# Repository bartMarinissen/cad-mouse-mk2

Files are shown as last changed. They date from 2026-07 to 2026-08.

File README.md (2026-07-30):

# CAD Mouse MK2 - The accuracy project.

This is a fork of the CAD Mouse MK2 project by SB-OCR.
The mouse as designed by him works out of the box, and is quite amazing. Except for one part: The motion tracking.

This project is an attempt to tackle this, and to bring the highest possible degree of accuracy to this mouse.
This degree of accuracy may be overkill. But why settle for less than the best you can get out of the hardware! (Note, if you do want to settle for less, there is a [[good enough]] trick below with already functioning code)

## The motion problem.
The bowels of this project are rather heavy on the mathematics. So we'll be stating the problem of trying to find the position of the knob in technical terms. We have 3 sensors arranged in a triangle. At rest, the magnets in the knob float about 6mm above those sensors. The magnets themselves are 6x6 cylinders (really they are 2 3x6 cylinders stacked on top of each other, but that doesn't matter). These 3 sensors measure the magnetic field in 3 directions, which yields 9 values. Based on these 9 values, we want to find a best guess for the 'pose' of the knob. Pose means both the position and orientation of the knob.
This is not an obvious problem. However, there is a related problem that is solvable. We call this one the forward problem.

"Given a pose $P$ of the knob, what magnet sensor readings should we expect".

If we can answer that question, then we can easily find the quality of a guess. We will then use some standard optmization techniques (the Newton-Gauss method) to find the best guess, or at least something very close to it. (Oh, and we want to do it at least 100 times a second on slow hardware that doesn't natively support floating point numbers) This leads to the real problem, also known as the backwards problem (because it goes the other way). in Plain langues, the question is: given the 9 magnet sensor readings, which pose of the knob best matches these readings".
To be precise, the backwards problem is:

"What pose minimizes the sum of the squares of the difference between the 9 sensor readings and the predicted sensor readings"

### Solving the forward problem
Awnsering the forward problem is pretty straightforward. We need to do two things: figure out the strength and direction of the magnetic field around a magnet. And then figure out how the pose of the sensor relative to that magnet. We can then figure out the field strength and direction of the magnetic field at the sensor, and how that direction aligns with the orientation of the sensor. The second part is 'just' some simple translations and rotations. (The bookkeeping gets complicated and tedious, but its not hard).

The first part, figuring out the strength and direction of the magnetic field around a magnet is a solved physics problem. So we 'just' need to poor that physics into some code. It turns out that this close to a magnet, the shape of the magnet actually matters so you can't solve it with a simple model (i.e. a dipole model). The exact solutions involve horrible things like closed form elliptical integrals. Not only are those annoying parts of math, they are also slow to calculate.

Instead of calculating the field strength fully from scratch, we precompute the field (and reduce it from 3D to 2D by exploiting the axial symmetry) at a few known places. Then when we want to know the field at an unknown place we interpolate between these known places.

In summary: figure out the pose of the sensor relative to the magnet. Then figure out the field strenth and direction at that position based on interpolating known data. Then figure out how the orientation of the sensor alligns with the magnetic field direction.

### Solving the backwards problem.
As stated, we use standard optimization techniques.

These are well researched, and they work quite well. The fast ones need:
- An initial guess
- A quick way to calculate the error (as a 9-element vector)
- The Jacobian of the error w.r.t the pose.
- (They need the error to behave 'nicely' as a function of the guess of the knob pose)

The initial guess is easy. Either take the rest position, thats good enough. Or even better, take your last guess for the knob position. The quick way to calculate the error is literally just the forward problem. We have that solved already.

But the Jacobian of the error? What even is that? Multi-variate calculus is what it is. The handwavy explanation is that it tells you how the error vector changes if you slightly change the guessed knob pose. More handwaving doesn't make sense, so I won't try.

To get this Jacobian, and for things to behave nicely. We need to do some math against out forward problem. This means we need the Jacobian of our interpolator, and we then need to use a whole lot of chain rule, product rule, and quotient rule (and some general linearity of the derivative) to turn that Jacobian into our final Jacobian. On top of that, we would really like for our Jacobian to vary smoothly with the guessed pose. This means we want our interpolator to not just be continuous, we also want it to be smooth. Hence we quickly land at some form of cubic splines. (The exact choise of spline is still under investigation)

These solvers then iteratively improve the guess for the pose by evaluating the current guess, and then using the Jacobian to estimate how best to reduce the error by changing the guess. They need a few iterations. And if the forward problem is well behaved (has no valleys or plateaus) then they get there very quickly. We expect at most 20 iterations, and hope for a lot less

### Performance
We need to solve the backwards problem 100s of times per second.
That means we need to solve the forwards problem close to 1000s of times per second.
That means performance matters.

More on that to come later.

### Calibration
We said the forward problem is easy. But its only easy if you know the details of your knob exactly. For now I am considering the following details salient, there is fractal amounts of detail here, so we need to draw a line somewhere:

- The magnet strengths (non-negotiable, this is the only way to find the Z axis data)
- The sensor sensitivity per axis. (They report a field strength in mT, but they are of by a fixed percentage)
- The sensor base offsets: The sensors don't read zero even if there are no magnets nearby, their offset is much larger than just the earths magnetic field)
- Sensor skew: the sensor axes aren't necessarily perfectly orthogonal.
- Errors in the magnet pose, and more especially rotation. (After all, this is 3d printed and the magnets are slip-fit)
- Errors in the sensor pose. (This is much less of a worry because PCBs are quite accurate)

Actually finding this is for another section. But we need to know these things so we can correct for them.

## Current state of the project
We have things working at about 50Hz using a single core based on bicubic interpolation.
There is very little callibration, and its hardcoded for my knob.
We get a residual of 4% Using the mouse it seems perfectly fine.

The code is a mess, its actively being modified, its not documented yet, most things are up for modification.

But smooth working at 50Hz and a 4% residual without callibration is already something I'm proud of!

## AI usage
There is heavy AI assistance. A lot of it for the tedium of getting the Jacobians. A decent amount of it for helping write the code. Most code starts out as AI generated and then gets shaped down to something I understand and agree with. Less critical code gets less attention. Especially if tests or experience just shows that it works.

## Build instructions
There are none for now. It should work out if you just use the instructions from the original.

At the moment, if you run into issues I'd love to help. Because it would be great to know someone else is using this. I do intend to add documentation 'later'. That is as much of a promise as you probably think it is (not a promise).

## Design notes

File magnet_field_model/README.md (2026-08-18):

# magnet_field_model

Offline Python for the magnetic side of the project: the field simulation that
generates the firmware's interpolation table, and the **bundle calibration**
that measures a specific unit's real geometry.

```
bicubic_table.py             the magnet model + grid the firmware's table is built from
generate_bicubic_table.py    entry point: (re)writes the firmware's table from bicubic_table.py
field_approximation.ipynb    inspection/visualization of that table - does not write it
bundle_callibration.py       entry point: capture a run, fit it, report
calibration/                 the calibration package (see below)
calibration_runs/            raw captured frames, as JSON
tests/                       pytest suite, one file per module - run after touching any math
```

## Running it

```bash
uv sync
uv run python generate_bicubic_table.py                    # (re)write the firmware's field table
uv run python bundle_callibration.py                       # live capture over serial
uv run python bundle_callibration.py --replay calibration_runs/raw_*.json
uv run python bundle_callibration.py --replay <run> --emit-cpp   # + firmware constants
uv run --group dev python -m pytest tests/ -q
```

A fit over a captured run is interactive -- seconds, not minutes.

## What bundle calibration is for

The knob has 3 magnets over 3 Hall sensors. The firmware infers pose by
inverting a magnetic forward model that assumes *nominal* geometry. Real
hardware misses nominal: a magnet sitting 0.2mm off, or a sensor 5% more
sensitive, looks to the solver like the knob moved. That is the "Phantom
Tilt" problem this fork exists to fix (see `../ARCHITECTURE.md`).

Calibration recovers, per unit:

| Group | Meaning |
|---|---|
| `magnet_pos` | in-plane shape of the magnet triangle (mm) |
| `magnet_tilt` | magnet axis tilt (rad) |
| `magnet_strength_mean` | common-mode polarization multiplier |
| `magnet_strength_diff` | how much individual magnets differ from it |
| `sensor_offset` | DC offset on the raw reading (mT) |
| `gain_aniso` | per-axis sensitivity spread |
| `gain_sym` | cross-axis skew |
| `gain_rot` | sensor frame misalignment |

Each group's size, and the flat vector's layout, is declared by `BLOCKS` /
`GROUP_SLICES` in `parameterization.py` — read the count there rather than
from a total written down here. Together with one free 6-DOF pose per captured
frame this is a bundle adjustment, in the photogrammetry sense. There is
deliberately no isotropic/scale gain parameter; see the gauge note below for
why sensor gain and magnet strength don't compete for the same degree of
freedom.

## Package layout

```
local_field.py         one magnet's axisymmetric field + its 3x3 gradient
nominal_geometry.py    pure nominal/CAD constants (no other package dependencies)
parameterization.py    the calibration parameter layout: how the flat vector scipy
                        sees maps to physical offsets (ParamBlock, GROUP_SLICES, assemble())
bundle_geometry.py     BundleGeometry: physical geometry + forward model + analytic Jacobian
bundle_params.py       priors, residual weighting, BundleCalibrationProblem, covariance
pose_solver.py         batched Levenberg-Marquardt: every frame's pose at once
calibration_algorithm.py  the fit that drives all of the above (single joint solve)
export.py              fitted geometry -> firmware constants
report.py              fitted result -> the Rich content the TUI and CLI show
protocol.py / serial_link.py / session.py / collector.py / tui.py   capture side
```

## Design notes

**Analytic Jacobian.** Every derivative in `bundle_geometry.py` is the same
closed-form chain rule the firmware uses in
`firmware/src/magnet_model/virtual_sensor.cpp`, layered on the local field gradient
from `local_field.py`. The previous version finite-differenced the entire
shared vector per frame — tens of thousands of magpylib calls per solver
iteration. `tests/test_jacobian.py` checks every derivative against central
differences, mirroring `firmware/test/test_jacobian.cpp`.

**Weighting.** A sensor's reading varies over nearly an order of magnitude
across a run, and the error budget is part absolute (read noise, measured on a
stationary knob) and part relative (unmodelled field-shape error) — the two
constants are declared on `ResidualWeights` in `bundle_params.py`. A flat
sigma therefore lets the close-to-the-magnet frames dominate.
`ResidualWeights` uses `hypot(absolute, relative * |B|)` per sensor per frame,
keyed off the **measured** magnitude — a weight that depended on the prediction
would bias the fit toward shrinking |B|.

**Single joint solve, not staging.** Every shared parameter is freed at once,
in one `least_squares` call. An earlier version froze parameters in a
warm-started ladder (gain scale and DC offset → magnet geometry → the weak
cross-axis gain terms) on the theory that a cold start needed the help.
Ablated against real and synthetic data — checking recovered parameters, not
just residual level, since a bad local optimum can still
converge to a low residual — a single unstaged solve reaches the same optimum
every time. `SolveStage`/`BundleCalibrationProblem.build_problem` still exist,
purely as a way to isolate a parameter subset for testing (e.g. "fit only
magnet strength, holding everything else at nominal").

**No isotropic gain term, ever.** Sensor gain scale and magnet strength
describe the same thing from opposite ends: a sensor reading 5% high and its
magnet being 5% strong differ only through cross-talk, which is a small
fraction of the signal and comparable to the model error
(`../TODO/resolved/cross-magnet-interference.md` owns that measurement). An earlier
version fixed this with a runtime pass — freeing an isotropic `gain_iso`
parameter and then transferring it into strength via a final `det(G)=1`
renormalization stage. That machinery is gone: `GAIN_BASIS`
(`parameterization.py`) is now built only from basis matrices that are exactly
traceless — asserted at import time, so the property is enforced rather than
documented — giving `det(I + A) = 1 - tr(A²)/2 + det(A) ≈ 1` for *any*
parameter value, automatically, to second order — good to the same precision
the old runtime transfer already tolerated. There is no competing scale
parameter for `magnet_strength` to wait behind, so it is free from the start of
the (single) solve, not a final phase.

**Pose solving.** Every frame's pose is solved in one batched
Levenberg-Marquardt rather than a Python loop, since the frames are
independent. A cold start occasionally drops a single frame into the wrong
basin — near a magnet and well tilted, the residual surface has a second
minimum a few degrees away — so any frame ending far worse than its peers is
retried from a spread of starting orientations. `converged` reflects the final
residual, not the damping factor: `calibration_algorithm.py` only fits frames
that passed this gate (evenly decimated down to a runtime cap — see
`DEFAULT_N_FRAMES` — not selected for diversity; a farthest-point frame
selector used to run here, but frame choice barely affects the result, so it
was deleted rather than kept for a benefit that wasn't there). The cap exists
because fitting every captured frame costs orders of magnitude more solver
time, at a much larger problem dimension, for no accuracy that ablation could
detect: the limit is systematic model error, not sample noise.

**Reported uncertainty.** Each frame's 6 pose parameters touch only that
frame's 9 residuals, so the pose block of the normal equations is
block-diagonal, and its contribution to the shared-parameter covariance can be
eliminated (the Schur complement). `BundleCalibrationProblem.covariance_shared`
computes this as `inv(J.T @ J)[:p, :p]` — a plain dense inverse sliced to the
shared block, reusing the same Jacobian the solver itself trusts, mathematically
identical to a hand-rolled per-frame elimination but far simpler at this
problem's actual size (a few hundred to a couple thousand unknowns, well under
a second). Reported as *information gain* = `1 - posterior/prior`. Low values
are not a bug — they mark parameters the data barely constrained, which is the
difference between measured and assumed.

## Assumptions

Recorded explicitly, because several are load-bearing:

1. **Magnet position reference is the BOTTOM FACE, not the centre.**
   `bicubic_table.py`'s `build_magnet()` places the cylinder at `z=+3` so its
   bottom face lands on `z=0`, so that is what `positions.h`'s magnet
   positions mean. magpylib positions a cylinder by its centre, so
   `local_field.py` adds the half-height. Getting this wrong shifts the model
   by that half-height and inflates the predicted field severalfold at rest —
   it is not a subtle error, but it is a silent one.
2. **The raw sensors' sign flip is attributed to magnet polarity, not gain.**
   The capture path streams `readUncorrected()`, and the raw sensors read the
   opposite sign to the field `local_field.py` models. The firmware carries
   that in `Config::magnet_gains` (see `Config.h` for the values); here
   `MAGNET_POLARITY = -1` carries it instead, so `local_field.py` stays a
   direct counterpart of the firmware's table and both fitted quantities read
   naturally (gain near `+I`, strength near `1`). The exported firmware gain
   still lands near `-I`. Which physical cause is the real one — magnets
   installed north-down, or an inverted sensor axis convention — does not
   matter to the fit, since a global sign is equivalent either way.
3. **Sensor positions are fixed, not calibrated.** They define the world
   frame. Real sensor placement error is absorbed by the magnet position
   offsets, which are related to it by a per-frame pose anyway.
4. **Magnet strength is split into common mode and differential, and the
   common mode carries no prior at all.** A prior would have to be centred on
   `local_field.py`'s nominal polarization (`MAGNET_POLARIZATION_MT`), which
   is a round guess rather than a measurement of these magnets — asserting a
   belief nobody holds, and
   dragging the fitted field scale toward an arbitrary number. So it is left
   free and reported with its own posterior sd.

   The consequence is the important part: **the data does not determine the
   absolute field scale.** Its posterior sd is wide enough that the fitted
   value sits inside 1σ of nominal, and the residual barely moves across that
   whole range. The direction is very nearly flat, because a uniform scale
   change is largely absorbable by every frame's pose moving further away, and
   only the shape of |B| versus distance breaks it — over the few mm of heave
   the mechanism allows, only barely. **Read the fitted strength as
   "unconstrained", not as a measurement of how strong the magnets are.**
   Dropping the prior did not reveal a better value; it revealed that there
   was never one to reveal.

   The *differential* part keeps its prior, because that justification is
   independent of the nominal figure: it says magnets cut from one batch are
   graded to roughly that of each other, which is a real belief about the
   parts. Empirically the constraint is nearly free — sweeping it over three
   orders of magnitude barely moves the residual, so per-magnet differences
   were never explaining much. The apparent per-sensor spread is accounted
   for by magnet position and DC offset instead.

5. **DC offset is applied on the raw side, after gain.** It is a property of
   the raw reading (Hall zero-point plus ambient field), not of the modelled
   field, so `pred = G @ B_model + offset`. The firmware subtracts its offset
   *after* gain instead, so the export maps `o_fw = G_fw @ o_fit`.
6. **Magnet spin about its own axis is not a parameter.** A uniformly
   axially-polarized cylinder is a solid of revolution, so that rotation is
   unobservable for *any* dataset — a structurally dead direction rather than
   a poorly-measured one. Tilt carries 2 DOF, not 3.
7. **The pose gauge is fixed explicitly, not by priors.** A global
   translation or rotation of the magnet trio is exactly cancelled by a
   compensating per-frame pose change — `mⱼ → Q mⱼ` with `R_n → R_n Qᵀ`
   leaves `R_n Qᵀ Q mⱼ = R_n mⱼ` untouched — so 6 of the 9 raw magnet
   coordinates carry no information at all — they show up as eigenvalues at
   machine zero in the reduced Hessian, at every frame count tried. No dataset
   fixes this; each new frame brings 9 equations but also 6 new pose unknowns.

   `MAGNET_POS_BASIS` removes them by construction, via three constraints:
   zero mean offset (kills translation), all z offsets equal (makes the
   triangle's plane horizontal, killing pitch and roll), and zero net yaw
   moment (kills twist, symmetrically rather than by pinning an edge). The
   flat constraint costs nothing — three points are always coplanar, so any
   arrangement can be rotated flat and the plane's tilt is pure gauge.

   What survives is 3 parameters: the triangle's in-plane shape, i.e. its
   three side lengths, which is the only part that can cause Phantom Tilt.
   Magnet tilts keep all 6 DOF, measured against the frame the flat triangle
   defines. (The rotation gauge is *shared* between positions and tilts, so
   it can be spent on either — fixing roll/pitch via mean tilt instead would
   give 5 position + 4 tilt. Total observable is 9 either way; only the
   presentation differs.)

   Two things this bought. Conditioning: the reduced Hessian goes from
   numerically singular to comfortably invertible. And frame count starts to
   matter at all — with priors off, cross-run spread now improves with more
   frames at close to the rate pure averaging predicts, where before the gauge
   fix it was flat. Null directions cannot be out-voted by data; merely weak
   ones can.

8. **Gain is fitted on the model side, exported inverted.** See
   `export.py` — the firmware applies gain to the raw measurement, this fit
   applies it to the model, so the exported matrix is the inverse (with
   `MAGNET_POLARITY` folded back in, landing near `-I`).

## Reading the fitted numbers

The fit's own report is the authority on what a given run achieved — residual,
posterior sds, and per-group information gain are printed for the run in front
of you rather than written down here, where they would rot.

Reading them: reproducibility is not the same as identifiability. The weakly
determined directions (magnet z-offset against gain scale, in particular)
reproduce consistently because the *prior* resolves them the same way every
time, not because the data measured them. The information-gain column is what
distinguishes the two, and a low value there is not a bug — it marks a
parameter the data barely constrained.

## Still open

- The `/calibration.bin` layout is no longer duplicated:
  `calibration/firmware_struct.py` extracts the `CalibrationParams`
  declaration straight out of `firmware/include/CalibrationParams.h` and hands
  it to cffi, so `format_binary()` fills the struct by field *name* and the
  order is only ever stated in the header. `tests/test_export.py` pins the
  resulting offsets and compiles the same extracted declaration with g++ to
  check cffi's ABI model against a real compiler. Both still only describe the
  *host* — the firmware's own `static_assert`s are what pin the target, and
  nothing here has run on hardware yet.
- Running the fit on the knob itself. The analytic Jacobian this needs is
  already here, and the firmware has the same chain rule in `virtual_sensor.cpp`. An
  on-device solve would need an O(n_frames) per-frame Schur elimination
  driving the actual solve (not just the reporting-only covariance
  `covariance_shared` computes today via a plain dense inverse, which is
  simpler at this problem's desktop-scale size but not embedded-friendly) —
  see git history for a prior implementation of that reduction. The storage
  half of that is done: a result fitted on the knob would have somewhere to
  land, via `CalibrationStorage`.
- Magnet strength stays weakly determined — its information gain is among the
  lowest in the fit. Scaling a magnet and moving it closer both scale |B|;
  only the shape of |B| versus distance separates them, and the HEAVE step
  supplies just a few mm of travel to do it with. More Z range would help, but
  the mechanism limits how much is available before the magnet leaves the
  modelled region.
- The `magnet_pos` prior is now optional rather than load-bearing. With the
  gauge fixed explicitly, dropping it entirely barely moves the cross-run
  spread and leaves the residual unchanged. It is kept (at the width declared
  in `priors.py`) because the knob is 3D printed and a few tenths of a
  millimetre is a well-founded statement about that process — unlike the
  nominal polarization figure. It is now a belief the fit could do without,
  which is the point of fixing the gauge properly, but it earns its place.
- The absolute field scale is not measurable from this capture — its posterior
  sd is a large fraction of the value itself. If it is worth knowing — and it
  would tighten the z sensitivity of the whole pose solve — it needs either
  much more heave travel
  or an independent measurement of one magnet's remanence. Note the boot tare
  cancels a systematic z bias, so the practical cost of getting it wrong is
  mostly a slightly mis-scaled z axis, not an offset.

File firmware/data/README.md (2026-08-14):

# `firmware/data/` — LittleFS image source

PlatformIO's `data_dir` (see `platformio.ini`). Everything in here gets built
into the LittleFS image that `pio run -t uploadfs` flashes onto the device.

The directory is tracked but its one real payload, `calibration.bin`, is not:
it is fitted per physical unit, so committing one would ship a single device's
calibration to every checkout. `.gitignore` in this directory keeps it out.

## Flashing a calibration this way

```bash
cd magnet_field_model
uv run python bundle_callibration.py --replay calibration_runs/raw_<run>.json --emit-bin
cd ..
pio run -t uploadfs
```

`--emit-bin` defaults to writing `firmware/data/calibration.bin`. It is
byte-for-byte the same blob the serial upload path sends, so both routes
produce a file the firmware reads identically — see
`firmware/include/CalibrationStorage.h` for the size and layout.

## The other route

`uploadfs` rewrites the whole filesystem and needs a rebuild-and-flash cycle.
To push a calibration to a device that is already running, use
`bundle_callibration.py --write-serial` instead: trigger a tare on the knob
(hold both buttons ~3s), and the script sends the same bytes over the wire
when the device announces `STATUS TARE_BEGIN`. The device validates, stores,
and reboots to pick it up.

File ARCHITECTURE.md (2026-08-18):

# CAD Mouse MK2 (accuracy fork) — Architecture Notes

Working reference for navigating and reasoning about this codebase. Written from
reading the code directly (not from any doc that could drift), so re-verify
specifics (function names, line numbers) before relying on them if it's been a
while — see `design documentation/context.md` for the *why*, this file is the
*where/how*.

**The repo root `README.md` is the maintainer's personal file, off-limits to
edits from this doc's audit/consistency-keeping loop** — it may be out of date.
That is not your problem to solve. And be careful with relying on it to be up to date.

## What this project is

A 6-DOF magnetic 3D mouse (fork of `sb-ocr/cad-mouse-mk2`): a knob embedded with
3 axially-polarized cylindrical magnets sits above 3 fixed Hall-effect sensors on
a PCB. Firmware infers the knob's full pose (X/Y/Z + pitch/roll/yaw) from the raw
magnetic field and reports it to the host as a USB HID multi-axis controller
(3Dconnexion-style), for CAD navigation.

The upstream project mapped raw field strength to position with a naive linear
heuristic. This fork rips that out and replaces it with a real magnetic
forward model + Gauss-Newton solver, because field strength doesn't map
linearly to distance.

## Three top-level areas

```
firmware/            PlatformIO/Arduino C++ — the actual product firmware
magnet_field_model/  Python (uv-managed) — offline field simulation + codegen
enclosure/           Fusion 360 / STEP / STL — mechanical design, not code
```

`platformio.ini` at repo root points PlatformIO at `firmware/{src,include,lib,test}`.
Board: Seeed XIAO RP2040 (dual-core Cortex-M0+, **no hardware FPU** — all float
math is software-emulated, which is why solver perf tuning matters: `-O2`,
`-fassociative-math`/`-freciprocal-math`/etc. relaxed-fp flags, `EIGEN_NO_MALLOC`
to force fixed-size Eigen types only, no heap allocation anywhere in the hot path).

## Firmware: control flow

`firmware/src/main.cpp` is the entry point. `setup()` brings up controllers in a
fixed order (HID → serial → input → LED → sensors → motion → telemetry), then
`stateMachine.changeState(&calibratingState)`. `loop()` calls
`hidController().task()`, then `serialController().update()` to assemble any
incoming serial line, then `stateMachine.update()` — a classic non-blocking
super-loop, no RTOS.

### State machine

[`firmware/include/State.h`](firmware/include/State.h) — trivial interface:
`enter()/update()/exit()`.
[`firmware/include/StateMachine.h`](firmware/include/StateMachine.h) /
[`.cpp`](firmware/src/StateMachine.cpp) — holds one `currentState*`, calls
`exit()`/`enter()` on transition. States are **static members of StateMachine**
(singletons, no dynamic allocation).

States, all in `firmware/{include,src}/states/`:

- **CalibratingState** — the tare step. Runs at boot and on the both-buttons-3s
  gesture from `IdleState`. Drives `SensorController::updateCalibration()` for
  `Config::ZERO_SAMPLES` (200) samples to compute a baseline field offset and a
  baseline pose, then hands off to `IdleState`. Also the *only* place serial
  commands are accepted: it announces `STATUS TARE_BEGIN` on entry, then honours
  `CAL_START` (enter `BundleState`) and `CAL_UPLOAD` (store a new calibration;
  `CAL_ABORT` leaves a run without storing, and is handled in `BundleState`)
  for the ~1.7s the tare lasts.
  [`TODO/tare-and-calibration.md`](TODO/tare-and-calibration.md).
- **IdleState** — the main operating state. Reads sensors → runs the pose solve →
  maps to HID axes → sends HID report → publishes telemetry → watches for the
  calibration-request gesture and the inactivity timeout to `SleepState`.
- **SleepState** — LEDs off, waits for any button activity to return to `IdleState`.
- **ErrorState** — entered if `SensorController::begin()` fails at boot. LED
  spinner in red, otherwise inert (no recovery path).
- **BundleState** — This is where actual callibration happens. We use bundle
  callibration and taring was called callibration. Hence the bad name. 
  This hosts the serial-driven multi-step hardware calibration
  routine (see "Calibration subsystem" below). Entered only from
  `CalibratingState` on `CAL_START`; `enter()` kicks the run off directly,
  since the command that got it there was already consumed.

### Controllers (global singletons, reached through accessors in `Controllers.h`)

Declared in [`firmware/include/Controllers.h`](firmware/include/Controllers.h)
and defined in `Controllers.cpp`. This is the project's entire DI mechanism —
there is no container, no interfaces, states and controllers reach each other
through these accessors directly.

**No controller owns another, and that is the whole ownership rule.** Every
controller is reached through its `Controllers.h` accessor, by states and by
other controllers alike; a controller calling a sibling's accessor is the
sanctioned pattern, not a coupling smell. There is no dependency hierarchy to
respect and nothing to invert. What is *not* allowed is bypassing the
accessors.

| Controller | File | Responsibility |
|---|---|---|
| `InputController` | `controllers/InputController.*` | Debounces 2 buttons via AceButton; exposes `buttonBits()`, `takeActivity()` (edge-triggered, consumed on read), `takeCalibrationRequest()` (both buttons held 3s) |
| `LEDController` | `controllers/LEDController.*` | NeoPixel ring: owns one `std::variant`-held `AnimationBase` slot (`animations/`) plus power management; callers `set()` a `SolidAnimation`/`SpinnerAnimation`/`OffAnimation`/`PoseColorAnimation` and drive it with `update()` each tick |
| `SensorController` | `controllers/SensorController.*` | Owns the 3 TLx493D sensor objects, power-sequences them onto distinct I2C addresses at boot, `readUncorrected()`/`read_mT()` → 9 floats, applies gain + DC offset, runs the boot baseline calibration |
| `MotionController` | `controllers/MotionController.*` | The pose pipeline: raw field → solved pose → filtered/mapped HID axes (detail below) |
| `HIDController` | `controllers/HIDController.*` | Owns the USB HID descriptor + report state, dedupes unchanged reports before sending |
| `TelemetryController` | `controllers/TelemetryController.*` | Formats a big fixed-layout ASCII dashboard to Serial every 20 ticks when `Config::ENABLE_TELEMETRY` |
| `BundleCalibrationController` | `controllers/BundleCalibrationController.*` | Serial-driven state machine for the guided hardware calibration capture |
| `SerialController` | `controllers/SerialController.*` | Assembles incoming bytes into whole lines without blocking; `takeLine()` hands the active state one line per tick. Transport only — command meaning stays with the caller, and outbound prints still go to `Serial` directly |

### Sensor read timing

The three TLI493D-A2B6s are **not** in their power-on-reset Low Power Mode
(160 Hz, ~6.25ms worst-case staleness). `SensorController::setup_sensor()`
puts each into **Master-Controlled Mode** (`setPowerMode`) with
**trigger-on-read** (`setTrigger(TLx493D_ADC_ON_READ_AFTER_REG_05_e)`), so
every `getMagneticFieldAndTemperature()` both returns the previous
measurement and re-arms the next conversion. Reading the three back-to-back
therefore costs about one I2C round-trip of staleness rather than a fixed
conversion period. The PCB forces this: all three `SCL/INT` pins share one
net wired only to the MCU's plain `SCL`, so there is no `/INT` line to
synchronize on and it has to happen over the bus itself.

worth knowing: **Self-triggering only works if reads keep happening.** After a >100ms gap
  the armed conversion is stale, so `readUncorrected()` throws away one round
  purely to re-trigger before reading for real. Bus stays at 400kHz
  deliberately; Master-Controlled Mode doesn't need Fast Mode, and raising it
  risks signal integrity across three sensors on fixed 1.2kOhm pull-ups.

The derivation behind this — datasheet rates, why the shared `SCL/INT` net
rules out interrupt-driven sync, why trigger-bits `100B` specifically — is
archived in
[`TODO/resolved/sensor-read-speed.md`](TODO/resolved/sensor-read-speed.md).

## The pose pipeline (the core of the project)

Entry point: `MotionController::compute()` in
[`MotionController.cpp`](firmware/src/controllers/MotionController.cpp), called
once per `IdleState::update()` tick.

```
SensorController::readRaw()          9 raw floats (3 sensors × xyz, mT)
        │
        ▼
MotionController::read_pose()        hot-started from last frame's (t, R)
        │
        ▼
solve_knob_pose()                    Levenberg-Marquardt Gauss-Newton, ≤10 iters
   (solve_pose.cpp)                  6x6 normal equations each iteration
        │  each iteration calls:
        ▼
ForwardModel::evaluate(t, R)         places each magnet in the world once,
   (forward_model.cpp)               then loops the 3 sensors
        │  per sensor, all 3 magnets:
        ▼
VirtualSensor::evaluate(...)         paired magnet via the interpolated field
   (virtual_sensor.cpp)              below; the other 2 via dipole_field().
        │                            Sums both, then composes the 3x6
        │                            Jacobian analytically once.
        ▼
MagnetModel::evaluate(v_local)       cylindrical (r,z) decomposition of the
   (magnet_local_model.cpp)          local offset, handles r→0 singularity
        │                            (paired magnet only)
        │
        ▼
BicubicField::evaluate(r, z)         Catmull-Rom bicubic interpolation over a
   (BicubicField.cpp)                51×91 precomputed grid, with ghost-point
        │                            linear extrapolation just past the edges
        ▼
BICUBIC_INTERPOLATION_TABLE          generated hex-float constants
   (magnet_model_table.cpp)          (see codegen pipeline below)
```

Output of the solve is `(position, rotation matrix)`; `extract_angles_robust()`
converts `R` to Euler angles with gimbal-lock handling. `compute()` then:
subtracts the calibration baseline pose, applies `Config::SIGN_AXIS` /
`Config::GAIN_T` / `Config::GAIN_R`, dead-zones, low-pass filters
(`Config::SMOOTH_TAU_S`), clamps to `Config::AXIS_LIMIT`, and writes the 6 HID
axis values.

**Why the Jacobian is hand-derived everywhere:** the solver needs a 9×6
Jacobian *every iteration*, and this runs on an FPU-less M0+, so it's all
closed-form analytic differentiation chained through each layer (no
finite-difference in the hot path). `firmware/test/test_jacobian.cpp` is a
Unity test suite that validates every one of these analytic Jacobians against
central finite differences — this is the safety net for that whole chain, run
it after touching any `evaluate()` in `magnet_model/`.

Geometry constants (sensor/magnet positions, triangle side length, 6mm z-standoff)
live in [`positions.h`](firmware/include/magnet_model/positions.h). Physical
constant: `#include "math3D.h"` for `Vec3`/`Mat3`/`skew_matrix` typedefs
(thin Eigen wrapper, `ArduinoEigenDense`).

### Codegen: Python → firmware table

`magnet_field_model/bicubic_table.py` (uv-managed Python env, `magpylib` for
ground-truth field simulation of a real 6×6mm N52 cylinder magnet) samples the
true field on the same 51×91 (r,z) grid defined by `NR`/`NZ` in
[`magnet_model_table.h`](firmware/include/magnet_model/magnet_model_table.h).
Run `magnet_field_model/generate_bicubic_table.py` to actually (re)write that
header and the hex-float C++ array in
[`magnet_model_table.cpp`](firmware/src/magnet_model/magnet_model_table.cpp) —
it imports the magnet/grid definitions from `bicubic_table.py` rather than
duplicating them. `field_approximation.ipynb` imports the same module to
inspect/visualize the table (field plots, dipole-approximation comparison,
interpolation error); it no longer writes the firmware files itself.
**The `magnet_model_table.cpp` file is generated, not hand-written** — if the magnet spec, grid bounds
(`BICUBIC_ORIGIN`/`BICUBIC_FAR` in `magnet_model_table.h`), or grid resolution
change, they need to change in both the notebook and the header in lockstep, by
hand. There's no build-time codegen step; it's a manual copy-paste pipeline.

## Calibration subsystem — two independent layers

**1. Tare (`CalibratingState`, always runs):** Measures the resting pose as 
a reference to report the movement of the knob.

**2. Bundle calibration (`BundleState` / `BundleCalibrationController`, new):** 
a guided multi-step capture routine intended to solve the
Phantom Tilt problem via bundle adjustment. Step sequence:
`STATIONARY → FLAT_CIRCLE → PITCH → ROLL → TWIST → HEAVE → RANDOM → COMPLETE`.
Each step is a little sub-state-machine (`CalibPhase`:
`WAIT_FOR_START_BTN → COUNTDOWN → RECORDING → WAIT_FOR_ACK`) that streams
`CAL_FRAME`/`CAL_STATE` lines over Serial to a host script,
[`bundle_callibration.py`](magnet_field_model/bundle_callibration.py), which
ACKs frame counts back over the same link. A successful ACK moves straight on
to the next step.

**Status: capture, fit, and delivery all work.** The Python side fits a set of
shared parameters (per-magnet position, tilt and strength; per-sensor gain
matrix and DC offset) jointly with one free 6-DOF pose per captured frame,
taking the field residual down by most of an order of magnitude against
nominal geometry, in about a second. The parameter groups and their sizes are
declared by `BLOCKS`/`GROUP_SLICES` in
`magnet_field_model/calibration/parameterization.py`.  See
[`magnet_field_model/README.md`](magnet_field_model/README.md) for the
architecture and the load-bearing frame conventions.

Two things are worth knowing before touching it:

- The magnet position reference is the magnet's **bottom face**, not its
  centre — that is what `positions.h` means and what the notebook baked into
  the bicubic table. magpylib positions cylinders by their centre.
- The raw capture path streams `readUncorrected()`, so the sensors might read the
  **opposite sign** to the modelled field — matching `Config::magnet_gains`
  . The fit attributes that flip to magnet polarity,
  so fitted gains read near `+I` while the *exported* ones land near `-I`.
- Sensor gain scale and magnet strength are not separable (only a few percent
  cross-talk distinguishes them), so the fit picks a gauge: `det(G) = 1`, with
  magnet strength carrying the scale. The reported strengths are an
  attribution, not a measurement — the fit's information-gain column says so.

### Persistence

Fitted calibrations reach the firmware on their own. The whole fitted
parameter set is one struct,
[`CalibrationParams`](firmware/include/CalibrationParams.h), and
[`CalibrationStorage`](firmware/include/CalibrationStorage.h) persists it to
LittleFS as `/calibration.bin`: 312 bytes of `CMK2` magic, a version, the
struct's own 300 bytes, and a CRC-32 over everything before it.

Reading one is a `memcpy` — check magic, version and CRC, copy the payload into
the struct, then range-check it. That works because `CalibrationParams` is
**plain arrays rather than Eigen types**, which buys three things at once:
`memcpy` into it is defined behaviour (`Eigen::Matrix` has a user-provided copy
constructor, so a struct of `Mat3`/`Vec3` is not trivially copyable), `sizeof ==
300` is a language guarantee instead of an observation, and the layout can be
**row-major** to match numpy rather than the column-major Eigen would impose —
a transposed gain matrix passes both the CRC and every plausibility check, so
that ordering is worth pinning down. Consumers convert with `toMat3()`/
`toVec3()` at construction, where they already copied the values out.

`board_build.filesystem_size` in `platformio.ini` carves out the partition —
without it the filesystem is 0MB and nothing mounts.

`SensorController` and `MotionController` are constructed from that struct and
hold their calibration-derived state `const`, which is why they are no longer
static-init globals — each is reached through its own Meyers-singleton
accessor, `sensorController()`/`motionController()`, built on first call from
`resolveCalibration()` (see [`Controllers.h`](firmware/include/Controllers.h)).
Every other controller is trivially default-constructible and has no such
dependency, so it gets a plain accessor over a static-init global instead —
same construction as before, just reached through a function for uniform call
syntax across all eight controllers. `resolveCalibration()` in
`Controllers.cpp` reads and validates the stored blob, falling back to
`Config::defaultCalibration()` — and printing which check failed — whenever
there is nothing stored or what is stored does not survive.

Validation is deliberately all-or-nothing, and that follows from the gauge
note above: `sensor_gain` and `magnet_strength_mT` are the same degree of
freedom under `det(G) = 1`, so a blob is accepted whole or rejected whole.
Nothing repairs or defaults an individual field while keeping the rest, which
would silently manufacture a mixed-gauge calibration worse than either input.
Past the CRC the checks are loose corruption tripwires — finite floats,
non-singular gain, sane magnitudes — sized to admit both that gauge and
`defaultCalibration()`'s different gain-carries-scale one. Magnet strength is
bounded on magnitude only: a reversed-polarity magnet legitimately fits to a
negative `Br`, and `MagnetModel` handles the sign correctly.

Two routes in, the same bytes either way:

- **`bundle_callibration.py --emit-bin`** writes the blob into `firmware/data/`;
  `pio run -t uploadfs` flashes it as a filesystem image.
- **`bundle_callibration.py --write-serial`** pushes it to a running device as
  one hex-encoded `CAL_UPLOAD` line. Hex rather than raw binary so it rides the
  same newline-delimited convention as everything else on this link — raw bytes
  would contain `0x0A` and truncate the read. The device validates, stores, and
  reboots, since the controllers hold their calibration `const` from boot and
  cannot adopt a new one in place.

The host never restates that layout. `calibration/firmware_struct.py` extracts
the `CalibrationParams` declaration from the header and feeds it to cffi in ABI
mode (no compiler at runtime), so `format_binary()` fills the struct by field
name and `sizeof` comes from the declaration rather than a literal. Field order
therefore lives in exactly one place. This matters because a wrong order is
silent: it still yields a valid blob with a valid CRC, and a *reordered* struct
is even the same 300 bytes — so `tests/test_export.py` pins the field offsets,
not just the size.

**The knob holds after capture.** Finishing the last pose moves it to
`AWAITING_UPLOAD` rather than back to `IdleState`: the host is about to solve
and hand a calibration straight back, and making the user walk the knob into
calibration mode again to receive it was the wrong shape. `CAL_UPLOAD` is
therefore accepted in `BundleState` as well as during tare.

**Storing is still a decision, not the only exit.** Capture and fit never touch
flash by themselves, and `CAL_ABORT` returns to idle without writing — also the
only escape from a run whose host went away, since `WAIT_FOR_ACK` otherwise
times out back to `WAIT_FOR_START_BTN` forever. The host sends it when
`--write-serial` was not passed (nothing is coming back, so the knob should not
be left parked) or when the user declines the write prompt.

Two caveats on the exported numbers:

- `MagnetModel` now carries a `magnet_strength_mT` — a real polarization value
  in mT, not a dimensionless multiplier — and applies it in `evaluate()`,
  scaling the six cylindrical quantities before the x/y decomposition (exact,
  since the field enters linearly downstream). The ratio it actually multiplies
  by is `magnet_strength_mT / BICUBIC_FIELD_REFERENCE_MT`
  (`magnet_model/magnet_model_table.h`): the polarization
  `magnet_field_model/bicubic_table.py` generated the table at, currently
  1000 mT and arbitrary — any magnet's real Br divided by it gives the right
  scale regardless of what that reference happens to be.
- Every sensor sees every magnet. Its own is evaluated through the
  interpolated field above; the other two, ~28.58mm away and worth 1.7–4.5%
  of the signal, through `dipole_field()`'s point-dipole approximation. The
  Python fit models the same three-magnet physics
  (`calibration/bundle_geometry.py`'s `SENSOR_MAGNET_COUPLING = ALL_MAGNETS`),
  so the fitted magnet strengths mean what they say rather than absorbing a
  cross term the firmware could not reproduce. The two are not bit-identical:
  the fit uses the exact cylinder solution where the firmware approximates,
  a difference under 0.02% of the field. See
  `TODO/resolved/cross-magnet-interference.md`.
- `VirtualSensor` no longer carries a gain; correction happens entirely in
  `SensorController::read_mT()` (issue #6 below).

## Quick file index

| Looking for... | Look in |
|---|---|
| Pins, gains, dead zones, LED colors, timing | `firmware/include/Config.h` |
| Board/build flags, lib deps | `platformio.ini` |
| Sensor geometry / knob geometry constants | `firmware/include/magnet_model/positions.h` |
| The Gauss-Newton solver loop | `firmware/src/magnet_model/solve_pose.cpp` |
| Per-sensor analytic Jacobian | `firmware/src/magnet_model/virtual_sensor.cpp` |
| Cylindrical magnet field model + r→0 handling | `firmware/src/magnet_model/magnet_local_model.cpp` |
| Bicubic grid interpolation | `firmware/src/magnet_model/BicubicField.cpp` |
| Generated field table (don't hand-edit) | `firmware/src/magnet_model/magnet_model_table.cpp` |
| Field table generator (run this to regenerate) | `magnet_field_model/generate_bicubic_table.py` |
| Field table magnet/grid definition (source of truth) | `magnet_field_model/bicubic_table.py` |
| Field table inspection/visualization (does not write it) | `magnet_field_model/field_approximation.ipynb` |
| HID descriptor / report format | `firmware/src/controllers/HIDController.cpp` |
| Serial diagnostics dashboard | `firmware/src/controllers/TelemetryController.cpp` |
| Jacobian correctness tests (finite-difference) | `firmware/test/test_jacobian.cpp` |
| New guided calibration flow | `firmware/src/controllers/BundleCalibrationController.cpp`, `firmware/src/states/BundleState.cpp`, `magnet_field_model/bundle_callibration.py` |
| Project intent / hardware spec | `design documentation/context.md` |
| Tracked follow-up work | `TODO/` |

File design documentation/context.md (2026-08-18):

**The Device and Its Purpose**
The device is a 6-Degrees-of-Freedom (6DOF) magnetic 3D mouse. It is designed to track the precise real-time pose—both the translation (X, Y, Z) and rotation (pitch, roll, yaw)—of a manipulatable knob. Devices like this are typically used as secondary input peripherals for navigating 3D space in CAD and modeling software.

**The Base Project**
Our work is based on an existing open-source repository: `sb-ocr/cad-mouse-mk2`. The firmware for this project is built on the Earle Philhower Arduino core and operates on a classic, non-blocking embedded "superloop" architecture. The base project successfully handles the peripheral tasks: hardware initialization, I2C/SPI bus management, LED ring control, and an asynchronous USB HID stack that formats and sends reports to the host PC at 100Hz–125Hz.

**The Hardware**

* **Microcontroller:** A Raspberry Pi RP2040 (a dual-core ARM Cortex-M0+). Notably, this chip lacks a hardware Floating Point Unit (FPU), meaning all floating-point math is handled in software.
* **Sensors:** 3x Infineon TLI493D-A2B6 3D Hall-effect sensors, which measure the magnetic flux density (in milliTeslas) across three axes and are read via an I2C bus. Datasheet and manual available in this dir.
* **Magnets:** 3x axially polarized 6x6mm cylindrical neodymium magnets.

**The Physical Layout**
The internal geometry relies on a 3-magnet, 3-sensor setup:

* The three magnets are embedded inside the movable knob, arranged in an equilateral triangle with a side length of approximately 2 cm.
* The three Hall-effect sensors are statically mounted on the PCB beneath the knob.
* When the knob is at its neutral, resting position, the sensors sit exactly 6 mm directly below their corresponding magnets.

**The Magnet Sizes and Properties**
The physical hardware relies on three **6x6mm cylindrical neodymium magnets** (rather low grade in my case) embedded in the knob.

* **Axial Polarization:** These cylinders are axially magnetized, meaning their north and south poles are located on the flat top and bottom circular faces. This is mathematically critical: it guarantees the magnetic field they project is radially symmetric around their local Z-axis, which allows the forward model (the 2D bicubic interpolator) to cleanly predict the field regardless of how the knob is twisted (yawed).

* **The Origin:** The fixed world origin `(0,0,0)` is located directly on the PCB, exactly at the center of the equilateral triangle formed by the three Hall-effect sensors. The world Z-axis points straight up toward the physical knob. The X axis is side to side (through the buttons); the Y axis is front to back (through the USB-C port) — see `firmware/include/Config.h`.

* **The frames** We have two frames: the world frame, and the knob frame. The sensors are in the world frame and don't move when the knob does. Their axes align with the axes explained above. The magnets are in the knob frame, and move with the knob they are positioned vertically (with their axis of symmetry parallel to Z). The nominal locations of the sensors and the magnets are recorded in `firmware/include/magnet_model/positions.h`. A calibration may record tiny ofsets on the locations and orientations of both. (as of writing, calibration records an offset and a rotation for the magnets)

**The PlatformIO Usage**
The firmware is written in C++ and uses **PlatformIO** (via the Earle Philhower Arduino core) as its build system rather than the standard Arduino IDE. PlatformIO is strictly necessary in this context because of the heavy mathematical load of the pose solver.

for claude:
A previous session concluded otherwise from a 403 on
  `api.github.com`, but the toolchain ships from
  `github.com/.../releases/download/`, a different host. Check with
  `pio pkg install` before believing you can't build.

* **Compiler Optimization:** The RP2040 lacks a hardware Floating Point Unit (FPU), so the heavy Gauss-Newton solver is entirely CPU-bound. PlatformIO’s `platformio.ini` configuration file lets us override default build flags; the current build uses `-O2` (up from Arduino's default size optimization `-Os`), and manages toolchain quirks (like avoiding unsupported Link-Time Optimization `-flto` flags, which break arduino-pico's soft-float symbol wrapping). `-O3` was measured (see `TODO/Performance.md`) to cut executed instructions further but costs several KB of RAM the interpolation table needs, so it's not the default.

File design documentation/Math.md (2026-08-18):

# Forward Model and Jacobian — the Mathematics Behind the Pose Solver

This document derives the mathematics of the 6DOF magnetic pose solver: the forward
model that predicts sensor readings from a candidate pose, and the exact analytic
Jacobian of that model, which drives a Levenberg-Marquardt (damped Gauss-Newton)
optimization loop.

The structure below follows the natural computational order — world pose, to local
geometry, to field lookup, to sensor output — so that each section corresponds to one
conceptual stage of the pipeline.

---

## 1. Notation

Indices: $i$ always denotes a **sensor**, $j$ always a **magnet**. Both run over
$\{1,2,3\}$. Every sensor sees every magnet, so most quantities below carry both.

| Symbol | Meaning |
|---|---|
| $\mathbf{s}_i$ | sensor $i$ position, world/PCB frame (constant) |
| $\mathbf{m}_j$ | magnet $j$ resting position (bottom face), knob frame (constant) |
| $R_{m,j}$ | magnet $j$'s tilt inside the knob (constant) |
| $G_i$ | sensor $i$'s gain/distortion matrix (constant) |
| $\mathbf{t}$ | knob translation, world frame (**solved for**) |
| $R$ | knob rotation matrix (**solved for**) |
| $\boldsymbol{\rho}=(\mathbf t,\boldsymbol\omega)$ | 6DOF pose coordinates: translation + rotation-update vector |
| $R(\boldsymbol\omega)=\exp([\boldsymbol\omega]_\times)$ | rotation as a function of $\boldsymbol\omega\in\mathfrak{so}(3)$ (Rodrigues) |
| $F,\,f_i$ | the forward model, overall and per-sensor (§2) |
| $B_j$ | the local magnet-field function for magnet $j$ (§3.3–3.4) |
| $R_{total,j} = R\,R_{m,j}$ | combined knob + magnet rotation |
| $\mathbf{v}_{l,ij}$ | sensor $i$'s position relative to magnet $j$, in magnet $j$'s local frame |
| $\mathbf{B}_{l,ij}$ | field at sensor $i$ from magnet $j$, in magnet $j$'s local frame |
| $\mathbf{B}_{w,ij}$ | field at sensor $i$ from magnet $j$, world frame (pre-gain) |
| $\mathbf{B}_{w,i}=\sum_j \mathbf{B}_{w,ij}$ | total field at sensor $i$, world frame (pre-gain) |
| $\hat{\mathbf{B}}_i$ | predicted sensor reading |
| $h$ | magnet half-height; the dipole sits this far above $\mathbf{m}_j$ along the magnet's axis (§3.6) |
| $\boldsymbol{\mu}_j$ | magnet $j$'s dipole moment, world frame (§3.6) |
| $\mathbf{c}_j$ | magnet $j$'s geometric centre, world frame (§3.6) |

Only $\mathbf{t}$ and $R$ are optimization variables. Everything else — $\mathbf{s}_i$,
$\mathbf{m}_j$, $R_{m,j}$, $G_i$ — is a frozen calibration constant, and so contributes
**zero** to every derivative below. That fact is used repeatedly to prune terms.

---

## 2. Functional Definition

The forward model is a single map from a 6-parameter pose to 9 predicted sensor
readings (three 3-axis sensors):

$$F:\mathbb{R}^6\to\mathbb{R}^9, \qquad F(\boldsymbol\rho) = \begin{bmatrix} f_1(\boldsymbol\rho)\\ f_2(\boldsymbol\rho)\\ f_3(\boldsymbol\rho)\end{bmatrix}$$

Its input $\boldsymbol\rho=(\mathbf t,\boldsymbol\omega)\in\mathbb{R}^3\times\mathbb{R}^3$
pairs the translation with a rotation-update vector, related to an actual rotation
matrix through the exponential map $R(\boldsymbol\omega)=\exp([\boldsymbol\omega]_\times)$.
Each $f_i:\mathbb{R}^6\to\mathbb{R}^3$ is the prediction for sensor $i$ alone. A sensor
sees **all three** magnets, and magnetic fields superpose, so it is a sum over $j$ of
the per-magnet composition of every stage in §3:

$$f_i(\boldsymbol\rho) = G_i \sum_{j} R(\boldsymbol\omega)R_{m,j}\; B_j\!\Big(R_{m,j}^T\big(R(\boldsymbol\omega)^T(\mathbf{s}_i-\mathbf{t})-\mathbf{m}_j\big)\Big)$$

where $B_j:\mathbb{R}^3\to\mathbb{R}^3$ — defined in §3.3–3.4 — maps a local query point
to the field magnet $j$ produces there.

**Where the sum sits matters.** Superposition is a property of the *field*, so the sum
has to be taken there, at $\mathbf{B}_w$, and not somewhere more convenient further out.
Everything downstream of it — the gain $G_i$, and both Jacobian blocks in §4.F — is
linear in the field, which is what lets the implementation add up the per-magnet
contributions first and apply the outer stages once per sensor rather than once per
pair. §4.F returns to this, because it is the step that makes nine (sensor, magnet)
pairs affordable.

The one term that is *not* a shared composition is $B_j$ itself. For the magnet a
sensor sits under it is the interpolated near field (§3.3–3.4); for the other two it is
a point dipole (§3.6). Which applies is fixed by the geometry, not chosen per
evaluation — see §3.6.

Note that $\boldsymbol\omega$ appears **twice**:
once rotating into the local frame ($R^T$, inside $B_j$'s argument) and once rotating
back out to world frame ($R$, outside). This is the reason the Jacobian derivation in §4 needs
the product rule rather than a single pass of the chain rule — both occurrences must be
differentiated and their contributions summed.

In practice, the solver never evaluates $F$ over the whole range of $\boldsymbol\rho$: at
each iteration it fixes a current estimate $(\mathbf t_0, R_0)$, treats $\boldsymbol\rho$
as a small *local* perturbation around it —

$$\mathbf{t}(\boldsymbol\rho)=\mathbf{t}_0+\Delta\mathbf{t}, \qquad R(\boldsymbol\rho) = \exp([\Delta\boldsymbol\omega]_\times)\,R_0$$

— and computes the Jacobian $J = D_{\boldsymbol\rho}F\big|_{\boldsymbol\rho=\mathbf 0} \in\mathbb{R}^{9\times6}$
of this local chart. That is precisely what §4 derives, and why it must be recomputed
freshly at every iteration rather than known once in closed form.

---

## 3. The Forward Model, Stage by Stage

This section unpacks $f_i$ from §2 into the sequence of physical steps that compute it,
one sensor/magnet pair at a time.

### 3.1 Combined rotation

The knob's rotation $R$ (the solved-for state) and the magnet's fixed tilt $R_{m,j}$
compose into a single rotation from the magnet-local frame to world frame:

$$R_{total,j} = R \, R_{m,j}$$

### 3.2 Local vector geometry

The vector from a magnet to its sensor is built up frame by frame, not in one jump: first
the sensor position is expressed in the knob's frame, then the magnet's own resting
offset is subtracted *in that frame*, and only then is the result rotated into the
magnet's own (possibly tilted) local frame:

$$\mathbf{v}_{l,ij} = R_{m,j}^T\Big(R^T(\mathbf{s}_i - \mathbf{t}) - \mathbf{m}_j\Big) = R_{total,j}^T(\mathbf{s}_i - \mathbf{t}) \;-\; R_{m,j}^T \mathbf{m}_j$$

The order matters for getting the right physical answer: $\mathbf{m}_j$ is subtracted
before the magnet-tilt rotation is applied, so the correct constant offset term is
$R_{m,j}^T\mathbf{m}_j$, not a bare $\mathbf{m}_j$.

### 3.3 Cylindrical query and interpolation

The magnets are axially polarized, so the field they produce is symmetric around their
own local axis and depends only on radius and height relative to that axis:

$$r = \sqrt{x_l^2+y_l^2}, \qquad z = z_l, \qquad \text{where } \mathbf{v}_{l,ij}=(x_l,y_l,z_l)$$

A precomputed, $C^1$-continuous bicubic interpolation table is queried at $(r,z)$,
returning the two cylindrical field components $B_r, B_z$ and their four spatial
partials $\partial B_r/\partial r$, $\partial B_z/\partial r$, $\partial B_r/\partial z$,
$\partial B_z/\partial z$.

### 3.4 Local field reconstruction

The scalar cylindrical field is rotated back into the 3D local Cartesian frame using
directional cosines $c_x = x_l/r$, $c_y = y_l/r$. Together, §3.3–3.4 constitute the
function $B_j$ from §2:

$$\mathbf{B}_{l,ij} = B_j(\mathbf{v}_{l,ij}) = \begin{bmatrix} B_r c_x \\ B_r c_y \\ B_z \end{bmatrix}$$

### 3.5 Back to world frame, then gain

The local field is rotated into the world frame, summed over magnets, then passed
through the sensor's own gain/distortion matrix to give the predicted sensor reading:

$$\mathbf{B}_{w,ij} = R_{total,j}\, \mathbf{B}_{l,ij}, \qquad \mathbf{B}_{w,i} = \sum_j \mathbf{B}_{w,ij}, \qquad \hat{\mathbf{B}}_i = f_i(\boldsymbol\rho) = G_i\, \mathbf{B}_{w,i}$$

(An additive sensor baseline/offset, if calibrated, is handled upstream as a
correction to the raw measurement rather than as a term in this model.)

### 3.6 The far-field branch — magnets a sensor does not sit under

§3.3–3.4 is the model for the magnet a sensor is paired with. The other two sit a
knob-triangle side away (28.58mm, `Positions::triangle_sidelength_mm`), far outside the
interpolation grid's domain, and are modelled as **ideal point dipoles**:

$$\mathbf{B} = \frac{1}{4\pi}\,\frac{3(\boldsymbol\mu\cdot\hat{\mathbf{r}})\hat{\mathbf{r}} - \boldsymbol\mu}{|\mathbf{r}|^{3}}$$

**This is the only approximation in this document.** Every other stage is exact given
its inputs; this one replaces a finite cylinder with a point. Its error is 0.14–0.40%
of the cross-magnet term at the geometry it is used at — and since that term is itself
1.7–4.5% of the signal, under 0.02% of the total field, comfortably below the ~0.3%
residual the fit achieves. The Python calibration model does *not* make this
approximation: it evaluates all nine pairs with the exact cylinder solution, which is
what the firmware's dipole is measured against.

Two details are load-bearing rather than incidental:

- **The dipole sits at the magnet's geometric centre**, not at $\mathbf{m}_j$. The local
  frame's origin is the magnet's *bottom face* (§3.2), so the centre is half a magnet
  higher **along the magnet's own axis**: $\mathbf{c}_j = \mathbf{t} + R\,(\mathbf{m}_j + R_{m,j}\,h\hat{\mathbf{z}})$.
  Placing it at the bottom face instead is a ~50% error at cross-magnet range, not a
  refinement.
- **The moment is the same magnet the table describes.** $|\boldsymbol\mu_j|$ is the
  reference moment (polarization × volume, in mT·mm³) scaled by the same per-magnet
  strength ratio that scales the interpolated field, so the near and far models cannot
  describe magnets of different strength. Polarization runs along the magnet's local
  $-\hat{\mathbf{z}}$, so in world coordinates $\boldsymbol\mu_j = -|\boldsymbol\mu_j|\,R_{total,j}\,\hat{\mathbf{z}}$
  — the third column of $R_{total,j}$, scaled.

**Which branch applies is fixed by geometry, not measured per evaluation.** Over the
knob's full travel the paired magnet never exceeds ~12mm from its own centre and the
cross magnets never come closer than ~25mm, so the two regimes cannot overlap and there
is nothing to test at runtime. This is why no blending between the models is needed:
the gap between them is never visited.

Unlike §3.3–3.4 this branch is **frame-agnostic**. A magnet's orientation reaches the
formula entirely through $\boldsymbol\mu$, a single vector, so supplying $\boldsymbol\mu_j$
and $\mathbf{r} = \mathbf{s}_i - \mathbf{c}_j$ in world coordinates yields the world
field and (§4.E) the world gradient directly — no rotation into the magnet's frame and
no rotation back. The interpolated branch has no such freedom: it is tabulated in
$(r,z)$ and must be handed magnet-local coordinates.

---

## 4. Jacobian Derivation

**Goal:** find $J_{trans}, J_{rot}$ (each $3\times3$, per sensor) — together forming the
$3\times 6$ block $D_{\boldsymbol\rho}f_i$ of $J=D_{\boldsymbol\rho}F$ from §2 — such that
a small pose change produces a first-order change in the predicted reading:

$$\Delta\hat{\mathbf{B}}_i = J_{trans}\,\Delta\mathbf{t} + J_{rot}\,\Delta\boldsymbol{\omega}$$

The strategy is to work **outside-in**: take the variation of each layer in §3 in turn,
and substitute inward until only $\Delta\mathbf{t}$ and $\Delta\boldsymbol{\omega}$
remain.

Two skew-symmetric identities recur throughout. They follow from the convention that a
small rotation update is a **left** (world/spatial) perturbation of the current
rotation: $R_{new}=\exp([\Delta\boldsymbol{\omega}]_\times)R \approx (I+[\Delta\boldsymbol{\omega}]_\times)R$.

- **Identity 1** (cross-product anticommutativity): for any vectors $\mathbf{a},\mathbf{b}$: $[\mathbf{a}]_\times \mathbf{b} = -[\mathbf{b}]_\times \mathbf{a}$
- **Identity 2** (rotation variation): $\Delta R \approx [\Delta\boldsymbol{\omega}]_\times R$, and consequently, from $R^TR=I \Rightarrow \Delta(R^T)R + R^T\Delta R = 0$:

$$\Delta(R^T) = -R^T\,\Delta R\,R^T = -R^T[\Delta\boldsymbol{\omega}]_\times$$

### 4.A Outer layer — gain (trivial)

$G_i$ is a frozen constant, so it passes straight through:

$$\Delta\hat{\mathbf{B}}_i = G_i\, \Delta\mathbf{B}_{w,i}$$

### 4.B Middle layer — world field variation

§4.B–4.D take **one** (sensor, magnet) pair at a time, through the interpolated branch.
§4.E does the same for the far-field branch, and §4.F sums the results over $j$.

From $\mathbf{B}_{w,ij}=R_{total,j}\mathbf{B}_{l,ij}$, the product rule gives:

$$\Delta\mathbf{B}_{w,ij} = (\Delta R_{total,j})\,\mathbf{B}_{l,ij} + R_{total,j}\,\Delta\mathbf{B}_{l,ij}$$

$R_{m,j}$ is constant, so $\Delta R_{total,j} = (\Delta R)R_{m,j} = [\Delta\boldsymbol{\omega}]_\times R\, R_{m,j} = [\Delta\boldsymbol{\omega}]_\times R_{total,j}$ (Identity 2). Substituting, then applying Identity 1 with $\mathbf{a}=\Delta\boldsymbol{\omega}$, $\mathbf{b}=\mathbf{B}_{w,ij}=R_{total,j}\mathbf{B}_{l,ij}$:

$$[\Delta\boldsymbol{\omega}]_\times \mathbf{B}_{w,ij} = -[\mathbf{B}_{w,ij}]_\times \Delta\boldsymbol{\omega}$$

$$\Rightarrow \quad \Delta\mathbf{B}_{w,ij} = -[\mathbf{B}_{w,ij}]_\times \Delta\boldsymbol{\omega} + R_{total,j}\,\Delta\mathbf{B}_{l,ij}$$

### 4.C Inner layer — local vector variation

The local field's variation is driven by the local query vector, via the analytic
Jacobian of §4.D:

$$\Delta\mathbf{B}_{l,ij} = J_{local}\,\Delta\mathbf{v}_{l,ij}$$

From $\mathbf{v}_{l,ij} = R_{total,j}^T(\mathbf{s}_i-\mathbf{t}) - R_{m,j}^T\mathbf{m}_j$, and since the
$R_{m,j}^T\mathbf{m}_j$ term is entirely constant, only the first term varies:

$$\Delta\mathbf{v}_{l,ij} = \Delta(R_{total,j}^T)(\mathbf{s}_i-\mathbf{t}) + R_{total,j}^T(-\Delta\mathbf{t})$$

Let $\mathbf{v} = \mathbf{s}_i - \mathbf{t}$. Note this depends on the sensor only, **not**
on the magnet — all three magnets ride the same rigid knob — which is what §4.F later
exploits to pull the rotation block out of the sum over $j$.
Using Identity 2, then Identity 1 with $\mathbf{a}=\Delta\boldsymbol{\omega}$,
$\mathbf{b}=\mathbf{v}$:

$$\Delta(R_{total,j}^T)\,\mathbf{v} = -R_{total,j}^T[\Delta\boldsymbol{\omega}]_\times \mathbf{v} = R_{total,j}^T[\mathbf{v}]_\times \Delta\boldsymbol{\omega}$$

$$\Rightarrow \quad \Delta\mathbf{v}_{l,ij} = R_{total,j}^T[\mathbf{v}]_\times\,\Delta\boldsymbol{\omega} \;-\; R_{total,j}^T\,\Delta\mathbf{t}$$

*(Remark: had we instead used the simpler-looking but incomplete $\mathbf{v}_{l,ij}=R_{total,j}^T(\mathbf{s}_i-\mathbf{t})-\mathbf{m}_j$ from §3.2, the derivative would come out identical — differentiating any constant term, whatever its exact form, always contributes zero. The correction in §3.2 matters for the field value, not for the Jacobian.)*

### 4.D $J_{local}$ — the cylindrical-to-Cartesian chain rule

This is the one link in the chain not handled by rigid-body identities — it's a genuine
multivariable chain rule through $r=\sqrt{x_l^2+y_l^2}$.

We need $\partial(\mathbf{B}_l)_a/\partial x_j$ for $a,j \in \{x_l,y_l,z_l\}$, with
$\mathbf{B}_l = (B_r c_x,\; B_r c_y,\; B_z)$, $c_x=x_l/r$, $c_y=y_l/r$, and $B_r,B_z$
functions of $(r,z_l)$ only. First, the geometric partials of $r$ itself:

$$\frac{\partial r}{\partial x_l} = \frac{x_l}{r} = c_x, \qquad \frac{\partial r}{\partial y_l}=c_y, \qquad \frac{\partial r}{\partial z_l}=0$$

**Row 1** ($B_x = B_r(r,z_l)\cdot x_l/r$), by the product rule:

$$\frac{\partial B_x}{\partial x_l} = \underbrace{\frac{\partial B_r}{\partial r}c_x}_{\text{chain rule thru } r}\cdot c_x \;+\; B_r\,\frac{\partial}{\partial x_l}\!\left(\frac{x_l}{r}\right)$$

The second term needs the quotient rule: $\partial(x_l/r)/\partial x_l = (r - x_l c_x)/r^2$.
Using $x_l c_x = x_l^2/r$ and $r^2=x_l^2+y_l^2$:

$$r - x_l c_x = r - \frac{x_l^2}{r} = \frac{r^2-x_l^2}{r} = \frac{y_l^2}{r} \quad\Rightarrow\quad \frac{\partial}{\partial x_l}\!\left(\frac{x_l}{r}\right) = \frac{y_l^2}{r^3} = \frac{c_y^2}{r}$$

So:

$$\frac{\partial B_x}{\partial x_l} = \frac{\partial B_r}{\partial r}c_x^2 + \frac{B_r}{r}c_y^2$$

The off-diagonal term follows the same pattern (product rule + quotient rule, this time
$\partial(x_l/r)/\partial y_l = -x_l y_l/r^3 = -c_xc_y/r$):

$$\frac{\partial B_x}{\partial y_l} = \frac{\partial B_r}{\partial r}c_xc_y - \frac{B_r}{r}c_xc_y = \left(\frac{\partial B_r}{\partial r}-\frac{B_r}{r}\right)c_xc_y$$

and, since $c_x$ has no $z_l$-dependence:

$$\frac{\partial B_x}{\partial z_l} = \frac{\partial B_r}{\partial z}c_x$$

**Row 2** ($B_y=B_r c_y$) is identical by the $x_l\leftrightarrow y_l$ symmetry of $r$, giving
the mirrored entries (note $\partial B_x/\partial y_l = \partial B_y/\partial x_l$ — the
top-left $2\times2$ block is symmetric).

**Row 3** ($B_z(r,z_l)$, no directional cosine to differentiate) is a plain chain rule
through $r$:

$$\frac{\partial B_z}{\partial x_l} = \frac{\partial B_z}{\partial r}c_x, \qquad \frac{\partial B_z}{\partial y_l} = \frac{\partial B_z}{\partial r}c_y, \qquad \frac{\partial B_z}{\partial z_l} = \frac{\partial B_z}{\partial z}$$

Assembled:

$$J_{local} = \begin{bmatrix}
\dfrac{\partial B_r}{\partial r}c_x^2+\dfrac{B_r}{r}c_y^2 & \left(\dfrac{\partial B_r}{\partial r}-\dfrac{B_r}{r}\right)c_xc_y & \dfrac{\partial B_r}{\partial z}c_x \\[1.2em]
\left(\dfrac{\partial B_r}{\partial r}-\dfrac{B_r}{r}\right)c_xc_y & \dfrac{\partial B_r}{\partial r}c_y^2+\dfrac{B_r}{r}c_x^2 & \dfrac{\partial B_r}{\partial z}c_y \\[1.2em]
\dfrac{\partial B_z}{\partial r}c_x & \dfrac{\partial B_z}{\partial r}c_y & \dfrac{\partial B_z}{\partial z}
\end{bmatrix}$$

**Singularity at $r=0$:** every off-diagonal term above has an explicit $1/r$
(inside $B_r/r$ or the $c_xc_y$ products), so naive evaluation blows up on-axis. But
physically the field must stay smooth there, and $B_r/r \to \partial B_r/\partial r$ as
$r\to0$ (L'Hôpital, since $B_r(0,z)=0$ by the magnet's axial symmetry — no radial field
component on the axis itself). Substituting this limit collapses the whole matrix: the
$c_xc_y$ off-diagonal terms vanish (finite $\times$ $r\to0$ factor), and the top-left
$2\times2$ block becomes an isotropic $\partial B_r/\partial r \cdot I$:

$$J_{local}\big|_{r=0} = \operatorname{diag}\!\left(\frac{\partial B_r}{\partial r},\ \frac{\partial B_r}{\partial r},\ \frac{\partial B_z}{\partial z}\right)$$

### 4.E $J_{dipole}$ — the far-field Jacobian

The §3.6 branch needs its own analytic derivative. Writing $\rho=|\mathbf{r}|$,
$k=1/4\pi$, and expanding $\hat{\mathbf{r}}=\mathbf{r}/\rho$ so the powers are explicit:

$$\mathbf{B} = k\Big[3(\boldsymbol\mu\cdot\mathbf{r})\,\mathbf{r}\,\rho^{-5} - \boldsymbol\mu\,\rho^{-3}\Big]$$

Differentiating component-wise, using $\partial(\boldsymbol\mu\cdot\mathbf{r})/\partial r_b = \mu_b$,
$\partial r_a/\partial r_b=\delta_{ab}$, and $\partial\rho^{-n}/\partial r_b = -n\,r_b\,\rho^{-n-2}$:

$$\frac{\partial B_a}{\partial r_b} = k\Big[3\rho^{-5}\big(\mu_a r_b + r_a \mu_b + (\boldsymbol\mu\cdot\mathbf{r})\delta_{ab}\big) - 15(\boldsymbol\mu\cdot\mathbf{r})\,\rho^{-7} r_a r_b\Big]$$

or in matrix form:

$$J_{dipole} = k\Big[3\rho^{-5}\big(\boldsymbol\mu\mathbf{r}^T + \mathbf{r}\boldsymbol\mu^T + (\boldsymbol\mu\cdot\mathbf{r})I\big) - 15(\boldsymbol\mu\cdot\mathbf{r})\rho^{-7}\,\mathbf{r}\mathbf{r}^T\Big]$$

**$J_{dipole}$ is symmetric**, visibly so: every term above is invariant under
$a\leftrightarrow b$. That is not a coincidence of this algebra but a physical
requirement — away from its source the field is curl-free, so it is the gradient of a
scalar potential and its Jacobian is (minus) that potential's Hessian. The
implementation computes six entries and mirrors three on exactly this basis, and
`test_dipole_field_jacobian` asserts the symmetry so that an edit breaking it fails
loudly rather than producing a plausible-looking solver.

Because §3.6 is evaluated in the world frame, $J_{dipole}$ **is** that magnet's
contribution to $M$ below — there is no $R\,J\,R^T$ congruence to apply.

### 4.F Assembly — folding it all back together

Substitute §4.C's $\Delta\mathbf{v}_{l,ij}$ into $\Delta\mathbf{B}_{l,ij}=J_{local}\Delta\mathbf{v}_{l,ij}$, then into §4.B, for one magnet $j$:

$$\Delta\mathbf{B}_{w,ij} = -[\mathbf{B}_{w,ij}]_\times\Delta\boldsymbol{\omega} + R_{total,j}J_{local}\Big(R_{total,j}^T[\mathbf{v}]_\times\Delta\boldsymbol{\omega} - R_{total,j}^T\Delta\mathbf{t}\Big)$$

Define that magnet's field gradient in the world frame:

$$M_{ij} = R_{total,j}\,J_{local}\,R_{total,j}^T \quad\text{(interpolated branch)}, \qquad M_{ij} = J_{dipole} \quad\text{(§3.6 branch, already in the world frame)}$$

Distributing and grouping by $\Delta\mathbf{t}$ / $\Delta\boldsymbol{\omega}$, then summing
over magnets — note $\mathbf{v} = \mathbf{s}_i-\mathbf{t}$ carries no $j$, since all three
magnets ride the same rigid knob:

$$\Delta\mathbf{B}_{w,i} = \sum_j \Delta\mathbf{B}_{w,ij} = \underbrace{\Big(-\sum_j M_{ij}\Big)}_{\text{translation}}\Delta\mathbf{t} + \underbrace{\Big(\Big(\sum_j M_{ij}\Big)[\mathbf{v}]_\times - \Big[\sum_j \mathbf{B}_{w,ij}\Big]_\times\Big)}_{\text{rotation}}\Delta\boldsymbol{\omega}$$

**Summing before assembling is exact, not an approximation**, and it is the step that
makes cross-magnet modelling affordable. Both blocks are linear in $M_{ij}$ and
$\mathbf{B}_{w,ij}$, and $[\,\cdot\,]_\times$ is linear in its argument, so
$\sum_j$ commutes with everything outside it. The consequence is that the skew products
and block assembly run **once per sensor** rather than once per (sensor, magnet) pair —
three times per evaluation instead of nine.

Folding in the gain from §4.A gives the final $3\times3$ blocks, with
$M_i = \sum_j M_{ij}$ and $\mathbf{B}_{w,i} = \sum_j \mathbf{B}_{w,ij}$:

$$J_{trans} = G_i(-M_i), \qquad J_{rot} = G_i\big(M_i[\mathbf{v}]_\times - [\mathbf{B}_{w,i}]_\times\big)$$

**Crucial detail:** $[\mathbf{B}_{w,i}]_\times$ must be built from the pre-gain, physical
field $\mathbf{B}_{w,i}$, *before* $G_i$ is applied — it appears inside §4.B, ahead of
§4.A's gain step, so using the gained field here would be a subtly wrong Jacobian even
though the residual itself is computed post-gain. It must also be the **summed** field:
using the paired magnet's contribution alone would drop the cross terms from the
rotation block while keeping them in the prediction.

### 4.G Stacking to 9×6

Each sensor's $3\times6$ block $D_{\boldsymbol\rho}f_i = [\,J_{trans,i}\;\;J_{rot,i}\,]$
— now summed over all three magnets, per §4.F — occupies its own three rows of the
shared $9\times6$ matrix $J=D_{\boldsymbol\rho}F$ from §2. All three sensors share the
same $\mathbf{t}, R$ (and hence the same $\Delta\mathbf{t}, \Delta\boldsymbol{\omega}$
columns), since they observe one rigid knob:

$$J = \begin{bmatrix} J_{trans,1} & J_{rot,1} \\ J_{trans,2} & J_{rot,2} \\ J_{trans,3} & J_{rot,3} \end{bmatrix} \in \mathbb{R}^{9\times6}$$

---

## 5. The Solve Loop

Each iteration of the pose solver performs one Levenberg-Marquardt step:

1. **Residual:** $\mathbf{r} = F(\boldsymbol\rho) - \mathbf{B}_{measured} \in\mathbb{R}^9$, evaluated at the current pose estimate ($\boldsymbol\rho=\mathbf 0$ in the local chart of §2).
2. **Damped normal equations:** $H = J^TJ + \lambda I$, $\ \mathbf{g}=-J^T\mathbf{r}$ — the
   $\lambda I$ term is what makes this Levenberg-Marquardt rather than plain Gauss-Newton,
   keeping $H$ invertible even when $J$ is rank-deficient (e.g. near $r=0$ or degenerate
   poses).
3. **Solve** the $6\times6$ system $H\,\Delta\boldsymbol{\rho} = \mathbf{g}$, giving
   $\Delta\boldsymbol{\rho}=(\Delta\mathbf{t},\Delta\boldsymbol{\omega})$.
4. **Convergence check** on $\|\Delta\boldsymbol{\rho}\|^2$ against a small tolerance.
5. **Apply the update**, which re-centers the local chart at the new estimate:
   $$\mathbf{t} \mathrel{+}= \Delta\mathbf{t}, \qquad R \leftarrow \exp([\Delta\boldsymbol{\omega}]_\times)\,R$$
   The derivation in §4 used the *first-order* approximation
   $\Delta R\approx[\Delta\boldsymbol{\omega}]_\times R$ (Identity 2), valid for
   infinitesimal steps; the actual update instead applies the *exact* matrix exponential
   so that a finite-sized step still leaves $R$ exactly orthogonal, with no
   re-orthonormalization needed. The next iteration then repeats §2's linearization
   around this new $(\mathbf t, R)$.

---

## 6. Validation

Every analytic piece above — the interpolation table's partials, $J_{local}$ (including
the $r=0$ branch), $J_{dipole}$, and the full $9\times6$ forward-model Jacobian — can be,
and should continue to be, checked against central finite differences swept over a grid
of poses, sensor gains, and magnet tilts. Perturbing $R$ with the exact matrix exponential
$\exp([\mathbf{w}]_\times)$ (not the first-order $I+[\mathbf{w}]_\times$) for the
rotation columns is important here: using the same first-order approximation on both
sides would let a shared error hide from the comparison.

Two things finite differences **cannot** catch here, both because they compare the model
against its own derivative and so are blind to the model being consistently wrong:

- **A wrong dipole moment or a misplaced dipole.** Either produces a smooth, entirely
  self-consistent field of the wrong magnitude. What catches it is comparing the two
  branches against each other where both are valid — the §3.6 dipole against the §3.3–3.4
  table at the far edge of the grid's domain, since they are supposed to describe the
  same physical magnet.
- **The cross-magnet terms being absent altogether.** A model with $\sum_j$ silently
  reduced to the paired magnet is a perfectly differentiable model. What catches it is
  asserting the cross contribution is present and of the measured size (1.7–4.5% of the
  field).

`firmware/test/test_jacobian.cpp` carries all of the above.

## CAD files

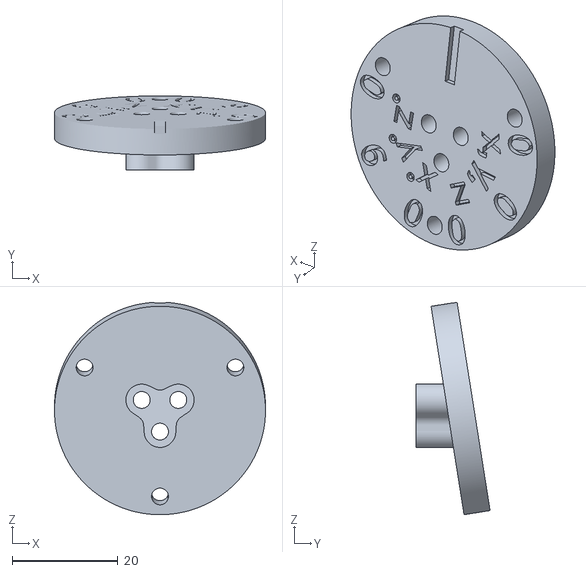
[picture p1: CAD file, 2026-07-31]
enclosure/callibration_stems/rot_y_9.stl
40.0 x 14.1 x 40.3

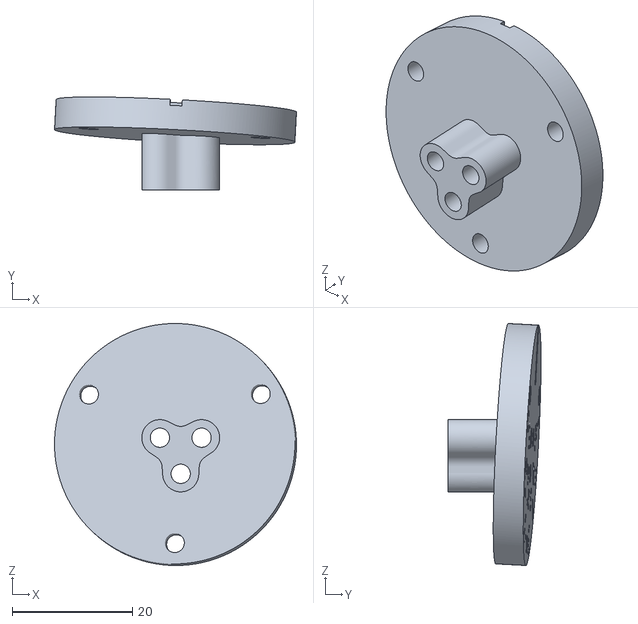
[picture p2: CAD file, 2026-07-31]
enclosure/callibration_stems/twisted_compound.stl
40.2 x 15.5 x 40.2

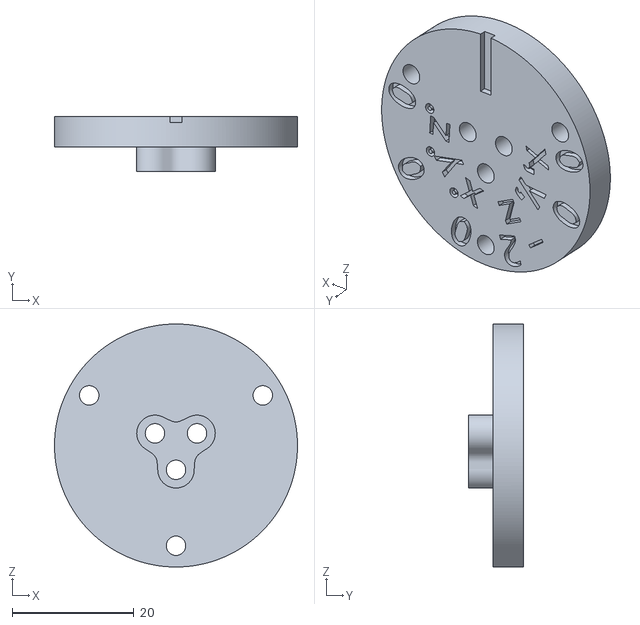
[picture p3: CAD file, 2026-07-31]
enclosure/callibration_stems/trans_z_-2.stl
40.0 x 9.00 x 40.0

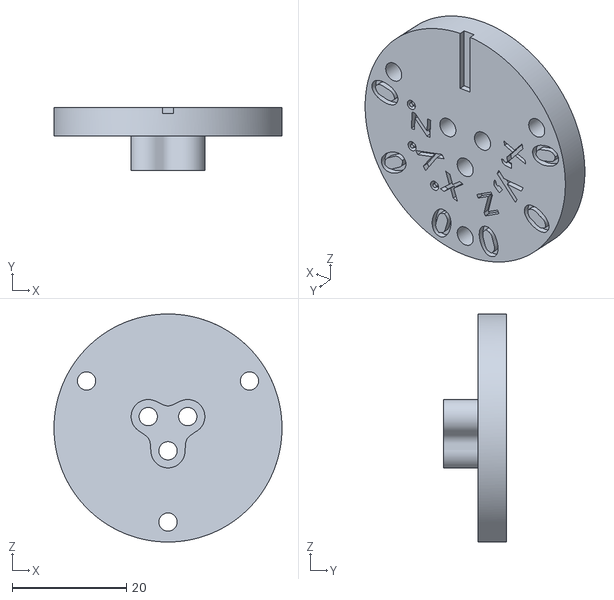
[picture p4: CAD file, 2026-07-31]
enclosure/callibration_stems/origin.stl
40.0 x 11.0 x 40.0

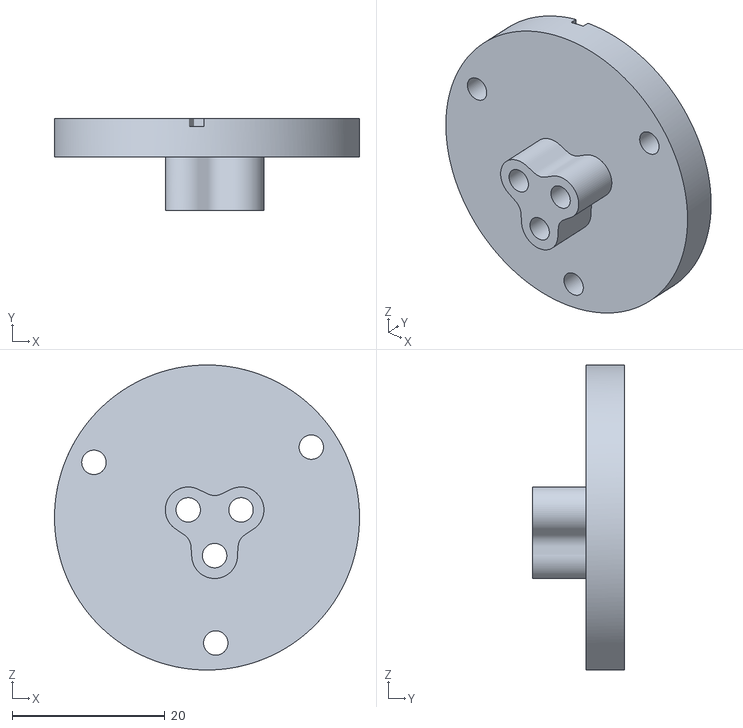
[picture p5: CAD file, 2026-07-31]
enclosure/callibration_stems/flat_compound.stl
40.0 x 12.0 x 40.0

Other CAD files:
enclosure/callibration_stems/rot_x_9.stl
enclosure/callibration_stems/trans_x_-2.stl
enclosure/callibration_stems/trans_y_2.stl
enclosure/callibration_stems/rot_z_7.stl

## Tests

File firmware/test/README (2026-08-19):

# firmware/test/ — PlatformIO Unit Tests

Run with:

```bash
pio test -e seeed_xiao_rp2040_test
```

That environment extends the normal build but unsets `-DNDEBUG`, restoring
standard-library `assert()` checks while testing (historically this also
kept Eigen's `eigen_assert` bounds checks live; since
TODO/eigen-to-bla-migration.md, BLA has no runtime assertions at all --
`operator()` does raw, unchecked array indexing -- so there's nothing
Eigen-specific left for this to unlock). `test_build_src = yes`, so the
tests link against the real firmware sources rather than a stub.

## Why `test_jacobian.cpp` matters more than a typical unit test

The pose solver needs a 9x6 Jacobian of the forward model on every
Levenberg-Marquardt iteration, on a microcontroller with no hardware FPU.
Finite-differencing it in the hot path is far too expensive, so **every
derivative in the chain is hand-derived closed-form algebra** — see
`design documentation/Math.md` for the derivation and `ARCHITECTURE.md` for
where each layer lives.

Hand-derived derivatives fail silently. A sign error or a dropped term in a
Jacobian does not crash and does not obviously break the output: the solver
still converges, just more slowly, to a slightly wrong pose, or it becomes
unstable only in poses you didn't happen to try. Nothing else in the project
will catch it.

`test_jacobian.cpp` is that check. It compares each analytic Jacobian against
central finite differences of the same function, layer by layer:

1. `BicubicField::evaluate()` — the `d_dr`/`d_dz` partials it returns
2. `MagnetModel::evaluate()` — `J_local = dB_l/dv_l`, including the r=0
   axis branch where the general formula's `1/r` terms are singular
3. `ForwardModel::evaluate()` — the full 9x6, translation and rotation blocks,
   swept over a grid of poses and under both nominal and
   deliberately-tolerance-perturbed magnet tilt/strength

Plus one test that is not a finite-difference check: magnet strength must
scale the field *and* the Jacobian by exactly the same ratio, with no residual
change in shape. That is the assumption behind applying strength to the six
cylindrical quantities inside `evaluate()` instead of to the assembled
outputs, and it is what catches someone later scaling only the field, or
scaling on the wrong side of the r=0 L'Hopital branch.

**Run it after touching any `evaluate()` under `firmware/src/magnet_model/`,
or anything either `Math.md` or the analytic Jacobians depend on.** That
includes changes intended to be pure refactors or optimizations — the solver
algebra has been rewritten for speed more than once, and this test is what
established those rewrites were numerically equivalent rather than merely
plausible.

## Things to know before trusting a result

- **Step sizes carry unit assumptions.** `FD_STEP_LINEAR` and
  `FD_STEP_ANGULAR` at the top of the file assume millimetres and radians. If
  the state vector's units ever change, these have to change with them, or the
  comparison silently loses precision instead of failing loudly.
- **The probe points must stay inside the interpolation table's domain.** The
  `(r, z)` points the derivative checks use are chosen to sit interior to the
  bicubic grid, away from the edge-extrapolation region. The grid bounds live
  in `magnet_model_table.h`, which is generated — read them there rather than
  trusting any comment. If they change, re-check the probes: a point that
  falls outside is testing extrapolation, not the thing you meant to test.
  The probes deliberately cover the region real knob poses reach, not the
  whole table, so passing is not a statement about the table's outer edges.
- **Rotation perturbations use the exact matrix exponential**, not the
  first-order approximation the derivation linearizes around. Using the
  first-order form on both sides would let a shared error cancel and hide.

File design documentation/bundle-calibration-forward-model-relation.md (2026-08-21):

# On-Device Bundle Calibration — How the Full Model Relates to the Pose Solver

Written from reading the current forward-model code (`firmware/src/magnet_model/`)
against `design documentation/Math.md` and against the prior session's notes in
`design documentation/on-device-bundle-calibration.md`. Supersedes that file
wherever the two disagree — its own header explains why: it predates the
cross-magnet interference model, and that is exactly what changes below.

## 1. The reuse point is one level lower than the prior session assumed

The prior session's plan (its §2.1) recovers a magnet's field gradient $M$
by reading it off `ForwardModel::evaluate()`'s returned pose Jacobian (its
translation block). That was true before cross-magnet interference existed.
It no longer is: `ForwardModel::evaluate()` now sums all three magnets'
contributions into a single 3×3 per sensor before returning
($J_{trans,i}=-M_i,\ M_i=\sum_j M_{ij}$, `virtual_sensor.cpp`'s
`J_displacement_world`) — the summation Math.md §4.F derives as exact but,
correspondingly, irreversible. A magnet-position or -tilt derivative needs
that one magnet's own $M_{ij}$, not the sum, so it cannot be recovered from
`ForwardModel::evaluate()`'s output anymore.

It doesn't need to be. `MagnetPlacement::near_approx_world()` and
`::far_approx_world()` (`magnet_local_model.{h,cpp}`) already return exactly
that, unsummed, and are already public methods that `VirtualSensor::evaluate()`
itself calls once per (sensor, magnet) pair, before it sums them:

```
B_ij, M_ij = placement_j.near_approx_world(sensor_i)   // paired magnet
B_ij, M_ij = placement_j.far_approx_world(sensor_i)    // cross magnets
```

This is the actual reuse boundary: calibration code calls these two methods
directly, once per (sensor, magnet, frame), and never touches
`ForwardModel::evaluate()`'s summing loop for the shared-parameter columns.
It still reuses `MagnetModel::place()` unchanged, once per magnet per frame.

## 2. One formula, both branches — why that's true, and wasn't obvious

Both `near_approx_world` and `far_approx_world` share an interface: world
position in, field and $\partial B/\partial(\text{world position})$ out. That
alone is enough to reuse the prior session's magnet position/tilt chain rule
(its §2.2) across *both* branches, but it needs one fact the prior session
had no reason to check, since dipole cross-terms didn't exist yet: the dipole
field is rotation-*equivariant*, $B(Q\mathbf m,Q\mathbf r)=Q\,B(\mathbf m,\mathbf r)$
for any rotation $Q$. A magnet's polarization is always its own local
$-\hat z$, so the dipole's *local* moment never depends on tilt — only its
*world* moment does, through $R_{total,j}$. That makes
$\mathbf B_{w,ij}=R_{total,j}B_j(\mathbf v_{l,ij})$ (Math.md §2's general form)
hold for the far branch too, not only the near/interpolated one it was
written for. Consequence: the position derivative

$$\frac{\partial \mathbf B_{ij}}{\partial \mathbf m_j} = -M_{ij}\,R$$

holds unmodified for both branches, and the tilt derivative (prior session's
§2.2) generalizes the same way — *provided* $\mathbf d$ (the magnet-to-sensor
vector the formula needs) is taken relative to the frame each branch actually
uses: `origin_world` for the near branch, `centre_world` for the far one.
That distinction is new; nothing before cross-magnet modelling would have
surfaced it.

## 3. Two forward models, one field, one test

| | Pose solver's forward model | Calibration's forward model |
|---|---|---|
| Solves for | one frame's $(\mathbf t,R)$ | $N$ frames' $(\mathbf t_k,R_k)$ + 27 shared params |
| Per-frame block (6 cols) | `ForwardModel::evaluate()` | the same call, unchanged |
| Shared-param block (45 cols) | doesn't exist | new: built from `near_/far_approx_world` |
| Underlying field/Jacobian math | Math.md §3–4 | same, chain rule extended to the shared params |

The pose-solver forward model is a special case of the calibration one, at
$\theta=\theta_{nominal}$, one frame. That gives the agreement test the user
asked for almost for free: evaluate the calibration model's field prediction
and its 6 pose columns at nominal $\theta$, for one frame, and require it to
match `ForwardModel::evaluate()`'s own output to float tolerance. Because the
pose columns literally are that same call, this is less "agreement between
two implementations" and more "the new code didn't disturb the old call
path" — which is the point: there is one forward model, evaluated over a
wider parameter vector, not two forward models kept in sync by hand.

## 4. Where the 27 shared columns come from

| Group | Cols | Derivative | Reuses |
|---|--:|---|---|
| magnet position | 3 (of 9, gauge-reduced) | $-M_{ij}R$ | $M_{ij}$ from either `*_approx_world` call |
| magnet tilt | 2 per magnet (6) | $M_{ij}R[\mathbf d]_\times - R[\mathbf b]_\times$, chart-projected | same, + gnomonic chart (prior session's §2.5, unaffected by cross-magnet) |
| strength, common + spread | 3 | $\mathbf B_{ij}/s_j \cdot s_{nom}$ | $\mathbf B_{ij}$ from either call — both branches linear in $s_j$ |
| sensor offset | 9 | see §5 | raw reading only |
| sensor gain | 6 (of 9, traceless-diagonal) | see §5 | raw reading only |

Position, tilt and strength are the only groups that touch the field model,
and each is one 3×3 (or a field value) already computed by the calls in §1 —
no new field lookups, matching the prior session's efficiency claim, just
sourced one layer down from where it expected.

**Gain is now diagonal** — $G_i=\mathrm{diag}(g_{i,x},g_{i,y},g_{i,z})$, 3 raw
numbers per sensor instead of 9. The gauge story from the prior session's §1
is unchanged, just smaller: the isotropic direction ($g_x=g_y=g_z$) is still
the same degree of freedom as magnet strength, still fixed by the same
`det(G)=1`-style gauge, still leaving strength to own absolute scale — it's
just that "isotropic" now lives inside a 3-dimensional space of diagonal
matrices instead of a 9-dimensional space of general ones. That leaves 2
free (traceless-diagonal) params per sensor rather than 8, so the group
drops from 24 columns to 6, and the total shared-parameter count drops from
45 to 27.

## 5. Gain and offset: fit the convention the firmware actually uses

The prior session assumed the PC fit's convention, prediction
$\hat{\mathbf B}=G\mathbf B_{model}+\text{offset}$, and warned (its §2.4)
that gain then multiplies every field-derived column — a documented,
easy-to-drop factor. The firmware doesn't use that convention.
`SensorController::read_mT()` applies gain to the *measurement*:
`corrected = sensor_gain·raw − sensor_offset_mT`. Written into the residual
the pose solver already minimizes ($\mathbf r=\hat{\mathbf B}-\mathbf B_{measured}$,
`solve_pose.cpp`), fitting on-device against that same convention gives

$$\mathbf r_i = (G_i\,\mathbf{raw}_i - \mathbf{offset}_i) - \mathbf B_{w,i}(\theta_{geom},\rho)$$

$$\frac{\partial \mathbf r_i}{\partial \mathbf{offset}_i} = -I, \qquad \frac{\partial \mathbf r_i}{\partial g_k} = G_k\,\mathbf{raw}_i$$

With gain now diagonal, $G_k$ is one of the 2 traceless *diagonal* basis
matrices per sensor rather than one of 8 general traceless ones, so
$G_k\,\mathbf{raw}_i$ is an elementwise scale-and-pick of the raw reading's 3
components — no matrix-vector product at all, just as cheap as the offset
column.

Gain and offset columns now act only on a stored raw reading; every
field-derived column (position, tilt, strength, pose) is untouched by gain
entirely. The prior session's §2.4 pitfall — a column scaled twice, or a
missing $G$ — has no way to occur in this formulation, since there is no
shared factor between the two column families to forget. This also matches
`TODO/resolved/sensor-gain-calibration.md`'s existing decision to keep
correction at the sensor, not the model — the calibration forward model
should follow the same split rather than reintroduce gain inside it.

## 6. Left open

Two things this exploration surfaced but didn't resolve, both blocking before
any solver code gets written:

- **The arrowhead/Schur elimination algebra has no home yet.** The prior
  session cites "Math.md §7" for it (its §3.1); `Math.md` currently ends at
  §6. That derivation needs to exist somewhere citable before the two-pass
  solver (prior session's §3) can be implemented against it.
- **On-device frame volume vs. RAM.** `BundleCalibrationController` currently
  streams roughly a second of samples per step across 7 steps to the PC —
  enough frames that storing all of them, rather than the two-pass scheme's
  rebuild-from-raw-reading approach, is very unlikely to fit. Not a blocker
  for the math above, but the two-pass design's premise should be checked
  against real capture counts before committing to it.

## Addendum: two equally valid framings of the tilt collapse

§4's tilt column is $N_{ij}[\mathbf d]_\times A_j - [\mathbf B_{ij}]_\times(RA_j)$, where
$A_j$ is the fixed knob-frame map from $(u,v)$ to a rotation-perturbation
vector $\boldsymbol\varepsilon_j$. There are two correct ways to describe where
$RA_j$ comes from, and it's worth having both on record rather than re-deriving
this the next time it comes up:

- **$\boldsymbol\varepsilon_j$ stays knob-frame; $R\boldsymbol\varepsilon_j$ is a second,
  world-frame representation of that same physical rotation**, used only by
  the term that needs one. This is the framing that explains *why* $(u,v)$
  can't be defined in world frame in the first place: it has to mean the same
  physical tilt in every captured frame, and only a knob-frame (pose-independent)
  definition guarantees that.
- **Equivalently: for that one term, $(u,v)$ is mapped to a rotation directly
  in the world frame**, via $RA_j$ instead of $A_j$. This is the more direct
  answer to "is this a world-frame rotation" — yes, for that term's purposes.

Both describe the same computation. The first is the one to reach for when
the question is what $(u,v)$ *means*; the second is the one to reach for when
the question is what a specific intermediate *is*.

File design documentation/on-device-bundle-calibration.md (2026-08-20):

Below is a summary of the approach taken by an older claude session, written by that same session.

That session ran into issues, so it was abandoned. Since then one significant piece of math changed:
we now model cross magnet interference. Another piece changed: we now use BLA instead of eigen.

Take this as a good source for first things to try. Not as gospel.

# Bundle Calibration — Deriving the Jacobians, and the Two-Pass Solver

Calibration fits the constants the pose solver treats as frozen — where each
magnet sits in the knob, how it is tilted, how strong it is, and each sensor's
gain and DC offset — jointly across many captured frames, each of which also
contributes its own unknown pose.

This document covers two things a reimplementation needs and cannot get from
reading the pose solver alone:

1. **How to derive the calibration Jacobians by reusing the existing
`evaluate()` chain**, rather than writing a second forward model.
2. **How the resulting normal equations are solved** — a two-pass
Schur-complement scheme that never materializes the full system.

`Math.md` owns the forward model and the pose Jacobian (§1–6) and the algebra
of the arrowhead normal equations (§7). This document is the layer between:
the derivatives §7 declines to derive, and the practical shape of the solver
§7 only sketches.

\---

## 1\. What is being fitted

Following the PC-side fit in `magnet\_field\_model/calibration/`:

|group|free parameters|note|
|-|-:|-|
|magnet position|3|9 raw (3 magnets × xyz) minus a 6-DOF gauge|
|magnet tilt|6|2 per magnet; spin about a magnet's own axis is unobservable|
|magnet strength, common|1|the absolute field scale|
|magnet strength, spread|2|zero-sum deviations from that common level|
|sensor offset|9|3 per sensor|
|sensor gain|24|8 per sensor|

**45 shared parameters, plus 6 per frame.** All are *offsets from nominal*, so
the zero vector is the CAD/nominal configuration.

Three of those counts are reductions, and the reasons matter:

* **Position: 9 → 3.** Translating or rotating the whole magnet trio is exactly
cancelled by a compensating change in every frame's pose, so 6 of the 9 DOF
are unobservable. The fix is structural — project onto the 3-dimensional
nullspace complement — rather than relying on a prior to pin them.
* **Tilt: 3 → 2 per magnet.** A magnet is a solid of revolution about its
polarization axis, so spin about that axis changes nothing measurable. This
is an *exact* symmetry, not a weak direction.
* **Gain: 9 → 8 per sensor.** Overall gain scale and magnet strength are the
same physical degree of freedom. The split is fixed by a gauge: gain carries
no isotropic component (8 traceless basis matrices), and `magnet\_strength`
owns absolute scale instead.

Strength is best carried as a **dimensionless multiplier** around 1, not an
absolute mT offset. Both physical beliefs about it are relative — "magnets from
one batch are graded to within a few percent of each other", "the absolute
remanence could be anywhere from 500 to 1500 mT" — so a multiplier is the
parameterization those beliefs are actually stated in, and prior widths
transfer between implementations without a scale factor.

\---

## 2\. Deriving the Jacobians from the existing forward model

### 2.1 The reuse that makes this cheap

The expensive part of a forward evaluation is the bicubic field lookup. The
naive approach — differentiating the calibration constants from scratch —
would repeat it. It does not need to.

`Math.md` §4.E defines the shared 3×3 core

$$M = R\_{total},J\_{local},R\_{total}^T$$

and the pose Jacobian's translation block is exactly $-M$ (pre-gain). So a
forward evaluation *already computes and returns* everything the calibration
derivatives need. Recover it from the output:

```
M  =  -(translation block of the returned pose Jacobian)
```

No second field lookup, no reaching into the model's internals. Every
chain-rule group below is one 3×3 product away from data already in hand,
which is what makes the bundle forward problem a thin wrapper around the
existing one rather than a parallel implementation to keep in sync.

### 2.2 The three groups that need the chain rule

Work in the knob frame. With

* $\\mathbf v = \\mathbf s\_i - \\mathbf t$ — sensor position relative to the knob origin, global frame
* $\\mathbf d = R^T\\mathbf v - \\mathbf m\_j$ — magnet-to-sensor vector, knob frame
* $\\mathbf b = R^T \\mathbf B\_g$ — the predicted field, knob frame
* $s$ — the magnet's strength

$$\\frac{\\partial \\mathbf B\_g}{\\partial \\mathbf m\_j} = -M R
\\qquad
\\frac{\\partial \\mathbf B\_g}{\\partial \\boldsymbol\\varepsilon} = M R \[\\mathbf d]*\\times - R\[\\mathbf b]*\\times
\\qquad
\\frac{\\partial \\mathbf B\_g}{\\partial s} = \\frac{\\mathbf B\_g}{s}$$

where $\\boldsymbol\\varepsilon$ is a **left** perturbation of the magnet's
rotation, $R\_{mag} \\to \\exp(\[\\boldsymbol\\varepsilon]*\\times)R*{mag}$ — the same
convention `Math.md` Identity 2 uses for the pose rotation, so tilt and pose
step the same way.

Derivation sketch: start from
$\\mathbf B\_g = R,R\_{mag},B!\\left(R\_{mag}^T(R^T\\mathbf v - \\mathbf m\_j)\\right)$
and differentiate with respect to $\\mathbf m\_j$ and to $\\boldsymbol\\varepsilon$.
The strength column is not a chain rule at all — strength enters the field as a
scalar multiplier, so the derivative is the prediction rescaled.

Note the tilt expression's second term. $R\_{mag}$ cancels out of
$\\mathbf b = R\_{mag}^T R^T \\mathbf B\_g$ rotated back, which is why the formula
needs only the knob-frame field and not any local-frame intermediate.

**Keep this layer 3-DOF.** The derivative above is a full 3×3 — how the field
responds to *any* rotation of the magnet. That is a fact about physics with no
modelling choice in it. Which 2-D subspace gets fitted is a chart decision and
belongs in the caller. Fusing them means re-deriving and re-verifying physics
every time the chart changes, and it collapses the two-tier test structure of
§4 into one untestable step.

### 2.3 The five groups that need no model call

Sensor offset and the three gain groups are linear maps of quantities the
forward pass already produced:

$$\\frac{\\partial \\hat{\\mathbf B}\_i}{\\partial (\\text{offset}\_i)} = I
\\qquad
\\frac{\\partial \\hat{\\mathbf B}*i}{\\partial g\_k} = G\_k \\mathbf B*{g,i}$$

where $G\_k$ is the $k$-th traceless gain basis matrix. These belong to a
*physical sensor*, so they are touched only by that sensor's own three rows —
a structural fact that survives any change to how magnets couple to sensors.

The strength mean/diff split is bookkeeping over the already-computed
per-magnet strength column, weighted by each magnet's coefficient in the two
strength bases.

### 2.4 Two chain-rule factors that are easy to drop

Both of these produce a plausible-looking fit rather than an obvious failure,
because Levenberg-Marquardt absorbs the error by mis-fitting everything else.

**Gain multiplies the field-derived columns.** The prediction is
$\\hat{\\mathbf B} = G\\mathbf B\_g + \\text{offset}$, so every derivative acting
through the field carries a factor of $G$:

$$\\frac{\\partial (G\\mathbf B\_g)}{\\partial(\\text{magnet param})} = G,\\frac{\\partial \\mathbf B\_g}{\\partial(\\text{magnet param})}$$

The forward model returns a **pre-gain** derivative. This cannot be applied by
scaling the assembled row, because the gain's own columns are already complete
derivatives and must not be scaled twice. `Math.md` §4.E flags the same trap
for the pose Jacobian, where $\[\\mathbf B\_g]\_\\times$ must be built from the
pre-gain field. The pose block carries the same factor of $G$ here.

**A multiplier strength parameter needs the nominal strength.** The forward
model returns $\\partial \\mathbf B/\\partial s$, an *absolute* derivative. If the
fitted parameter is a dimensionless multiplier (§1), then

$$\\frac{\\partial \\mathbf B}{\\partial(\\text{multiplier})} = \\frac{\\partial \\mathbf B}{\\partial s}\\cdot s\_{nominal}$$

Omitting it makes the strength columns wrong by the nominal strength — a
factor of \~1000.

### 2.5 Parameterizing tilt

The measurable configuration of an axially-polarized magnet is the *direction*
of its axis — a point on $S^2$, two degrees of freedom. Any two-parameter chart
works in principle; what differs is where it degenerates.

**Spherical / Euler angles are a poor choice here**, because their singularity
is at the pole and the pole is nominal. With
$\\hat n = (\\sin\\theta\\cos\\varphi, \\sin\\theta\\sin\\varphi, \\cos\\theta)$ the
azimuth column scales as $\\sin\\theta$, so at a tolerance-sized tilt of a degree
or two its weight in the normal equations is \~$10^{-3}$ of the polar column's.
The ridge prior swallows it and two nominal DOF quietly become about one
fitted.

**A gnomonic (pinhole) chart avoids this.** Name the axis by where its line
crosses a plane one unit from the magnet, in the nominal magnet's frame:

$$\\hat n(u,v) = \\frac{(-u,\\ -v,\\ 1)}{\\sqrt{1+u^2+v^2}}$$

with nominal at $(0,0)$. Its derivative there is an orthonormal basis of the
tangent plane — perfectly conditioned — and its singularity sits at 90°, which
the chart cannot reach since $n\_z > 0$ for all finite $(u,v)$. The coordinates
also read physically: an offset in millimetres of where the axis lands.

The chart Jacobian converts the 3×3 above into the two fitted columns. A left
perturbation moves the axis by $d\\hat n = \\boldsymbol\\varepsilon \\times \\hat n$,
and components of $\\boldsymbol\\varepsilon$ along $\\hat n$ (spin) move it not at
all, so the canonical spin-free choice is
$\\boldsymbol\\varepsilon = \\hat n \\times d\\hat n$:

$$\\frac{\\partial \\boldsymbol\\varepsilon}{\\partial(u,v)} = \[\\hat n\_{knob}]*\\times, R*{nominal}, \\frac{\\partial \\hat n\_{local}}{\\partial (u,v)}$$

Because these columns are built as $\[\\hat n]\_\\times(\\cdot)$, they are
perpendicular to the magnet's *current* axis at any tilt, by construction —
spin is unrepresentable rather than approximately projected away. Contrast the
obvious alternative of dropping a fixed coordinate column, which annihilates
the dead direction only at zero tilt.

The magnet's rotation matrix becomes a *derived* quantity, rebuilt from the
two parameters by a shortest-arc lift from nominal. It therefore cannot
accumulate orthogonality drift, and there is no rotation-vector-versus-tangent
-space convention to reconcile: you differentiate your own chart.

### 2.6 Where each piece is computed

Two nested loops, and the split matters for performance:

* **Per magnet, per solver iteration** (3 calls): rebuild the magnet model and
the chart Jacobian from the current parameters. These depend only on the
magnet's own parameters, not on any frame.
* **Per (sensor, frame)** (\~3N calls): one forward evaluation, then the
derivative formulas above.

Rebuilding the magnet model inside the frame loop instead is a measurable
waste — model construction is a meaningful fraction of one evaluation's cost,
and doing it per-frame pays that fraction tens of times over.

\---

## 3\. The two-pass Schur solver

### 3.1 Why the normal equations are arrowhead-shaped

Frame *k*'s residual depends on the shared parameters and on **its own pose
only** — never on another frame's. Differentiating gives a stacked Jacobian
whose off-diagonal pose blocks are exactly zero, and $J^TJ$ inherits that
structure: a dense shared block, one small pose block per frame, thin coupling
blocks, and nothing else.

`Math.md` §7 derives this properly and shows the elimination is an exact
linear-algebra identity rather than an approximation. The rest of this section
assumes that result.

Worth stating the assumption explicitly, since it is the one thing that would
break everything: **no term may couple two frames.** A temporal-smoothness
prior linking consecutive frames would violate it. Modelling cross-magnet
interference would *not* — that coupling acts within a frame, between a sensor
and a non-paired magnet, and never links frame *k* to frame *l*.

### 3.2 The two passes

Per solver iteration:

**Pass 1 — accumulate.** For each frame: build its local system from its
sensors' rows, then fold it into a persistent shared accumulator, eliminating
that frame's pose block. Discard the frame's data. After every frame, add the
ridge/prior terms and the LM damping, then solve the reduced shared system
once.

**Pass 2 — back-substitute.** For each frame: rebuild its pose row and recover
that frame's own pose update from the now-known shared update.

Nothing per-frame persists between the passes. Peak memory is one accumulator
plus one frame's worth of transient blocks — independent of the frame count,
which is the entire point. The direct alternative is a dense system of side
(shared + 6 × frames), which at realistic sizes does not fit in this device's
RAM at all.

### 3.3 Three details that are easy to get wrong

**Pass 2 must linearize where pass 1 did.** The shared update and every pose
update may only be applied to the iterate *after* pass 2 has finished for every
frame. Update early and each frame's blocks come from a different linearization
than the reduced system that produced the shared update, and the
back-substitution silently stops being the exact identity it is derived as.
This is a hazard of rebuilding specifically — a design that stored the blocks
could not get it wrong, because stored blocks carry their linearization point
with them.

**Pass 2 is the cheaper pass, and the types should say so.** Back-substitution
reads only the pose block, the coupling block and the pose right-hand side —
never the shared block, which is by far the most expensive term to accumulate.
Giving pass 2 a distinct, smaller type makes that structural: a caller cannot
accidentally pay for a shared block it will not read, and cannot forget it in
pass 1.

**Rebuild rather than store.** Keeping every frame's coupling block between
the passes would cost tens of kilobytes for data needed microseconds later.
Rebuilding costs a second forward-model pass over the frames, which is a good
trade for a once-per-unit operation that is not latency-sensitive.

### 3.4 Solving the reduced system

A plain dense factorization of the reduced shared system is adequate. The
shared block has exploitable structure of its own — sensor-local parameters
(offset, gain) are touched only by their own sensor, making it bordered
block-diagonal — but eliminating that too optimizes a term that is a small
percentage of an iteration, since the factorization is cubic in \~45 while the
*accumulation* it sits on top of is far larger.

That structure is still worth having, for a different reason: it makes the
**accumulation** sparse. One sensor's rows touch roughly 40% of the shared
columns, so a sparsity-aware accumulator is several times cheaper on the term
that actually dominates. Structure for accumulation, dense solve.

If the column order is chosen to consolidate that structure — parameters
grouped by the unit they belong to, rather than by parameter type — each
sensor's live columns form two contiguous runs instead of many scattered ones,
which is what lets the accumulation use fixed-size block operations. Note that
the *number* of nonzeros is a property of the problem and is unaffected by
ordering; what ordering buys is that they are contiguous.

\---

## 4\. Verifying it

Hand-derived derivatives fail silently: a wrong sign or a dropped term does not
crash, it makes the solver converge slowly to a slightly wrong answer.

**Finite differences against the real forward model**, in the style of
`firmware/test/test\_jacobian.cpp`. Two tiers are needed, and the second is the
one that catches wiring:

1. Each raw derivative against perturbing that one physical quantity.
2. The *assembled* parameter column against perturbing the real parameter —
through the gauge projection, the chart, and the column layout. Tier 1
passes happily with a transposed basis or an off-by-one magnet index.

**The Schur elimination is checkable exactly**, not by finite difference. It is
a linear-algebra identity, so assemble the full arrowhead system densely, solve
it in one shot, and require the frame-by-frame path to agree to float32
precision. Finite differences would be a strictly weaker check of something
exactly checkable.

Four things that cost real time to discover, all worth knowing in advance:

* **Probe poses must be inside the bicubic table's domain.** The knob rests
about 21mm above the sensor plane; a hand-picked pose can easily land outside
the table, where the field is extrapolated nonsense. Every finite-difference
test still *passes* out there, because analytic-vs-numeric consistency holds
in the extrapolation region too. What fails is the solver, which stalls on
the extrapolated surface. Derive test poses from the nominal rest pose.
* **Finite-difference step sizes carry unit assumptions**, and one step does not
fit all groups. Parameters in field units entering a large prediction
additively need a *large* step or roundoff swamps the difference; tilt moves
the field only by $|B|\\cdot O(h)$ and also needs a larger step than geometry
does. Set each by sweeping and watching which way the error moves — error
*growing* as the step shrinks means the instrument is at fault, not the
algebra.
* **An exact symmetry is not a derivative.** Spin about a magnet's own axis
changes nothing, and differencing two large near-equal floats to extract a
zero is where central differences are worst. Test it as a direct invariance
instead: rotate by real, finite angles and compare outputs.
* **Check synthetic test data for rank.** Generating "arbitrary" matrices as
`sin()` of a linear combination of indices produces matrices that all live in
a 2-D subspace regardless of size, which makes every synthetic system
singular and every comparison meaningless.

A test that shares a helper with the code it tests is a consistency check, not
an oracle — if the same wrong constant feeds both the state being differenced
and the Jacobian being checked, they cancel. Transcribe the basis constants
independently in the test. Mutation testing is how to find out which of your
tests actually bite.

\---

## 5\. Practical notes

**Stack pressure is a real constraint.** This core's stack is small — single
kilobytes — and C++ makes it easy to exceed without writing anything that looks
large: value-returning factorizations, accumulator resets via assignment from a
temporary, and matrix expression temporaries all land there. Compiling with
`-Wstack-usage` turns this into a build failure rather than something to
reason about, and is worth doing from the start.

**Absolute field scale is weakly determined without cross-magnet coupling.**
Cross-talk is what separates magnet *strength* from magnet *distance* — a
strength change scales near and far contributions equally, a height change does
not. Without it the two are near-degenerate over the few millimetres of heave
the hardware allows. This does not hurt fit quality, only the physical meaning
of the fitted numbers. See `TODO/cross-magnet-interference.md`.

**A prior on the common strength level is not obviously wanted.** Leaving it
unregularized is safe even though it is near-degenerate with position and gain,
because a flat direction only survives if it lies *entirely* within
unregularized coordinates — and every parameter it trades against does carry a
justified prior, which supplies curvature along the whole combined direction.

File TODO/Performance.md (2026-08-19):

# solve_pose performance

**Everything through the third pass below was measured against the
Eigen-based solver.** `TODO/eigen-to-bla-migration.md` has since replaced
Eigen with `BasicLinearAlgebra` — the RAM/flash regression mentioned
below was root-caused and fixed (a `Printable` vtable pointer, not
floats-vs-doubles or anything algebraic), and the fourth pass at the
bottom of this document re-runs this document's own measurement
methodology against BLA specifically: does it inline better than Eigen
did (yes, substantially), and does that mean any of the hand-unrolling
below can come back out (no — measured, not assumed, for all three
candidates). The Eigen-specific findings in the first three passes (the
non-inlining, the blocked-GEMM dispatch for `jacobian.transpose() *
jacobian`) describe why those rewrites happened and remain accurate
history; they're no longer a description of the current library.

**Everything through the fourth pass describes the pre-cross-magnet call
graph.** `origin/experimental`'s forward-model refactor (every sensor sees
every magnet, not just its paired one) changed what `VirtualSensor::evaluate`
actually computes and added a new hand-unrolled Jacobian (`dipole_field`)
that didn't exist when the fourth pass ran. The fifth pass, near the bottom,
re-derives that pass's conclusions against the new call graph rather than
assuming they still hold, and checks the one genuinely new candidate.

The whole loop runs at 50Hz, and `solve_knob_pose()` (`firmware/src/magnet_model/solve_pose.cpp`)
currently eats a little under half that budget — call it 10ms. Goal is to get
it down toward ~4ms if we can. This file is the investigation notes: assembly-
verified hypotheses on where that time actually goes, not yet a fix plan.

Platform context that matters for everything below: Seeed Xiao RP2040, dual
Cortex-M0+ @ 133MHz, **no hardware FPU**. Every `float` operation is a software
subroutine call. `solve_knob_pose`, `ForwardModel::evaluate`,
`VirtualSensor::evaluate`, `MagnetModel::evaluate`, and `BicubicField::evaluate` are
all marked `__not_in_flash_func` (placed in RAM), presumably to dodge flash
XIP wait-states on this hot path.

## How to measure, before you measure anything

Both of these were learned the hard way in the passes below, and both produce
confident wrong answers rather than obvious failures.

- **Static `bl`-counting can give the wrong sign.** Tallying call targets in a
  disassembly counts work inside a loop kernel once regardless of how many
  iterations it runs, so replacing an Eigen loop kernel with straight-line
  scalar code looks like a regression when it is a 20% win. It flipped the
  sign on the third pass's result. Cross-check with
  `valgrind --tool=callgrind` on a host build before believing a static tally.
- **Prefer measuring to estimating.** The hand-counted flop estimates this
  document originally carried were wrong enough to be replaced wholesale. If a
  number goes in here, say how it was obtained — the sections below are
  labelled by method for exactly this reason.

## Ruled out / already fine

- **Bicubic table location**: `BICUBIC_INTERPOLATION_TABLE` is at `0x20003278`
  per `firmware.map` — RAM, not flash. Confirmed, not a lead.
- **r² parameterization** of the bicubic table (to save the `sqrtf` in
  `MagnetModel::evaluate`, `firmware/src/magnet_model/magnet_local_model.cpp:21`):
  rejected. It would concentrate resolution away from the high-curvature
  region near the magnet, which is exactly where accuracy matters most. Only
  worth revisiting alongside a non-uniform grid + Hermite splines, which has
  its own (painful) lookup cost — not pursuing now.
- **Quasi-Newton** (reuse/update the Jacobian across a couple of iterations
  instead of recomputing the full rotated Jacobian every time): plausible
  lever, parked for later, not investigated yet.

## Blocking prerequisite: the Statistics TODO — RESOLVED

Before adding any new solver telemetry (iteration count, per-phase timing),
this doc called out an existing TODO at `solve_pose.cpp:21`: `solve_knob_pose`
always allocated local `residual`/`jacobian` and copied them into
`*residual_out`/`*Jacobian_out` at the end, rather than writing into those
output pointers directly when non-null. `MotionController::read_pose` always
passes them (`Config::statistics` is `true`), so that copy was live on every
call. Fixed as a side effect of the "third optimization pass" below
(`solve_knob_pose` now writes into the caller's buffers directly), so new
solver telemetry is no longer blocked on it — see "Open next steps".

## Method: disassemble the real binary, don't guess

Built with `pio run -e seeed_xiao_rp2040`, then disassembled
`firmware.elf` (`arm-none-eabi-objdump -d -C`) and walked the actual call
graph starting at `solve_knob_pose`. Two things made naive call counting
useless until handled:

1. **Linker veneers**: RAM code calling flash code (or vice versa) goes
   through a synthetic thunk (`push {r0}; ldr r0,[pc,#N]; mov ip,r0; pop {r0};
   bx ip`), whose real target is a `.word` literal embedded right after the
   thunk. Naively following `bl` targets stops at the veneer; had to extract
   the embedded address and resolve it against the symbol table to find out
   what's actually being called.
2. **Dead paths pollute reachability**: `eigen_assert` bounds-checks compile
   to real (conditional, never-taken-in-practice) calls to `assert_func` —
   meaning **`NDEBUG`/`EIGEN_NO_DEBUG` isn't defined in this "release"
   build** — and the `if (!dx.allFinite())` branch in `solve_pose.cpp` pulls
   in `Serial.println`/`delay`. Both are reachable in the static call graph
   but never execute on the success path, and naively expanding them explodes
   into unrelated code (float-formatting routines, etc.). Excluded both from
   the tally below; noted the `NDEBUG` gap as a separate, easy, unrelated fix.
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

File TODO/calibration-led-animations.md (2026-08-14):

# LED ring animations for bundle calibration

## Current state (updated — architecture pass landed)

The animation architecture has been reworked. `LEDController`
(`firmware/include/controllers/LEDController.h`,
`firmware/src/controllers/LEDController.cpp`) no longer has per-effect
methods (`setSolid`/`startSpinner`/`off` are gone). Instead:
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

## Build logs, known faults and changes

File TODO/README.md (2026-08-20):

# TODO

This directory tracks non-trivial follow-up work: real architectural
decisions or issues that don't belong in a code comment and don't fit in a
single commit. Some files originated from the architecture review in
`../ARCHITECTURE.md`; others get added independently as issues come up
during development. Each file covers one self-contained issue, or a small
cluster of tightly related issues.

File names are descriptive, and each file's own content is the source of
truth for the detail — skim the directory listing to see what's open. This
file also carries a 2-line summary per TODO, below, so the state of
everything open is skimmable from one place without opening each file. Keep
it in sync: it's a second copy of information the file itself owns, so it
only stays trustworthy if every commit that changes what a TODO is actually
about also updates its summary line here in the same commit.

`resolved/` holds finished TODOs rather than deleting them, so the reasoning
behind a decision outlives the decision. **Everything in there is history:
it is written in the present tense but describes code as it was.** Each
archived file carries a header saying what closed it and where the current
description lives. Don't cite `resolved/` as a statement about the tree.

## Writing a TODO file

- State the problem concretely: what's wrong, where in the code, and why it
  matters — not just "this is inconsistent," but what actually breaks or
  gets harder because of it.
- Include a "likely fix shape" if you have one, but it doesn't need to be a
  committed plan — just enough direction that whoever picks it up isn't
  starting from zero.
- **Head that section "Design", not "Decision".** A design is what you intend
  to build; a decision is a question that is closed, and calling a sketch a
  decision hides the fact that it can still change. Reserve "Decided" for
  parts that are actually settled.
- Update a file in place as understanding deepens, rather than leaving it
  stale. `Performance.md` is the model here: each optimization pass appended
  its own section and amended the earlier ones it invalidated, so the file
  reads as a running investigation rather than a stale first draft.
- **When you implement part of a TODO, update that TODO in the same commit.**
  The two worst drifts found so far both came from skipping this:
  `sensor-read-speed.md` was implemented 11 minutes after it was written and
  still claimed nothing had been done, and `Performance.md` described a
  constants bug as open that a parallel branch had fixed a minute earlier.
  Neither conflicted, so git had nothing to complain about.
- If a new problem turns out to be tightly coupled with an existing file's
  topic, add a section there instead of creating a duplicate.
- Add a 2-line summary entry below, in the index, in the same commit.

## Resolving a TODO file

- **Move the file to `resolved/`, don't delete it.** The investigation that
  produced a decision is worth more than the decision alone — why an approach
  was rejected, what was measured, which datasheet paragraph it turned on.
  That context is what stops the same ground being re-covered later, and it
  is not reconstructible from the diff that implemented it.
- Add a short header at the top of the moved file saying what resolved it
  (commit hashes where they're known), and where the *live* description now
  lives — usually a section of `../ARCHITECTURE.md`. A reader who lands in
  `resolved/` must be able to tell immediately that they're reading history,
  because the body will still be written in the present tense and will
  describe code that no longer looks like that.
- Move its index entry down to the "Resolved" list below.
- If the issue was also tracked in `../ARCHITECTURE.md`'s "Issues /
  architecture drift" list, update that entry to say it's fixed and point at
  the archived file.
- Prefer pointing live code comments at `ARCHITECTURE.md` rather than into
  `resolved/` — the archive is for someone digging into history, not a
  reference the code should depend on.
- Trivial issues resolved without ever getting a TODO file don't need one
  written retroactively just to close it out.

## Index — open

Two lines per file, kept current with the file's actual content — if a TODO
gains a new open question or loses a resolved one, update its summary here
too, not just the file.

- **[`Performance.md`](Performance.md)** — Assembly/instruction-level
  profiling of `solve_knob_pose`; three completed optimization passes
  (NDEBUG/-O2 fix, `BicubicField` rewrite, solver algebra) took the loop from
  ~50Hz to ~80Hz, a fourth pass confirmed BLA inlines better than Eigen did
  and put all three hand-unrolled forms back to clean BLA (two free, one
  ~7.5% costlier but kept), a fifth pass re-verified all of that plus a
  brand-new hand-unrolled site (`dipole_field`'s Jacobian) after
  `origin/experimental`'s cross-magnet forward-model refactor — three of
  four candidates free-or-better, `BicubicField` still ~7.3-7.5% costlier
  and still kept — and a sixth pass made `BLA::Matrix` `constexpr`-capable,
  moving the generated 4,641-entry bicubic table off a dynamically-
  initialized `.bss` array onto a single compile-time image, then pinned
  that image back into RAM with `__not_in_flash` (same `.time_critical`
  mechanism `BicubicField::evaluate` itself already uses) so the hot lookup
  keeps uniform RAM-speed access instead of depending on XIP-cache
  behavior. Real build: Flash **234,464 B** / RAM **70,768 B** (down from
  328,208 B / 70,888 B — all the flash win from removing 4,641 constructor
  calls kept, RAM essentially unchanged from the original baseline).
  Iteration-count telemetry and an on-device wall-clock re-measurement of
  the cross-magnet refactor's own cost are still open.
- **[`eigen-to-bla-migration.md`](eigen-to-bla-migration.md)** — Eigen
  replaced with `BasicLinearAlgebra`, vendored and patched (dropped a
  `Printable` base that was giving every matrix a hidden vtable pointer —
  BLA now beats the Eigen baseline on both flash and RAM). Extended to cover
  `origin/experimental`'s cross-magnet refactor, ported onto BLA rather than
  merged as Eigen: new `MagnetPlacement`/`dipole_field` abstractions, a
  `Mat2` alias and an `outer()` helper added to the shared BLA surface, and
  `.x()`/`.y()`/`.z()` accessors added to the vendored copy itself (this
  pass brought in enough more Eigen-idiom source that closing that gap once
  beat hand-translating every call site). `BLA::Matrix`'s literal-list
  constructor is now `constexpr`, closing the file's last open item — the
  real payoff was the generated bicubic table, which now builds as a single
  compile-time image (see `Performance.md`'s sixth pass) instead of 4,641
  runtime constructor calls, and stays RAM-resident via `__not_in_flash`
  rather than the small local basis matrix this file originally pointed at,
  which measured no codegen difference at all either way. On-device
  verification is
  still open.
- **[`calibration-led-animations.md`](calibration-led-animations.md)** — The
  LED animation architecture (`AnimationBase`/`std::variant`) is in place,
  but bundle calibration only shows one placeholder spinner. The actual
  per-phase/per-step visuals are undesigned.
- **[`calibration-mode-entry.md`](calibration-mode-entry.md)** — Entry into
  bundle calibration is now PC-initiated via `CAL_START`, closing the old
  accidental-entry bug. A knob-side exit gesture and `BundleState.cpp`'s
  `takeActivity()`-instead-of-`buttonBits()` bug are still open.
- **[`multicore.md`](multicore.md)** — Proposed design: core1 runs the pose
  solve continuously, with sensor readings and poses crossing the core
  boundary as double buffers gated by a spinlocked counter held across the
  copy. Telemetry is a third channel that doesn't fit that shape and is
  undesigned; nothing is implemented.
- **[`tare-and-calibration.md`](tare-and-calibration.md)** — `CalibratingState`'s
  boot-time averaging needs to become a proper "tare" step with sanity
  checks (rest position, polarization, residual) and a reject/retry path.
  Still a design sketch — no implementation decisions made yet.
- **[`telemetry-rework.md`](telemetry-rework.md)** — Four bundled issues; the
  hardcoded `rcond` stub is now gone (dropped upstream, ported as dropped).
  Still open: flatten `TelemetryController::publish()`'s growing parameter
  list, add solver convergence telemetry, and add a lightweight profiling API.

## Index — resolved (`resolved/`)

History, not current state. One line on what it was and what closed it; the
archived file's own header has the detail.

- **[`resolved/controller-ownership.md`](resolved/controller-ownership.md)** —
  Controller coupling around the pose pipeline. The forward model got a real
  owner (`1883bc2`/`20f5f4d`); the remaining "circular coupling" was settled
  by deciding the accessor pattern *is* the rule — see `ARCHITECTURE.md` →
  "Controllers".
- **[`resolved/cross-magnet-interference.md`](resolved/cross-magnet-interference.md)** —
  Cross-magnet coupling (1.7–4.5% of the signal) was quantified but not
  modelled, forcing the Python fit into a workaround that cost the absolute
  field scale. Now modelled: every sensor sees every magnet, the non-paired
  two as point dipoles. Live description is `design documentation/Math.md`
  §3.6/§4.E. Not yet verified on hardware, including its cost.
- **[`resolved/sensor-gain-calibration.md`](resolved/sensor-gain-calibration.md)** —
  Moving sensor gain/skew out of the solver. Now applied in
  `SensorController::read_mT()` from `CalibrationParams`; the last gap
  (`export.py` emitting a bare multiplier) closed with
  `firmware_magnet_strength_mT()`.
- **[`resolved/sensor-read-speed.md`](resolved/sensor-read-speed.md)** —
  Master-Controlled Mode + trigger-on-read, cutting staleness from ~6.25ms to
  about one I2C round-trip. Implemented in `7d1fb42`/`26e604d`; live
  description is `ARCHITECTURE.md` → "Sensor read timing". One caveat is
  still unverified on hardware (RP2040 `Wire` clock stretching).
- **[`resolved/test-point-standoff-bounds.md`](resolved/test-point-standoff-bounds.md)** —
  `test_forward_model_jacobian_grid`'s `t_z_steps` hardcoded a raw standoff as
  `t.z`, skipping `Positions::magnet_z_pos_from_pivot`, which sent the
  local-frame `z` positive instead of negative — silently exercising
  extrapolation outside the bicubic table instead of the near-table poses
  the sweep was meant to cover. Fixed in `85146bd`; `b545617` went further
  and added `assert_within_bicubic_domain()`, checked against
  `magnet_model_table.h`'s real `BICUBIC_ORIGIN`/`BICUBIC_FAR` extent, to
  every test point in the file so a future out-of-domain point fails loudly
  instead of silently extrapolating.

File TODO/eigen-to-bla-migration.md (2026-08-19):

# Migrate firmware math from Eigen to BasicLinearAlgebra

`TODO/Performance.md` found that Eigen's abstraction actively costs this
target: solver operations don't inline on the RP2040 build (real `bl` calls
into flash-resident Eigen internals, paying a linker-veneer hop from the
RAM-pinned solver), and `jacobian.transpose() * jacobian` was dispatching
into Eigen's general blocked-GEMM kernel for what's actually a 9×6 product
— worked around there by hand-rolling 21 `.dot()` calls instead of trusting
the library. Separately, `BicubicField.cpp` noted "Because Eigen matrix
can't be constexpr" as the reason its basis-weight computation can't be
simplified further.

## Decided

Eigen (`ArduinoEigenDense.h`) has been replaced with `tomstewart89/
BasicLinearAlgebra` ("BLA"; MIT license), **vendored** into
`firmware/lib/BasicLinearAlgebra` (the 5.1.0 release) and patched, across
every firmware file that touched Eigen types. `pio run -e seeed_xiao_rp2040`,
`-e seeed_xiao_rp2040_unity`, and
`pio test -e seeed_xiao_rp2040_test --without-uploading --without-testing`
all build clean. `constexpr` for the bicubic table remains out of scope —
real follow-on work, not bundled into this pass, though vendoring (done here
for the reason below) is a prerequisite for it and no longer blocks it.

### Why vendored: the RAM/flash regression was `Printable`, not floats-vs-doubles

The first pass (non-vendored, straight off the registry) shipped with a real
regression: Flash +11.4% (304,048→338,776 B), RAM +27.6% (64,516→82,296 B).
Root-caused, not guessed: `BLA::MatrixBase` inherits Arduino's `Printable`
(`virtual size_t printTo(Print&) const = 0`, purely so `Serial.print(myMatrix)`
works — nothing in this codebase actually calls it). **Any virtual function
makes every instance of the class
carry a hidden vtable pointer** — 4 bytes per `BLA::Matrix`, which Eigen's
plain-aggregate types never had. Confirmed with `nm` on the ELF: every
`BLA::Matrix<...,...,float>` specialization in use had its own emitted
`vtable for BLA::Matrix<...>` symbol, and the 4,641-entry bicubic table
(`BICUBIC_INTERPOLATION_TABLE`, `NZ*NR` `Vec2`s) measured 12 bytes/entry
instead of the 8 (2 floats) it should be — **+18,564 bytes on that one
array alone, bigger than the entire measured RAM regression.** Confirmed
this wasn't fixable with flags: `--gc-sections` (already on, via the
arduino-pico core's default linker flags) can't remove it because every
constructor of a polymorphic type writes `&vtable` into the object — that's
a real, live reference, not dead code. `-fno-rtti` (also already on) strips
`typeinfo`, a different mechanism from vtables/virtual dispatch entirely.
Neither flag, nor LTO/devirtualization, can shrink `sizeof(BLA::Matrix<...>)`,
because the vtable pointer is a physical object member mandated by the
Itanium C++ ABI the instant a class has any virtual function — that's a
data-layout fact, not something an optimizer is allowed to remove.

Fix: vendored BLA 5.1.0 into `firmware/lib/BasicLinearAlgebra` and dropped
`: public Printable` from `MatrixBase` plus the now-illegal `final` on
`printTo()` (`final` requires actually overriding a virtual, which no
longer exists) in `BasicLinearAlgebra.h`. `printTo()` itself is kept as an
ordinary non-virtual member — still callable directly, just not through
`Printable`'s polymorphic interface. Nothing else touched. Re-measured:
**Flash 298,976 B (−1.7% vs. the pre-migration Eigen baseline, not just vs.
the buggy BLA build), RAM 63,348 B (−1.8% vs. baseline)** — confirmed via
`nm` that zero `vtable for BLA::*` symbols remain, and the bicubic table is
back to exactly 8 bytes/entry (37,128 B total). BLA now beats Eigen on both
axes, which is the result the migration was originally trying to get. (This
comparison was measured at the project's then-current `-O2`; the project
has since moved to `-O3` project-wide, so current flash/RAM numbers live in
`Performance.md`, not here — the `-O2`-vs-`-O2` Eigen/BLA comparison above
is still valid on its own terms, just not directly comparable to the
current build.)

### Verification actually performed

No hardware is available in this environment, so nothing here is verified
on-device. What *was* verified, natively on the host, self-contained scripts
in `/tmp` (not committed — not a reusable harness, just what this pass used):

- **`firmware/test/test_jacobian.cpp` compiled and run natively** (not just
  compiled): all 5 test cases pass, including the 384-point forward-model
  grid sweep. This is the project's stated safety net for the whole solver
  chain, and it passed for real, not just "the build succeeded."
- **`solve_knob_pose()` itself** (not exercised by `test_jacobian.cpp`,
  which only covers the forward model/Jacobians) was checked with a
  synthetic ground-truth pose: generate "measured" fields from a known
  (t, R), perturb the starting guess by a realistic hot-start-sized amount
  (~0.03mm / ~0.3°, matching the real 50Hz hot-started operating regime),
  and confirm the LM loop (BLA `CholeskyDecompose`/`CholeskySolve`,
  `dot()`, `exp_so3` rotation update) converges back to the ground truth:
  position error ~2×10⁻⁵ mm, rotation error ~9×10⁻⁶ (axis-angle proxy).
  **Caveat found along the way**: the same setup with a *large* single-shot
  perturbation (~0.7mm / ~3.5°) diverges badly. Not reproduced against the
  pre-migration Eigen code, so this is not confirmed as a regression — it
  plausibly reflects the fixed-damping (`LAMBDA=0.02`) LM formulation's
  actual convergence basin, which the real system never leaves because it's
  hot-started every frame. Flagging rather than asserting, since it wasn't
  cross-checked.
- **Real ARM build size**, `-e seeed_xiao_rp2040`, measured at each stage:
  Eigen baseline 304,048 B flash / 64,516 B RAM → non-vendored BLA (bug)
  338,776 B / 82,296 B → **vendored+patched BLA 298,976 B / 63,348 B**. See
  "Why vendored" above — root-caused and resolved, not just re-measured.

### API surface actually available (discovered by reading the pinned
### 5.1 release, not just the README or upstream `master`)

The design phase researched `master`, which drifted from what `^5.1`
actually ships. Corrections made during implementation:

- **No `DotProduct` in 5.1** (added to `master` after the 5.1 tag, not in
  any published version). Hand-rolled `dot()` in `math3D.h` instead.
- **No named `.x()`/`.y()`/`.z()` accessors, and no `operator[]`** at all —
  only `operator()(i, j=0)`. Every `v.x()`/`v[i]`-style call site in the
  tree (not just files that said "Eigen" — `Animations.cpp`,
  `SensorController.cpp`, and a `MotionController.h` default member
  initializer were all missed by grepping for the word "Eigen" and only
  caught by the compiler) had to become `v(i)`.
- **Scalar operators deduce `DType` from *both* operands**, not just the
  matrix side: `mat * (some_double_or_int_expression)` fails to compile
  ("deduced conflicting types for parameter DType") unless the scalar is
  already exactly `float`. Bit this twice — `M_PI` (a `double`) multiplying
  a `Vec3`, and `Config::ZERO_SAMPLES` (an `int`) dividing one. Both need an
  explicit `float(...)`/`static_cast<float>(...)`.
- **`Submatrix()`/`Row()`/`Column()` return temporaries**, and BLA's `+=`/
  `-=` are free functions requiring a non-const lvalue — they can't bind to
  those temporaries. `residual.Submatrix<3,1>(0,0) -= x;` doesn't compile;
  `residual.Submatrix<3,1>(0,0) = residual.Submatrix<3,1>(0,0) - x;` does
  (plain `=` is a `RefMatrix` *member*, which works on temporaries).
- **`CholeskyDecompose(H)` factorizes `H` in place** and reports
  `positive_definite` explicitly, rather than degrading silently the way
  Eigen's `.ldlt()` did. Added an explicit check (treated the same as the
  existing NaN/Inf guard) rather than trusting `CholeskySolve` on a
  possibly-non-SPD factorization.
- **Zero runtime bounds/shape checking, in any build mode** — confirmed by
  reading the whole library: the only `assert`s anywhere are two
  `static_assert`s (compile-time). There is no `eigen_assert` equivalent to
  toggle with `NDEBUG`. `firmware/test/README` updated to say so; the test
  env's `build_unflags = -DNDEBUG` still restores plain `assert()`, but
  there's nothing library-specific left for it to unlock.
- `BLA::Matrix`'s storage is natively row-major (`storage[i*Cols+j]`),
  which happens to match both `float[3][3]`'s layout and numpy's
  convention — `CalibrationParams.h`'s `toMat3()`/`toVec3()` went from an
  `Eigen::Map<...,RowMajor>` reinterpret to a plain per-element copy loop,
  simpler than before.
- `Zeros<Rows,Cols,DType>`/`Eye<Rows,Cols,DType>` are the `::Zero()`/
  `::Identity()` replacements — free-standing types convertible into a
  concrete `Matrix<>`, not static factory methods.
- No `.eval()` equivalent needed anywhere: `operator*` (and the other
  arithmetic operators) return a concretely materialized `Matrix<>` by
  value via a plain nested loop, not a lazy expression template. The one
  place Eigen needed `.eval()` (`R = (dR * R).eval();`, guarding against
  self-aliasing) has no analogous hazard under BLA and is now just
  `R = exp_so3(dw) * R;`.

### What changed, file by file

- `math3D.h` is now the single BLA-based source of truth for
  `Vec2`/`Vec3`/`Mat3`/`Vector9f`/`Matrix9x6f`/`Matrix3x6f`, plus the
  hand-written gap-fillers (`dot`, `all_finite`, `cwise_product`,
  `cwise_sqrt`, `identity3`) and the canonical `exp_so3()` (ported out of
  `test_jacobian.cpp`, which now calls the shared one instead of its own
  copy; `solve_pose.cpp` uses it in place of `Eigen::AngleAxisf`).
  Duplicate `using Vector9f = ...`/`Matrix9x6f = ...` redeclarations that
  used to sit independently in `solve_pose.cpp`, `MotionController.h`,
  `test_jacobian.cpp`, and `magnet_model_table.h` are gone — one owner.
- `BicubicField.{h,cpp}`, `magnet_local_model.{h,cpp}`, `virtual_sensor.cpp`,
  `forward_model.{h,cpp}`: mechanical port (`.transpose()`→`~`,
  `.block<>()`→`.Submatrix<>()`, `<<` comma-init→variadic constructor,
  `.asDiagonal()`→direct fill at its one call site).
- `CalibrationParams.h`: `toMat3()`/`toVec3()` simplified as above.
- `solve_pose.cpp`: the highest-risk file, see the API-surface notes above.
- `MotionController.{h,cpp}`, `SensorController.cpp`, `Animations.cpp`,
  `CalibrationStorage.cpp`: caught by the *compiler*, not the original
  audit, since none of them said the word "Eigen" anywhere — they just used
  Vec3/Mat3 with Eigen-specific member syntax. `.determinant()` →
  `BLA::Determinant(...)`.
- `platformio.ini`: `ArduinoEigen` dependency dropped, `EIGEN_NO_MALLOC`
  removed (BLA structurally cannot allocate — plain fixed-size array
  storage, no flag needed), `-DNDEBUG`'s comment corrected to not claim
  it's Eigen-specific.

## Extended: porting the cross-magnet refactor onto BLA

`origin/experimental` did a "full refactor of the forward-model call chain"
(every sensor now sees all three magnets by superposition, not just its
paired one) entirely against Eigen, independently of everything above — it
branched before this migration and never merged it. Re-derived onto BLA
rather than mechanically rebased: read the new code, ported it using the
same idioms this file already established, and re-measured every
hand-unrolling decision fresh rather than assuming the old numbers carried
over. Full context in the branch's plan notes; summarized here for the
file-by-file record this document already keeps.

- **New abstractions, ported using the existing idiom set**:
  `magnet_local_model.{h,cpp}` gained `MagnetModel::place()`, the
  `MagnetPlacement` struct (`near_approx_world`/`far_approx_world`), and the
  brand-new free function `dipole_field(m, r, J)` — none of these existed at
  the previous pass, so there was nothing to port *from*, just fresh BLA code
  written against the conventions already in place (`dot()` for
  `.squaredNorm()`/`.dot()`, `.Column()` for `.col()`, `~R` for
  `.transpose()`, direct `Mat3(...)` fill for `<<`-init).
- **`Mat2` promoted to `math3D.h`**: `BicubicField::evaluate()`'s signature
  collapsed to a single `Mat2&` out-param (was three separate `Vec2&`s), and
  `MagnetModel::evaluate()` needs the same type for its local
  `J_cylindrical` — two genuinely independent call sites, unlike
  `Vector6f`/`Matrix6x6f` (still `solve_pose.cpp`-local, still
  single-use-site even after this pass).
- **`.x()`/`.y()`/`.z()` added to vendored BLA** (`BasicLinearAlgebra.h`'s
  `MatrixBase`, next to its `operator()(i,j=0)` pair). This pass brought in
  enough more Eigen-idiom source in one go (`dipole_field`,
  `MagnetPlacement`'s methods, three new `test_jacobian.cpp` tests) that
  hand-translating every `.x()/.y()/.z()` call site to `(0)/(1)/(2)` — the
  approach the original migration bullet above took — was worse than closing
  the accessor gap once, in the vendored copy we already patch. Const/non-
  const pair mirroring `operator()`, `static_assert`-guarded on shape so
  misuse (`.z()` on a `Vec2`) is a compile error, zero runtime cost (inlines
  to the same `operator()` call). Existing `(i)`-style call sites elsewhere
  are untouched; both idioms are fine going forward.
- **`outer()` added to `math3D.h`**, alongside `dot()`/`cwise_product()`/
  `cwise_sqrt()` in the same "small BLA gap-fillers" group — needed once
  `dipole_field`'s hand-rolled Jacobian was un-hand-rolled into the clean
  outer-product form (see `TODO/Performance.md`'s cross-magnet-refactor
  pass for the measurement).
- **`solve_pose.{h,cpp}`**: `measured_fields` collapsed from a 3-element
  `Vec3[3]` to a single `const Vector9f&`, letting the three
  `Submatrix<3,1>()` subtraction lines become one `residual -=
  measured_fields;` — compile-checked rather than assumed: both operands are
  genuine `Vector9f` lvalues here (not `Submatrix()` views), so BLA's `-=`
  binds fine, unlike the case this file's API-surface notes above describe.
  `Jacobian_out` (the optional out-param) was dropped upstream on
  experimental, orthogonal to BLA; ported as dropped.
- **Host test env formalized**: `origin/experimental` added its own
  `firmware/host_shims/Arduino.h` + `[env:native_test]`, built for
  Eigen (`ArduinoEigen` needs less off-target surface than BLA does). Ported
  by re-deriving the actual required stub surface against BLA's *current*
  (post-`Printable`-patch) include graph rather than assuming the old ad hoc
  `/tmp` scratchpad's stub list still applied — turned out to be exactly
  `__not_in_flash_func` plus a minimal `Print` (for
  `MatrixBase::printTo()` to typecheck against, even though nothing calls
  it), confirmed by grepping the vendored headers' own `#include`s. This
  formalizes, as a committed environment, what the original migration pass
  above did by hand in a session scratchpad.
- **Controllers/states**: mechanical carry-forward of the same patterns
  already in this file's "what changed" list above (`Vec3::Zero()` →
  `BLA::Zeros<3,1,float>()`, `Mat3::Identity()` → `identity3()`, etc.) —
  `MotionController`, `TelemetryController`, `IdleState` had already dropped
  their `last_jacobian`/`rcond` plumbing upstream on experimental, orthogonal
  to BLA.

## Extended: `constexpr` for `BLA::Matrix`

The last item this file's "Open" section left standing — closed by patching
`BLA::Matrix`'s own constructor rather than working around it.

**What changed**: `firmware/lib/BasicLinearAlgebra/ElementStorage.h`'s
variadic fill constructor (`Matrix(DType head, TAIL... args)`) and
`operator()` are now `constexpr`; `BasicLinearAlgebra.h`'s
`MatrixBase() = default` is marked explicitly `constexpr` too, though
testing without the keyword showed it wasn't strictly required — an
explicitly-defaulted special member function is already implicitly
`constexpr` if the implicit definition would qualify, and this one (no
members to initialize) does. Kept explicit as a guarantee rather than
relying on that implicit rule, since a derived `Matrix`'s constexpr
constructor does default-construct this base subobject.
The fill constructor's body used to walk a recursive `FillRowMajor` helper,
writing each element via `operator()` inside the constructor *body* — not
usable in a constexpr constructor, because the standard requires every
member be initialized through the *mem-initializer list*, not just
assigned to in the body. Replaced with mem-initializer aggregate-list
syntax instead: `storage{head, args...}`. Args are already in row-major
order, matching `storage`'s own layout, and — matching FillRowMajor's old
zero-fill base case — any cells past the last argument are zero-initialized
by ordinary C++ aggregate-init rules, for free. `FillRowMajor` itself is
gone; nothing else called it. The plain `Matrix() = default` (no
mem-initializer, used everywhere a matrix is about to be overwritten
in-place, e.g. `solve_pose.cpp`'s locals) was deliberately left alone —
giving it a default member initializer to make *it* constexpr-eligible too
would mean every default-constructed matrix pays for a zero-fill it
usually doesn't need.

### The actual payoff: `BICUBIC_INTERPOLATION_TABLE`, not the basis matrix

Going in, the assumed motivating case was `BicubicField.cpp`'s small 4×4
Catmull-Rom basis matrix — that's the one the file's own comment named. It
turned out to be a red herring for runtime cost (see below), and the real
win was somewhere this document hadn't been pointing at:
`magnet_model_table.cpp` (generated, not hand-edited —
`generate_bicubic_table.py`) defines `BICUBIC_INTERPOLATION_TABLE` as a
`const Vec2[NZ][NR]` — **4,641 individual `Vec2(x, y)` constructions**, all
literal hex-float arguments, going through the exact constructor just
patched. Before this pass, since that constructor wasn't `constexpr`, the
C++ object model required this to be **dynamically initialized**: a real
function (`_GLOBAL__sub_I_BICUBIC_INTERPOLATION_TABLE`, confirmed with
`nm`) ran before `main()` and called the `Vec2` constructor 4,641 times,
writing the results into a `.bss`-resident (RAM) array — confirmed via
`nm`, symbol type `B` at a `0x2000...` address (RP2040 SRAM). This is
exactly the "4,641-entry bicubic table... 37,128 bytes" this document's own
"Why vendored" section already measured as a RAM cost, back when it was
diagnosing the `Printable` vtable regression — it just hadn't been named as
"paying for dynamic initialization" until now.

Once the constructor is `constexpr`, the same declaration (`const`, not
even `constexpr` itself — this is the C++ standard's ordinary "constant
initialization" upgrade for a `const` global whose initializer happens to
be a constant expression, not a new keyword anywhere in
`magnet_model_table.cpp`, which stays untouched) becomes eligible for
**static, compile-time initialization**: the whole table is placed directly
in `.rodata`, no runtime construction, symbol type `R` at a `0x1000...`
address (RP2040 flash, confirmed via `nm`) — and the
`_GLOBAL__sub_I_BICUBIC_INTERPOLATION_TABLE` static-initializer function is
gone entirely, along with whatever code was needed to run 4,641 constructor
calls.

**Measured (clean rebuild, `rm -rf .pio/build .cache`, real
`-e seeed_xiao_rp2040` build, before vs. after this pass, nothing else
changed): Flash 328,208 B → 234,472 B (−28.6%, −93,736 B), RAM 70,888 B →
33,648 B (−52.5%, −37,240 B)** — the RAM delta lands almost exactly on the
table's own 37,128-byte size (the small remainder is other minor layout
shifts), and the flash delta is the removed constructor-call code, which is
far more verbose per byte than the raw packed float data it replaced. This
is a large, real, structural win, not a rounding artifact — reproduced
identically across three independent from-scratch rebuilds before being
trusted (an initial non-`rm -rf`'d build gave a suspicious result that
turned out to just be evidence of exactly this effect, not a caching bug).

**Resolved (follow-up, same pass): moved back to RAM, deliberately.** The
XIP-cache-latency caveat above was real enough that the decision was made
not to leave it to reasoning: `magnet_model_table.cpp`'s definition (and
`bicubic_table.py`'s generator template, so this survives regeneration) now
reads `const Vec2 __not_in_flash("bicubic_table") BICUBIC_INTERPOLATION_TABLE[NZ][NR]`.
`__not_in_flash` (`pico/platform.h`, via `Arduino.h`) is the Pico SDK's
documented mechanism for exactly this — its own doc comment gives "a
`static const` array placed in RAM" as the example — same `.time_critical`
placement `__not_in_flash_func` already uses for `BicubicField::evaluate`
itself, elsewhere in this codebase. Confirmed with `nm`: the table's
symbol moved from `.bss` (RAM, dynamically constructed — the pre-`constexpr`
state) to a `.time_critical`-backed RAM address again, but this time with
**no** static-initializer function at all — `constexpr` still did its job,
the table is a single compile-time-computed image copied into RAM by the
Pico SDK's existing bulk boot-copy, not 4,641 constructor calls. Host stub
(`firmware/host_shims/Arduino.h`) got a matching `__not_in_flash(group)` →
identity macro, mirroring how `__not_in_flash_func` is already stubbed
there.

**Measured**: Flash 234,472 B → 234,464 B (flat — the table's data was
already flash-resident either way, as the load image; RAM-vs-flash-only
just decides whether it's *also* copied to a RAM address), RAM 33,648 B →
70,768 B (back up, table restored to RAM). Against the very first,
pre-`constexpr` baseline (328,208 B / 70,888 B): **Flash −93,744 B (−28.6%),
RAM −120 B (flat)** — the flash win from removing the dynamic-init
constructor calls is kept in full, RAM ends up essentially where it
started, and the XIP-latency caveat is moot because the table isn't read
through XIP at all. `pio test -e native_test` (8/8) and `-e
seeed_xiao_rp2040_test --without-uploading --without-testing` both pass
after this follow-up too.

### The basis matrix: not free, but not the reason to want this

`BicubicField.cpp`'s own local Catmull-Rom `basis` matrix — the case this
comment used to name as the motivation — was made `static constexpr` too,
now that the constructor allows it. **Measured, not assumed: no codegen
change.** Isolated ARM disassembly (real project flags, same method as
`TODO/Performance.md`'s passes) of `BicubicField::evaluate` compiled both
ways — `static constexpr Mat4 basis` vs. the previous plain `const Mat4
basis` — produced a **byte-for-byte identical `.text` section**, not just
an equal call count. `-O3` was already constant-folding this matrix before
the language change: every element is a compile-time literal and nothing
mutates it after construction, which is exactly the case GCC's ordinary
constant propagation already covers without needing the C++ abstract
machine to guarantee it. So the ~7.3-7.5% cost this matrix form still
carries over the hand-expanded scalar form it replaced
(`TODO/Performance.md`'s fourth and fifth passes) is confirmed to live in
the generic 4×4×4×1 multiply itself — which doesn't know most of `basis`'s
entries are 0/±1 the way hand-written scalar code does — not in any
per-call construction cost, which turns out never to have been real at
`-O3`. `constexpr` closes a real language gap here (the type is now usable
where a constant expression is required, and its compile-time-ness is a
guarantee rather than an optimizer's discretion) but this specific call
site's runtime cost is unchanged and not expected to be revisited by this
change. The lesson this leaves for the file: a *local* matrix built from
literals was already free under `-O3` regardless of the C++ keyword; a
*global* one wasn't, because dynamic-vs-static initialization is a language
rule the optimizer can't route around no matter how obviously-constant the
values are.

**Verification**: a standalone `static_assert(basis(0,0) == 0.0f, ...)`-style
check confirms `BLA::Matrix`'s fill constructor is now genuinely usable in
a constant expression, not just accepted syntactically. `pio test -e
native_test` (all 8 cases, unchanged pass/fail) and `pio test -e
seeed_xiao_rp2040_test --without-uploading --without-testing` both
pass/build clean (one pre-existing `-Wnarrowing` warning newly surfaced at
`SensorController.cpp`'s `Vec3(0.1, 0.1, 0.1)` call — aggregate-list
initialization checks narrowing more strictly than the old body-assignment
form did; the double-to-float narrowing itself isn't new, just now visible;
not fixed here, out of scope for this pass). Real ARM build numbers above.

## Open

- ~~Whether BLA actually inlines better than Eigen did, and whether any of
  `TODO/Performance.md`'s hand-unrolled optimizations can come back out now
  that Eigen's gone~~ — done, see `TODO/Performance.md`'s fourth pass and
  later ones: BLA's `CholeskyDecompose`/`CholeskySolve`/`dot()` inline
  completely (Eigen's equivalent never did). **All four checked candidates
  (the original three, plus `dipole_field`'s Jacobian, new in the
  cross-magnet refactor) are on their clean `BLA` forms.** `H = JᵀJ` was a
  pure inlining-level artifact of the project's `-O2` and is free at `-O3`
  (which the project now builds at project-wide) — re-verified byte-for-byte
  identical in the cross-magnet-refactor pass, since `jacobian`'s 9x6 shape
  never changed. The written-out skew products needed `-O3` and
  `-ffinite-math-only` together to reach parity — a scoped-pragma attempt
  fell short on the real build and was reverted, but going
  `-ffinite-math-only` project-wide (with a bit-level `is_finite_bits()`
  check in `math3D.h` protecting the NaN/Inf safety net from that flag)
  reached exact parity; re-verified again under the cross-magnet refactor's
  3-way-summed call shape (still exact parity, 60 calls either way — the
  "changed surrounding code might break this" worry raised going in did not
  materialize here, but was checked rather than assumed). The bicubic
  basis-weight computation — separate from the *hoisting* question this
  bullet originally meant, see `TODO/Performance.md`'s correction — was also
  un-hand-rolled into a matrix form, but that one is not free: measured
  ~7.5% more soft-float calls than the scalar version it replaced under the
  original three-out-param signature, and ~7.3% (352 vs. 328) re-measured
  under the cross-magnet refactor's collapsed `Mat2&`-out-param signature —
  consistent, not a new regression from the signature change. Kept anyway
  per the standing "remove all hand-unrolling" decision. `dipole_field`'s
  Jacobian (brand-new in the cross-magnet refactor, never assessed before)
  turned out to be the pleasant surprise of the four: the clean unreduced
  outer-product form (`outer()`, new in `math3D.h`) measured 65 calls
  against the hand-rolled 6-of-9-then-mirror form's 67 — not just free,
  slightly cheaper.
- **On-device verification.** Nothing here has run on real hardware. The
  host-native numeric checks (above) are strong evidence of correctness but
  are not a substitute for `pio test -e seeed_xiao_rp2040_test` actually
  uploading and running on the RP2040.
- **The large-perturbation solver divergence noted above** — worth a
  deliberate look (or an explicit "out of scope, hot-start-only" note)
  rather than leaving it as an incidental finding from an ad hoc check.
- ~~`constexpr` for the bicubic table (the thing that originally motivated
  looking at alternatives to Eigen) is still not done~~ — done, see the
  `constexpr` extended section above. `BLA::Matrix`'s literal-list
  constructor is now `constexpr`; the real payoff wasn't the small local
  basis matrix this bullet used to picture, but `magnet_model_table.cpp`'s
  4,641-entry `BICUBIC_INTERPOLATION_TABLE`, which moved from a dynamically-
  initialized RAM array to true compile-time `.rodata`: Flash 328,208 B →
  234,472 B, RAM 70,888 B → 33,648 B. On-device latency impact of the table
  now living in flash instead of RAM is unverified — see that section.
- **Vendored code needs a way to stay in sync with upstream on purpose.**
  There's no process yet for noticing if upstream BLA fixes a bug this copy
  also has, or for re-applying the `Printable` patch if someone re-vendors
  from a newer release. Worth at least a comment pointing back to this file
  from `firmware/lib/BasicLinearAlgebra/BasicLinearAlgebra.h` (already
  added) and, longer-term, a real process if this needs to move past 5.1.0.

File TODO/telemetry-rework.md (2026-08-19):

# Telemetry rework

Originated from ARCHITECTURE.md issues #7 and #8, merged into one effort per
discussion.

## Issue A: `rcond` is a hardcoded stub — RESOLVED

Done, upstream of this pass: `IdleState.cpp`'s `float rcond = 1.0;` stub and
its commented-out `jacobiSvd()` line are gone, and
`TelemetryController::publish()` no longer takes an `rcond` parameter at
all (the cross-magnet-refactor branch dropped both; ported as dropped, see
`TODO/eigen-to-bla-migration.md`'s "Extended" section).

## Issue B: `TelemetryController::publish()`'s signature keeps growing

Currently 8 parameters (`motion`, `residual_percent`, `buttonBits`,
`hidReportSent`, `stats`, `raw_field`, `last_pos`, `last_rot` — `rcond` is
gone, Issue A above) in
`firmware/include/controllers/TelemetryController.h` /
`firmware/src/controllers/TelemetryController.cpp`, and it's grown with every
diagnostic added so far. 

## Issue C: we want more telemetry.
Specifically, we want to know the number of iterations the solve took.
Ideally we want some idea of how well the solve did (e.g. optimiality of the 
jacobian, or something based on the local gradient).

The work here isn't just threading this data into the telemetry, but also figuring out how to display it.

## Issue D: profiling
We want to be able to profile things.
For that, we should have a separate end-point at the telemetry controller (in the header, for inlining)
to submit such information. With a separate way to get the profile information out.

The interface should have a header-defined struct of things to profile. With one entry per interesting thing.
Then at the call site we do: `telemetry.profile(ENUM_CONSTANT_THAT_DEFINES_OPERATION).start()` before
and `telemetry.profile(ENUM_CONSTANT_THAT_DEFINES_OPERATION).stop()` after.
Start just subtracts the current time from the accumulator, and stop adds the current time to the accumulator.
Stop also increments a total runs counter.

Some extra work to allow turning these function calls for a specific operation into a no-op would also be nice.

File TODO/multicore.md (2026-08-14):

# Put the RP2040's second core to work

The Seeed XIAO RP2040 is dual-core (`ARCHITECTURE.md`'s platform note), but
`firmware/src/main.cpp` only ever defines `setup()`/`loop()` — the
Earle Philhower core's `setup1()`/`loop1()` hooks for the second core are
never defined, so everything (`hidController().task()`,
`serialController().update()`, the whole state machine, and inside
`IdleState` the sensor read + `solve_knob_pose()` + HID/telemetry) runs
serially on core0. Core1 sits idle.

## Why it matters

Mostly: performance. If the solve can run without needing to wait for other
things, then the solve runs faster and we get more updates (or a more complex
solve).

Another reason:
Sensor staleness and loop rate are currently coupled to *everything* the
firmware does. The sensors are already in Master-Controlled Mode with
trigger-on-read, so a read is fresh to within about one I2C round-trip — but
that only holds if reads keep happening promptly, and today each read waits
its turn behind the LM solve (`TODO/Performance.md`: ~7.5ms/call standalone,
whole loop at ~80Hz/12.5ms as of the last measurement), HID, and telemetry on
the one core. Moving the solve off core0 decouples the two: the sensor loop
can cycle as fast as I2C allows, and the solver can run flat out instead of
once per tick.

## Design

Nothing here is implemented or settled — this is the intended shape, and the
open questions below are load-bearing rather than cosmetic.

Core1 runs `solve_knob_pose()` continuously, back-to-back, independent of
core0's tick rate — not once per `IdleState::update()` call the way it runs
today. Core0's superloop keeps its current shape (state machine, HID,
serial, LED) but owns sensor I/O as a tight read-and-publish loop; the solve
itself moves entirely to core1.

**Three kinds of data cross the core boundary.** Two of them have the shape
below — a double buffer plus one lock-guarded monotonic counter. The third,
telemetry, does not fit that shape and is the main undesigned piece; see the
open questions.

- **Sensor channel (core0 → core1).** Core0 writes each completed sensor
  reading into whichever of two buffers isn't the currently-published one,
  then locks a counter `L_sensor`, increments it, unlocks. `L_sensor`'s
  parity says which buffer holds the latest complete reading.
- **Pose channel (core1 → core0).** Same shape, reversed: core1 writes the
  solved pose into the off-buffer, then locks/increments/unlocks `L_pose`.
- **Telemetry (core1 → core0).** Needed, but neither the same size nor the
  same rate as a pose, so it can't just be a third instance of the above.
  Undesigned.

**The reader holds the lock across its copy**, not just across reading the
counter: lock, read the counter, copy the buffer its parity selects, unlock.
That is what makes the scheme airtight rather than merely probable. While the
reader holds the lock the writer cannot increment, so the published parity
cannot change mid-copy, so the buffer the writer is filling
(`1 - parity`) stays disjoint from the buffer the reader is copying
(`parity`) for the whole copy. The writer never blocks on the payload — only,
briefly, on the counter increment at the end of its own write, and only when
a read is in flight at that exact moment.

The payload buffers themselves are therefore never locked, and no assumption
about relative speeds is needed: correctness comes from the lock interval,
not from the writer being too slow to lap the reader.

A single RP2040 hardware spinlock per channel (`hardware/sync.h`:
`spin_lock_claim`/`spin_lock_blocking`/`spin_unlock`) looks like the right
primitive — no allocation, and the critical section is a counter read plus a
handful of floats. Note `spin_lock_blocking()` disables interrupts on the
holding core for the duration, so the copy staying small is load-bearing; a
pose or a 9-float sensor frame is comfortably inside that budget, a
`Statistics` struct would not be — which is most of why telemetry needs its
own answer.

**No separate "solve done" notification is planned.** `L_pose` already carries
it: core0 remembers the value it last consumed and compares after each locked
read. That is freshness detection for free, and it matters beyond saving
work — `Config::SMOOTH_TAU_S`'s low-pass is dt-based and assumes each tick's
pose is a genuinely new sample, so silently re-consuming an unchanged pose
would corrupt the filtered output, not merely waste a copy. An inter-core
FIFO doorbell would add nothing the counter comparison doesn't already give.

Running the solve continuously rather than once per core0 tick also
simplifies hot-start: `MotionController::last_R` and the translation
hot-start become core1's own loop-local state between iterations, no longer
something threaded across the core boundary every tick.

### Alternative buffering strategies
We might consider triple-buffering. This way the reader can hold one buffer 
locker for reading, and the writer can just switch between the two non-locked
buffers for writing. This way we can have at the same time:
- A buffer with a fresh value
- A buffer actively being written to
- A buffer actively being read from.

This allows a reader to lock a buffer for as long as it needs, so there is no 
need for a reader to copy data to a local buffer.

**Downside** the accounting gets a bit more complicated, because the index of 
the fresh buffer is no longer just the number of writes mod 2 (or 3). This also
requires more locks, which might hurt performance more than we gain by reducing
(potentially very low) lock contention for buffers.

## Open questions

- **What shape the telemetry channel takes.** The third channel above, and
  the one with no answer yet. It can't be another instance of the
  double-buffer pattern as-is: `Statistics` (`MotionController.h`) is far
  bigger than a pose, and the spinlock-held copy only stays cheap while it's
  small. `TelemetryController` also only wants it every 20 ticks, not every
  solve, so it differs in rate as well as size. In its favour, a torn or
  stale telemetry frame is cosmetic where a torn pose is not, so it can
  probably take a cheaper discipline than the other two rather than a bigger
  one. Also open: which fields actually need to cross at all.
- **`Statistics::last_jacobian` should probably not exist by then.** It is a
  9x6 float matrix (216 bytes) that `MotionController::compute()` still hands
  to `solve_knob_pose()` as an out-param on every solve
  (`MotionController.cpp:127`, gated on `Config::statistics`), but nothing
  reads it — the only consumer is the commented-out `jacobiSvd()` line at
  `IdleState.cpp:51`. (The `avg_jacobian` EMA was deleted in the third
  optimization pass; this is the other one, still written.) Dropping `rcond`
  per `TODO/telemetry-rework.md`'s Issue A removes that last would-be
  consumer, at which point the member and the per-solve write can both go —
  which is worth doing *before* sizing the telemetry channel, so 216 bytes of
  dead weight doesn't get designed into the cross-core copy.
- **Which primitive for the lock.** Confirm arduino-pico exposes
  `hardware/sync.h`'s hardware spinlocks directly rather than only the
  heavier, allocation-touching `mutex_t`.
- **How this interacts with calibration.** Tare (`CalibratingState`,
  `TODO/tare-and-calibration.md`) and bundle calibration (`BundleState`) both
  drive sensor reads outside the normal `IdleState` tick, and tare
  additionally drives a pose solve directly, per-sample, from
  `SensorController::updateCalibration()` — deliberately with a *fixed*
  identity starting guess rather than the hot-start state, which a
  free-running core1 solver does not naturally provide. So tare can't simply
  consume core1's pose stream; it needs either its own synchronous solve or a
  way to ask core1 for a cold-started one. Likely wants settling alongside the
  tare redesign rather than before it.
- **Whether core0 needs to own sensor I/O at all**, versus core1 calling
  `SensorController::read_mT()` itself and skipping the sensor channel
  entirely. Written up above as "core0 owns sensor I/O" per the design as
  described; worth confirming that split is intentional. The tradeoff is that
  core1 would then block on I2C inside its solve loop, which is exactly the
  coupling this change is meant to remove.

## Not started

No implementation exists yet. Beyond the open questions above: buffer struct
layout, `hardware/sync.h` availability under arduino-pico, and where
`setup1()`/`loop1()` and the channels get declared in
`main.cpp`/`Controllers.h` are all still undecided.

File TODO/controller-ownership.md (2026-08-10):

# Fix controller ownership / coupling around the pose pipeline

Originated from ARCHITECTURE.md issues #4 and #5. Confirmed as real
architectural issues, not just style nits.

## Problem 1: `SensorController` ↔ `MotionController` circular coupling

`SensorController.cpp` does:

```cpp
extern MotionController motionController;
```

and calls `motionController.read_pose()` / `motionController.set_base_pose()`
directly from inside `SensorController::updateCalibration()`. Meanwhile
`MotionController::compute()` separately depends on
`SensorController::baseline()`. Every other cross-controller interaction goes
through the state layer (e.g. `IdleState` explicitly reads from
`sensorController` and pushes into `motionController` — neither controller
reaches into the other). This one pair breaks that pattern and calls each
other directly, so the dependency direction between them is ambiguous, and
`SensorController` can't be reasoned about or tested without pulling in the
entire motion/solver stack.

Likely fix shape: move whatever `updateCalibration()` needs
(`read_pose`/`set_base_pose`) up into the state that orchestrates
calibration (see `TODO/tare-and-calibration.md` — this will need to be
resolved together with the tare redesign, since tare is exactly the state
that currently drives this calibration loop).

## Problem 2: the forward model's state lives outside any controller — RESOLVED

Fixed as part of the `CalibrationParams` work. `MotionController` now owns a
`const ForwardModel forward_model_` member, constructed from the
`CalibrationParams` the controller was built with; `J`/`B_field` were dead and
are deleted. `MotionController` and `SensorController` are each reached
through their own Meyers-singleton accessor, `motionController()` /
`sensorController()` (`firmware/include/Controllers.h`), independently built
on first call from `resolveCalibration()` at a point `setup()` chooses — which
is what gives a flash-loaded calibration somewhere to land. The original
description follows, for context.

In `firmware/src/controllers/MotionController.cpp`, at file scope (not class
members):

```cpp
MagnetModel magnets[3] = { ... };
const Sensor sensors[3] = { ... };
ForwardModel forward_model(sensors, magnets);
Eigen::Matrix<float, 9, 6> J;        // declared, appears unused — dead, check and remove
Eigen::Matrix<float, 9, 1> B_field;  // declared, appears unused — dead, check and remove
```

Every other controller owns its dependencies as class members
(`SensorController` owns its 3 sensor objects as members, for instance). Here
the actual math model — the thing the whole solver pipeline runs against — is
a translation-unit global, built once from `Config` constants at static-init
time, invisible to any header, with no accessor and no way to reconstruct or
mutate it at runtime.

This matters beyond style: it's the reason there's currently no path for a
future calibration write-back (see `TODO/sensor-gain-calibration.md`) to ever
reach the running `Sensor`/`MagnetModel` instances — they're not reachable
from anywhere calibration code could plug into.

Likely fix shape: `MotionController` (or a new owner, depending on how
`TODO/sensor-gain-calibration.md` resolves) should own `sensors`, `magnets`,
and `forward_model` as members, constructed from whatever config/calibration
source is decided, with `J`/`B_field` either wired to an actual use or
deleted.

## Problem 3: `BundleCalibrationController` mixes both access patterns — RESOLVED

Not actually an inconsistency: `BundleState.cpp` already documents why
`SensorController` comes in as an explicit parameter to `update()` instead of
through `sensorController()` — "so the callibrator can be selective in when
it wants to read the sensor." That's a deliberate reason for the split, not
two competing access patterns with none. The original description follows,
for context.

Every controller is reached through its own accessor function (`ledController()`,
`sensorController()`, ...) declared in `Controllers.h` — that's the project's
one consistent access pattern, and all five `State` subclasses use it. But
`BundleCalibrationController` mixes two different ways of getting at its
dependencies: it calls `ledController()` directly from inside `change_phase()`,
while `SensorController` instead comes in as an explicit parameter —
`BundleCalibrationController::update(uint16_t button_bits, SensorController
&sensorController)`, passed in by `BundleState::update()`
(`firmware/src/states/BundleState.cpp`) — even though `sensorController()` is
sitting right there and would work exactly the same way `ledController()`
does. So within this one class the access pattern is inconsistent, with no
apparent reason for the split (e.g. `LEDController` isn't more "shared" or
`SensorController` more "test-isolated" in any way that's evident from the
code).

(An earlier version of this section also flagged `SensorController.cpp`
reaching `MotionController` via its own inline `extern MotionController
motionController;` instead of going through `Controllers.h` like everyone
else. That's now fixed — `SensorController.cpp` includes `Controllers.h` and
calls `motionController()` like everything else does, as part of the same
accessor-function migration that resolved Problem 2.)

## Note

These two problems are linked: fixing #2 (giving the forward model a real
owner) will likely reshape how #1 gets resolved, since "who owns the model"
and "who's allowed to call into the solver during calibration" are the same
question from two directions. Worth designing together rather than
sequentially.

In the event #2 was resolved without touching #1. Giving the model an owner
turned out not to require deciding who may call into the solver — the call in
`updateCalibration()` just got re-spelled as `motionController().read_pose()`
and is as coupled as it ever was. #1 remains open and still belongs with the
tare redesign.

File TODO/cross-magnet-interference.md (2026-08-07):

# Model cross-magnet interference

**Measured: 1.7–4.5% of the field, growing with knob-to-sensor distance.**
The "quantify it first" step below has been done, against all three captured
runs in `magnet_field_model/calibration_runs/`. The Python fit already models
all three magnets per sensor, so the term is directly extractable by comparing
its full prediction against just the paired-magnet contribution:

| \|t\| (mm) | cross-magnet share |
|---|---|
| 18.73 | 1.82% |
| 19.95 | 2.93% |
| 21.12 | 4.03% |

It grows with distance because the paired magnet's own field falls off fast
while the other two, ~28.58mm away, barely change — so their relative share
rises as the knob lifts.

**Currently worked around, not fixed.** Feeding parameters fitted under the
physically complete model into the firmware's single-magnet model leaves
exactly this term uncompensated — measured at **3.6%** field error on captured
data, and observed on hardware as a pose-residual regression from ~1% to ~3%
after applying a calibration. The workaround is
`calibration/bundle_geometry.py`'s `SENSOR_MAGNET_COUPLING`, set to
`PAIRED_ONLY` so the fit matches the firmware exactly; that brings the same
comparison to **0.49%**.

Two things worth knowing before picking this up:

- The workaround costs **absolute field scale**. Cross-talk is what separates
  magnet *strength* from magnet *distance* (a strength change scales the near
  and far contributions equally; a z-shift changes them at very different
  rates). Without it the two are near-degenerate over the ~3mm of heave the
  hardware gives, and `magnet_strength_mean`'s posterior sd roughly triples.
  The fit reports this honestly rather than hiding it — see
  `test_absolute_strength_needs_cross_magnet_coupling`.
- It does **not** cost fit quality. The single-magnet fit reaches 0.336%
  residual against 0.339% for the complete model, so at these pose ranges
  cross-talk is almost entirely absorbable into effective gain/offset/strength.
  What is lost is the physical meaning of the fitted numbers, not the fit.

So the case for doing this work is now "recover physically meaningful
parameters and absolute field scale", not "reduce pose residual" — the
workaround already handles the latter. Implementing it is a one-constant
switch back to `ALL_MAGNETS` on the Python side, plus the firmware work below.

## The problem

`ForwardModel::evaluate()` (`firmware/src/magnet_model/forward_model.cpp`)
pairs each sensor with exactly one magnet — `sensors_[i]` is only ever
evaluated against `magnets_[i]` — via `MagnetModel`'s near-field bicubic
lookup (`BicubicField`, built from a `magpylib` simulation of a single
isolated 6x6mm cylinder magnet, valid over the grid's `(r, z)` domain relative
to *that* magnet). The field each sensor actually sees from the *other* two
magnets — real physical magnets ~28.58mm away (the knob's triangle side
length, `Positions::triangle_sidelength_mm`) — is entirely unmodeled. That's
the cross-magnet interference this TODO is about: not a bug, a deliberately
missing higher-order term.

## Proposed approach, if it turns out to matter

Keep the implementation cost low by not extending the expensive part (the
bicubic near-field table) to cover cross terms. Instead:

- Add a dipole model to the magnet class (`MagnetModel`,
  `firmware/{include,src}/magnet_model/magnet_local_model.*`) — the standard
  closed-form ideal magnetic dipole field, valid in the far field where these
  cross terms live (28mm separation is comfortably far-field relative to a
  6mm magnet).
- Use that direct dipole formula (and its closed-form Jacobian — the solver
  needs analytic Jacobians everywhere, same as every other `evaluate()` in
  this chain, see `firmware/test/test_jacobian.cpp`) to estimate each sensor's
  field contribution *from the two non-paired magnets*, and add it as a
  correction on top of the existing near-field bicubic evaluation for the
  paired magnet.
- This keeps the added cost cheap on purpose: a closed-form dipole evaluation
  is far cheaper than a bicubic interpolation, so adding ~2 extra
  dipole evaluations per sensor per solver iteration should be a minor
  addition next to the existing 3 bicubic lookups, not a multiplier on the
  expensive part of the pipeline.

## Open questions

- Where the dipole moment magnitude comes from, and whether it needs to match
  (or be separately calibrated from) whatever moment the near-field
  `magpylib` simulation used — inconsistency between the two would show up as
  a discontinuity/bias right at the boundary where the near-field model
  hands off to the dipole approximation.
- Whether per-magnet moment strength here should tie into the same
  per-magnet strength correction bundle calibration is meant to produce (the
  "Phantom Tilt" problem in `design documentation/context.md`) rather than
  being a separate constant.
- Whether this belongs on `MagnetModel` itself (a mode/flag) or as a
  separate lightweight class that `ForwardModel` composes in for the
  non-paired magnet terms.

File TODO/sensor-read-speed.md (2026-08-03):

# Switch sensors to Master-Controlled Mode for faster, fresher reads

`SensorController` never calls `setPowerMode()`, so all three TLI493D-A2B6
sensors sit in the power-on-reset default: Low Power Mode. `MOD2.PRD` resets
to `0B` ("fast" per the register description) — inferred, not spec-confirmed
against an explicit Hz table, to mean the higher of the datasheet's two
listed rates: 160 Hz, i.e. a worst-case ~6.25ms staleness today regardless of
poll rate. The PCB is fixed/bought: all three sensors' `SCL/INT` pins share
one net wired only to the MCU's plain I2C `SCL` — no `/INT` GPIO, and one
wouldn't help anyway with three sensors converting independently on the same
line. So synchronization has to happen over the I2C bus itself.

## Decision

Move all three sensors to Master-Controlled Mode (`MOD1.MODE = 01B`).
Trigger each conversion with trigger-bits `100B` ("trigger after register
05H") appended to the same read that fetches the previous measurement — one
transaction both retrieves data and re-arms the next conversion. This is
compatible with the driver's existing `CA=0`/`INT=1` config (clock
stretching enabled, /INT disabled, already handling synchronization safely
across the shared bus); only trigger-bits `010B`/`011B` (trigger-before-read)
are excluded with that config, not `100B`. Expected staleness is about one
round-trip across the three sensors — under 1ms, a >6x improvement on
today's ~6.25ms, and accepted as fine for now. It'll creep up as more work
lands on the single core, but that's `TODO/multicore.md`'s problem, not
this one.

## Round shape

1. Read sensor 1, sensor 2, sensor 3 in turn — full register block
   (00H–06H), trigger-bits `100B` on each read. Every read both harvests
   the prior result and re-arms that sensor's next conversion.
2. Check the parity/status bits included in that block; discard/flag
   anything invalid (expected on the very first round after switching
   modes, before any conversion has run yet).
3. Repeat continuously — clock stretching covers the case where a
   conversion isn't quite done by the time its turn comes back around (in
   steady state it should always be done: 3 reads at 400kHz take ~600us,
   longer than the ~175-240us typical conversion time).

## Open questions

- Does the Infineon Arduino library expose the per-frame trigger bits, or
  does this need a raw register write? `getMagneticFieldAndTemperature()`
  may not support it.
- Does the RP2040 Arduino `Wire` library actually honor I2C slave clock
  stretching? Unverified on real hardware, and this design depends on it.
- Keep I2C clock at 400kHz — Master-Controlled Mode doesn't need Fast
  Mode's >=800kHz, and raising it risks signal integrity with 3 sensors
  sharing the bus's fixed 1.2kOhm pull-ups.

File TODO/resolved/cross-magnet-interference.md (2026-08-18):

> **RESOLVED — implemented, archived for the reasoning.**
>
> The firmware models cross-magnet interference. `ForwardModel::evaluate()`
> now evaluates every sensor against every magnet: its own through the
> bicubic near field, the other two through `dipole_field()`, a closed-form
> point dipole — the approach this file proposed. `SENSOR_MAGNET_COUPLING` in
> `calibration/bundle_geometry.py` is back to `ALL_MAGNETS`, so the fit and
> the firmware describe the same physics again.
>
> The live description is **`design documentation/Math.md` §3.6 and §4.E**
> for the model and its Jacobian, and **`ARCHITECTURE.md`** for where it sits
> in the pipeline. This file is kept for the measurements and for why the
> workaround existed.
>
> On the open questions at the bottom: the moment comes from the same
> polarization and volume the bicubic table is generated at, scaled by the
> same per-magnet strength ratio, so the two models cannot describe magnets
> of different strength (`DIPOLE_MOMENT_AT_REFERENCE_MT_MM3`). It went on
> `MagnetModel` as a free function plus two precomputed members rather than a
> separate class. There is no handoff discontinuity to worry about: the
> paired magnet and the cross magnets occupy ranges that never overlap, so
> the two models are never both in play at one distance.
>
> **Not verified on hardware.** The numbers below were measured on captured
> data and the firmware reproduces them (1.54/2.76/4.83% across the standoff
> range), but nothing here has run on a board, and the cost question this
> file did not ask — whether nine pairs still fits the solver's timing budget
> — is open. Static estimates suggest ~+40%; `TODO/Performance.md` is
> explicit that those are not a substitute for a `micros()` reading.

---

# Model cross-magnet interference

**Measured: 1.7–4.5% of the field, growing with knob-to-sensor distance.**
The "quantify it first" step below has been done, against all three captured
runs in `magnet_field_model/calibration_runs/`. The Python fit already models
all three magnets per sensor, so the term is directly extractable by comparing
its full prediction against just the paired-magnet contribution:

| \|t\| (mm) | cross-magnet share |
|---|---|
| 18.73 | 1.82% |
| 19.95 | 2.93% |
| 21.12 | 4.03% |

It grows with distance because the paired magnet's own field falls off fast
while the other two, ~28.58mm away, barely change — so their relative share
rises as the knob lifts.

**Currently worked around, not fixed.** Feeding parameters fitted under the
physically complete model into the firmware's single-magnet model leaves
exactly this term uncompensated — measured at **3.6%** field error on captured
data, and observed on hardware as a pose-residual regression from ~1% to ~3%
after applying a calibration. The workaround is
`calibration/bundle_geometry.py`'s `SENSOR_MAGNET_COUPLING`, set to
`PAIRED_ONLY` so the fit matches the firmware exactly; that brings the same
comparison to **0.49%**.

Two things worth knowing before picking this up:

- The workaround costs **absolute field scale**. Cross-talk is what separates
  magnet *strength* from magnet *distance* (a strength change scales the near
  and far contributions equally; a z-shift changes them at very different
  rates). Without it the two are near-degenerate over the ~3mm of heave the
  hardware gives, and `magnet_strength_mean`'s posterior sd roughly triples.
  The fit reports this honestly rather than hiding it — see
  `test_absolute_strength_needs_cross_magnet_coupling`.
- It does **not** cost fit quality. The single-magnet fit reaches 0.336%
  residual against 0.339% for the complete model, so at these pose ranges
  cross-talk is almost entirely absorbable into effective gain/offset/strength.
  What is lost is the physical meaning of the fitted numbers, not the fit.

So the case for doing this work is now "recover physically meaningful
parameters and absolute field scale", not "reduce pose residual" — the
workaround already handles the latter. Implementing it is a one-constant
switch back to `ALL_MAGNETS` on the Python side, plus the firmware work below.

## The problem

`ForwardModel::evaluate()` (`firmware/src/magnet_model/forward_model.cpp`)
pairs each sensor with exactly one magnet — `sensors_[i]` is only ever
evaluated against `magnets_[i]` — via `MagnetModel`'s near-field bicubic
lookup (`BicubicField`, built from a `magpylib` simulation of a single
isolated 6x6mm cylinder magnet, valid over the grid's `(r, z)` domain relative
to *that* magnet). The field each sensor actually sees from the *other* two
magnets — real physical magnets ~28.58mm away (the knob's triangle side
length, `Positions::triangle_sidelength_mm`) — is entirely unmodeled. That's
the cross-magnet interference this TODO is about: not a bug, a deliberately
missing higher-order term.

## Proposed approach, if it turns out to matter

Keep the implementation cost low by not extending the expensive part (the
bicubic near-field table) to cover cross terms. Instead:

- Add a dipole model to the magnet class (`MagnetModel`,
  `firmware/{include,src}/magnet_model/magnet_local_model.*`) — the standard
  closed-form ideal magnetic dipole field, valid in the far field where these
  cross terms live (28mm separation is comfortably far-field relative to a
  6mm magnet).
- Use that direct dipole formula (and its closed-form Jacobian — the solver
  needs analytic Jacobians everywhere, same as every other `evaluate()` in
  this chain, see `firmware/test/test_jacobian.cpp`) to estimate each sensor's
  field contribution *from the two non-paired magnets*, and add it as a
  correction on top of the existing near-field bicubic evaluation for the
  paired magnet.
- This keeps the added cost cheap on purpose: a closed-form dipole evaluation
  is far cheaper than a bicubic interpolation, so adding ~2 extra
  dipole evaluations per sensor per solver iteration should be a minor
  addition next to the existing 3 bicubic lookups, not a multiplier on the
  expensive part of the pipeline.

## Open questions

- Where the dipole moment magnitude comes from, and whether it needs to match
  (or be separately calibrated from) whatever moment the near-field
  `magpylib` simulation used — inconsistency between the two would show up as
  a discontinuity/bias right at the boundary where the near-field model
  hands off to the dipole approximation.
- Whether per-magnet moment strength here should tie into the same
  per-magnet strength correction bundle calibration is meant to produce (the
  "Phantom Tilt" problem in `design documentation/context.md`) rather than
  being a separate constant.
- Whether this belongs on `MagnetModel` itself (a mode/flag) or as a
  separate lightweight class that `ForwardModel` composes in for the
  non-paired magnet terms.

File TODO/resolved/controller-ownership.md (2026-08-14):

> **RESOLVED — archived for the reasoning.**
>
> All three problems below are closed:
>
> - **Problem 2** (forward model living at translation-unit scope) was fixed
>   by the `CalibrationParams` work — `1883bc2` gave the calibration an owner
>   and `20f5f4d` replaced the controller globals with per-controller
>   accessors. `MotionController` now holds a `const ForwardModel` member.
> - **Problem 3** is closed by code: `BundleCalibrationController::update()` no
>   longer takes a `SensorController&`: it reaches for `sensorController()` like
>   it already did for `ledController()`, so the class uses one access pattern
>   throughout. The "only read the sensors if we need them" rationale that the
>   parameter used to carry now sits at the read itself in
>   `BundleCalibrationController.cpp`.
> - **Problem 1** is closed by decision rather than by code change: no
>   controller owns another, and reaching a sibling through its
>   `Controllers.h` accessor is the project's sanctioned pattern. The thing
>   that was actually wrong — `SensorController.cpp`'s inline
>   `extern MotionController motionController;`, bypassing the accessors — is
>   gone. The `motionController().read_pose()` call in `updateCalibration()`
>   stays and is fine.
>
> The live statement of the rule is **`ARCHITECTURE.md` → "Controllers"**.

---

# Fix controller ownership / coupling around the pose pipeline

Originated from ARCHITECTURE.md issues #4 and #5. Confirmed as real
architectural issues, not just style nits.

## Problem 1: `SensorController` ↔ `MotionController` circular coupling

`SensorController.cpp` does:

```cpp
extern MotionController motionController;
```

and calls `motionController.read_pose()` / `motionController.set_base_pose()`
directly from inside `SensorController::updateCalibration()`. Meanwhile
`MotionController::compute()` separately depends on
`SensorController::baseline()`. Every other cross-controller interaction goes
through the state layer (e.g. `IdleState` explicitly reads from
`sensorController` and pushes into `motionController` — neither controller
reaches into the other). This one pair breaks that pattern and calls each
other directly, so the dependency direction between them is ambiguous, and
`SensorController` can't be reasoned about or tested without pulling in the
entire motion/solver stack.

Likely fix shape: move whatever `updateCalibration()` needs
(`read_pose`/`set_base_pose`) up into the state that orchestrates
calibration (see `TODO/tare-and-calibration.md` — this will need to be
resolved together with the tare redesign, since tare is exactly the state
that currently drives this calibration loop).

## Problem 2: the forward model's state lives outside any controller — RESOLVED

Fixed as part of the `CalibrationParams` work. `MotionController` now owns a
`const ForwardModel forward_model_` member, constructed from the
`CalibrationParams` the controller was built with; `J`/`B_field` were dead and
are deleted. `MotionController` and `SensorController` are each reached
through their own Meyers-singleton accessor, `motionController()` /
`sensorController()` (`firmware/include/Controllers.h`), independently built
on first call from `resolveCalibration()` at a point `setup()` chooses — which
is what gives a flash-loaded calibration somewhere to land. The original
description follows, for context.

In `firmware/src/controllers/MotionController.cpp`, at file scope (not class
members):

```cpp
MagnetModel magnets[3] = { ... };
const Sensor sensors[3] = { ... };
ForwardModel forward_model(sensors, magnets);
Eigen::Matrix<float, 9, 6> J;        // declared, appears unused — dead, check and remove
Eigen::Matrix<float, 9, 1> B_field;  // declared, appears unused — dead, check and remove
```

Every other controller owns its dependencies as class members
(`SensorController` owns its 3 sensor objects as members, for instance). Here
the actual math model — the thing the whole solver pipeline runs against — is
a translation-unit global, built once from `Config` constants at static-init
time, invisible to any header, with no accessor and no way to reconstruct or
mutate it at runtime.

This matters beyond style: it's the reason there's currently no path for a
future calibration write-back (see `TODO/resolved/sensor-gain-calibration.md`) to ever
reach the running `Sensor`/`MagnetModel` instances — they're not reachable
from anywhere calibration code could plug into.

Likely fix shape: `MotionController` (or a new owner, depending on how
`TODO/resolved/sensor-gain-calibration.md` resolves) should own `sensors`, `magnets`,
and `forward_model` as members, constructed from whatever config/calibration
source is decided, with `J`/`B_field` either wired to an actual use or
deleted.

## Problem 3: `BundleCalibrationController` mixes both access patterns — RESOLVED

Closed by dropping the parameter: `update()` now takes only `button_bits` and
calls `sensorController()` itself, matching the `ledController()` call it
already made. This was reconsidered once — the explicit parameter was briefly
read as deliberate, on the strength of a `BundleState.cpp` comment saying it
let the calibrator "be selective in when it wants to read the sensor." But
selectivity never depended on how the controller got its reference, only on
where it chose to call `readUncorrected()`, so the parameter bought nothing the
accessor didn't. The original description follows, for context.

Every controller is reached through its own accessor function (`ledController()`,
`sensorController()`, ...) declared in `Controllers.h` — that's the project's
one consistent access pattern, and all five `State` subclasses use it. But
`BundleCalibrationController` mixes two different ways of getting at its
dependencies: it calls `ledController()` directly from inside `change_phase()`,
while `SensorController` instead comes in as an explicit parameter —
`BundleCalibrationController::update(uint16_t button_bits, SensorController
&sensorController)`, passed in by `BundleState::update()`
(`firmware/src/states/BundleState.cpp`) — even though `sensorController()` is
sitting right there and would work exactly the same way `ledController()`
does. So within this one class the access pattern is inconsistent, with no
apparent reason for the split (e.g. `LEDController` isn't more "shared" or
`SensorController` more "test-isolated" in any way that's evident from the
code).

(An earlier version of this section also flagged `SensorController.cpp`
reaching `MotionController` via its own inline `extern MotionController
motionController;` instead of going through `Controllers.h` like everyone
else. That's now fixed — `SensorController.cpp` includes `Controllers.h` and
calls `motionController()` like everything else does, as part of the same
accessor-function migration that resolved Problem 2.)

## Note

These two problems are linked: fixing #2 (giving the forward model a real
owner) will likely reshape how #1 gets resolved, since "who owns the model"
and "who's allowed to call into the solver during calibration" are the same
question from two directions. Worth designing together rather than
sequentially.

In the event #2 was resolved without touching #1. Giving the model an owner
turned out not to require deciding who may call into the solver — the call in
`updateCalibration()` just got re-spelled as `motionController().read_pose()`
and is as coupled as it ever was. #1 remains open and still belongs with the
tare redesign.

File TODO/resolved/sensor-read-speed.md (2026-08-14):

> **RESOLVED — implemented, archived for the reasoning.**
>
> The whole decision below (Master-Controlled Mode, trigger-on-read via
> `TLx493D_ADC_ON_READ_AFTER_REG_05_e`, bus left at 400kHz) shipped in
> `7d1fb42`, with the read-gap re-trigger added in `26e604d` and the
> first-conversion note in `f2ac71c`. See
> `SensorController::setup_sensor()`/`readUncorrected()`.
>
> The live description is **`ARCHITECTURE.md` → "Sensor read timing"**; this
> file is kept only for the derivation and the datasheet reasoning behind it.
>
> Of the open questions at the bottom, two are answered (the Infineon library
> does expose the trigger bits via `setTrigger()`; the clock stays at 400kHz).
> **One is still genuinely unverified: whether the RP2040 Arduino `Wire`
> implementation honours slave clock stretching.** The design depends on it
> and it has not been checked on hardware — that caveat is carried forward in
> `ARCHITECTURE.md`.

---

# Switch sensors to Master-Controlled Mode for faster, fresher reads

`SensorController` never calls `setPowerMode()`, so all three TLI493D-A2B6
sensors sit in the power-on-reset default: Low Power Mode. `MOD2.PRD` resets
to `0B` ("fast" per the register description) — inferred, not spec-confirmed
against an explicit Hz table, to mean the higher of the datasheet's two
listed rates: 160 Hz, i.e. a worst-case ~6.25ms staleness today regardless of
poll rate. The PCB is fixed/bought: all three sensors' `SCL/INT` pins share
one net wired only to the MCU's plain I2C `SCL` — no `/INT` GPIO, and one
wouldn't help anyway with three sensors converting independently on the same
line. So synchronization has to happen over the I2C bus itself.

## Decision

Move all three sensors to Master-Controlled Mode (`MOD1.MODE = 01B`).
Trigger each conversion with trigger-bits `100B` ("trigger after register
05H") appended to the same read that fetches the previous measurement — one
transaction both retrieves data and re-arms the next conversion. This is
compatible with the driver's existing `CA=0`/`INT=1` config (clock
stretching enabled, /INT disabled, already handling synchronization safely
across the shared bus); only trigger-bits `010B`/`011B` (trigger-before-read)
are excluded with that config, not `100B`. Expected staleness is about one
round-trip across the three sensors — under 1ms, a >6x improvement on
today's ~6.25ms, and accepted as fine for now. It'll creep up as more work
lands on the single core, but that's `TODO/multicore.md`'s problem, not
this one.

## Round shape

1. Read sensor 1, sensor 2, sensor 3 in turn — full register block
   (00H–06H), trigger-bits `100B` on each read. Every read both harvests
   the prior result and re-arms that sensor's next conversion.
2. Check the parity/status bits included in that block; discard/flag
   anything invalid (expected on the very first round after switching
   modes, before any conversion has run yet).
3. Repeat continuously — clock stretching covers the case where a
   conversion isn't quite done by the time its turn comes back around (in
   steady state it should always be done: 3 reads at 400kHz take ~600us,
   longer than the ~175-240us typical conversion time).

## Open questions

- Does the Infineon Arduino library expose the per-frame trigger bits, or
  does this need a raw register write? `getMagneticFieldAndTemperature()`
  may not support it.
- Does the RP2040 Arduino `Wire` library actually honor I2C slave clock
  stretching? Unverified on real hardware, and this design depends on it.
- Keep I2C clock at 400kHz — Master-Controlled Mode doesn't need Fast
  Mode's >=800kHz, and raising it risks signal integrity with 3 sensors
  sharing the bus's fixed 1.2kOhm pull-ups.

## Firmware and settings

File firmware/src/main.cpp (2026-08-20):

#include <Arduino.h>

#include "Config.h"
#include "Controllers.h"
#include "StateMachine.h"

#ifndef PIO_UNIT_TESTING
void setup() {
  // Initialize USB HID first
  hidController().begin();

  // Unconditional: Serial carries the calibration protocol as well as
  // telemetry, so the link has to come up either way -- and the boot
  // diagnostics from resolveCalibration() below need somewhere to land.
  // TelemetryController still decides for itself whether to *print*.
  serialController().begin();

  inputController().begin();
  ledController().begin();

  // Note: this is where the callibration is actually read for the sensor and the motion controller.
  if (!sensorController().begin()) {
    stateMachine.changeState(&StateMachine::errorState);
    return;
  }
  motionController().reset();
  telemetryController().begin();

  stateMachine.changeState(&StateMachine::calibratingState);
}

void loop() {
  hidController().task();
  // Before the state machine, so whichever state is active sees a line on the
  // same tick it finished arriving.
  serialController().update();
  stateMachine.update();
}
#endif

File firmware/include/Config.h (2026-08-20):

#pragma once

#include <Arduino.h>

#include "CalibrationParams.h"
#include "magnet_model/magnet_model_table.h"
#include "magnet_model/positions.h"

namespace Config {

const bool ENABLE_TELEMETRY = true;
const bool statistics = true;

// Hardware pins (XIAO RP2040)
const int PIN_RIGHT_BTN = D0;
const int PIN_LEFT_BTN = D2;
const int PIN_LED_DATA = D3;
const int PIN_LED_LS = D1;
const int PIN_MAG1_LS = D10;
const int PIN_MAG2_LS = D9;
const int PIN_MAG3_LS = D8;

// Samples for calibration offset
const int ZERO_SAMPLES = 200;

// AXES:
// X axis - side to side    through the buttons
// Y axis - front to back   through the USB-C port
// Z axis - vertical        through the centre nob axis of symmetry

// Gains and sign fixes
// translation gains     X,    Y,    Z      
// in 'points' per mm             
const float GAIN_T[3] = {80.0, 80.0, 100.0};
// rotation gains        Rx,   Ry,   Rz
// in 'points' per degree
const float GAIN_R[3] = {15, 15, 15};
// signs are for:         X,   Y,  Z, Rx, Ry, Rz
const int SIGN_AXIS[6] = {+1, -1, +1, -1, -1, -1};

// Dead zones in 'points
const float DEAD_T = 18.0;
const float DEAD_R = 14.0;

// Smoothing
const float SMOOTH_TAU_S = 0.08;

// Final axis output range
const float AXIS_LIMIT = 350.0;

// RGB LEDs
const int LED_COUNT = 8;
const int LED_BRIGHTNESS = 40;
const unsigned long LED_IDLE_COLOR = 0x00FF00;
const unsigned long LED_CALIBRATING_COLOR = 0x0000FF;
const unsigned long LED_ERROR_COLOR = 0xFF0000;

// FSM timing
const long IDLE_SLEEP_TIMEOUT_MS = 2 * 60 * 1000;

constexpr float magnet_gains[3] = {-0.96, -1.2, -0.98};

// Per-sensor XYZ offset, in mT, subtracted after the gain matrix is applied
// (i.e. in read_mT()'s output space, not raw sensor counts).
constexpr float sensor_offset_mT[3][3] = {
  {0.1f,  -1.4f, 0.0f},
  {-1.6f, -0.2f, 0.0f},
  {0.0f,   0.0f, 0.0f},
};

// The constants above, assembled into the struct the rest of the firmware
// actually consumes. This is the fallback used when there is no calibration
// stored on the device, so it has to stand on its own as a working (if
// uncalibrated) unit -- identity magnet rotations and unit magnet strengths,
// with magnet positions taken from the nominal CAD geometry in positions.h.
//
// A genuine compile-time constant: CalibrationParams is plain data and every
// input here is constexpr, so this is constant-initialised into flash rather
// than built on each of the two calls resolveCalibration() makes at boot.
//
// Spelled out rather than loop-filled so the shape is readable against the
// struct, and so it matches what export.py's format_cpp() emits for a fitted
// calibration -- default and fitted now read alike.
constexpr CalibrationParams defaultCalibration = {
    // sensor_gain: a scalar gain per sensor, i.e. no cross-axis skew. The
    // full 3x3 only ever comes from a real bundle calibration.
    {
        {{magnet_gains[0], 0.0f, 0.0f},
         {0.0f, magnet_gains[0], 0.0f},
         {0.0f, 0.0f, magnet_gains[0]}},
        {{magnet_gains[1], 0.0f, 0.0f},
         {0.0f, magnet_gains[1], 0.0f},
         {0.0f, 0.0f, magnet_gains[1]}},
        {{magnet_gains[2], 0.0f, 0.0f},
         {0.0f, magnet_gains[2], 0.0f},
         {0.0f, 0.0f, magnet_gains[2]}},
    },

    // sensor_offset_mT
    {
        {sensor_offset_mT[0][0], sensor_offset_mT[0][1], sensor_offset_mT[0][2]},
        {sensor_offset_mT[1][0], sensor_offset_mT[1][1], sensor_offset_mT[1][2]},
        {sensor_offset_mT[2][0], sensor_offset_mT[2][1], sensor_offset_mT[2][2]},
    },

    // magnet_pos_knob: nominal CAD geometry, bottom-face reference.
    {
        {Positions::magnet_knob[0][0], Positions::magnet_knob[0][1], Positions::magnet_knob[0][2]},
        {Positions::magnet_knob[1][0], Positions::magnet_knob[1][1], Positions::magnet_knob[1][2]},
        {Positions::magnet_knob[2][0], Positions::magnet_knob[2][1], Positions::magnet_knob[2][2]},
    },

    // magnet_rotation: identity, i.e. no fitted tilt.
    {
        {{1.0f, 0.0f, 0.0f}, {0.0f, 1.0f, 0.0f}, {0.0f, 0.0f, 1.0f}},
        {{1.0f, 0.0f, 0.0f}, {0.0f, 1.0f, 0.0f}, {0.0f, 0.0f, 1.0f}},
        {{1.0f, 0.0f, 0.0f}, {0.0f, 1.0f, 0.0f}, {0.0f, 0.0f, 1.0f}},
    },

    // magnet_strength_mT: BICUBIC_FIELD_REFERENCE_MT, not a placeholder. It
    // makes magnet_strength_mT[i] / BICUBIC_FIELD_REFERENCE_MT exactly 1.0,
    // i.e. "no separate strength correction", because magnet_gains above is a
    // hand-tuned scalar that already carries the entire field scale -- these
    // defaults are in the gain-carries-scale gauge, not the fit's det(G)=1
    // one. See CalibrationParams.h.
    {BICUBIC_FIELD_REFERENCE_MT, BICUBIC_FIELD_REFERENCE_MT, BICUBIC_FIELD_REFERENCE_MT},
};

}  // namespace Config

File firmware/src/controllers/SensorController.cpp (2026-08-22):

#include "controllers/SensorController.h"
#include "Config.h"
#include "Controllers.h"


using namespace ifx::tlx493d;

namespace {
// Sensor gain is fit as a diagonal matrix now (design documentation/
// bundle-calibration-forward-model-relation.md §4) -- the off-diagonal
// entries in a stored CalibrationParams are not a fitted quantity and must
// not be read, even though the struct still has room for them.
Mat3 toDiagMat3(const float m[3][3]) {
  return Mat3(m[0][0], 0.0f,    0.0f,
              0.0f,    m[1][1], 0.0f,
              0.0f,    0.0f,    m[2][2]);
}
}  // namespace

SensorController::SensorController(const CalibrationParams& cal)
    : mag1Sensor_(Wire, TLx493D_IIC_ADDR_A0_e),
      mag2Sensor_(Wire, TLx493D_IIC_ADDR_A0_e),
      mag3Sensor_(Wire, TLx493D_IIC_ADDR_A0_e),
      sensor_gain_{
        toDiagMat3(cal.sensor_gain[0]),
        toDiagMat3(cal.sensor_gain[1]),
        toDiagMat3(cal.sensor_gain[2]),
      },
      sensor_offset_mT_{
        toVec3(cal.sensor_offset_mT[0]),
        toVec3(cal.sensor_offset_mT[1]),
        toVec3(cal.sensor_offset_mT[2]),
      } {}

void SensorController::powerOff(int pin) { digitalWrite(pin, LOW); }

void SensorController::powerOn(int pin) {
  digitalWrite(pin, HIGH);
  delay(5);
}

bool SensorController::setup_sensor(ifx::tlx493d::TLx493D_A2B6& sensor, int pin, TLx493D_IICAddressType_t address) {
  SensorController::powerOn(pin);
  bool res = sensor.begin(true, false, true, true);
  sensor.printRegisters();
  if (!res) {
    Serial.println("Failed to initialize sensor!");
    return false;
  }
  res = sensor.setIICAddress(address);
  if (!res) {
    Serial.println("Failed to set sensor I2C address!");
    return false;
  }
  res = sensor.setSensitivity(TLx493D_FULL_RANGE_e);
  if (!res) {
    Serial.println("Failed to set sensor sensitivity!");
    return false;
  }
  res = sensor.setPowerMode(TLx493D_MASTER_CONTROLLED_MODE_e);
  if (!res) {
    Serial.println("Failed to set sensor power mode!");
    return false;
  }
  res = sensor.setTrigger(TLx493D_ADC_ON_READ_AFTER_REG_05_e);
  if (!res) {
    Serial.println("Failed to set sensor trigger mode!");
    return false;
  }
  // No conversion is running yet at this point (Master-Controlled Mode
  // starts powered down until triggered). That's fine: readUncorrected()
  // detects the gap since its last call and re-triggers before reading for
  // real whenever it's been more than 100ms, which covers this first-ever
  // read too.
  delay(10);
  return true;
}

bool SensorController::begin() {
 
  pinMode(Config::PIN_MAG1_LS, OUTPUT);
  pinMode(Config::PIN_MAG2_LS, OUTPUT);
  pinMode(Config::PIN_MAG3_LS, OUTPUT);

  // All three rails are pulled high in hardware, so force them all off first
  // before bringing sensors up one-by-one for address assignment.

  powerOff(Config::PIN_MAG1_LS);
  powerOff(Config::PIN_MAG2_LS);
  powerOff(Config::PIN_MAG3_LS);
  delay(5);

  
  Wire.begin();
  Wire.setClock(400000);

  powerOn(Config::PIN_MAG1_LS);

  bool res;
  res = setup_sensor(mag1Sensor_, Config::PIN_MAG1_LS, TLx493D_IIC_ADDR_A2_e);
  if (not res) {
    Serial.println("Failed to setup sensor 1!");
    return false;
  }
  res = setup_sensor(mag2Sensor_, Config::PIN_MAG2_LS, TLx493D_IIC_ADDR_A1_e);
  if (not res) {
    Serial.println("Failed to setup sensor 2!");
    return false;
  }
  res = setup_sensor(mag3Sensor_, Config::PIN_MAG3_LS, TLx493D_IIC_ADDR_A0_e);
  if (not res) {
    Serial.println("Failed to setup sensor 3!");
    return false;
  }
  // Bring-up chatter, only useful to someone reading the port. The failures
  // above stay unconditional -- a sensor that did not come up needs to say so
  // whether or not telemetry is on.
  if (Config::ENABLE_TELEMETRY) {
    Serial.println("All sensors initialized successfully.");
    Serial.println("sensor1 has valid data: " + String(mag1Sensor_.hasValidData()));
    Serial.println("sensor2 has valid data: " + String(mag2Sensor_.hasValidData()));
    Serial.println("sensor3 has valid data: " + String(mag3Sensor_.hasValidData()));

    Serial.println("sensor1 I2C address: " + String(mag1Sensor_.getI2CAddress()));
    Serial.println("sensor2 I2C address: " + String(mag2Sensor_.getI2CAddress()));
    Serial.println("sensor3 I2C address: " + String(mag3Sensor_.getI2CAddress()));
  }
  return true;
}

// The sensors run in Master-Controlled Mode with trigger-on-read (set up
// once per sensor in setup_sensor() via setPowerMode()/setTrigger()): every
// getMagneticFieldAndTemperature() call both returns the previous
// measurement and re-arms the next conversion as a side effect. Clock
// stretching (the driver's default CA=0/INT=1 config) makes a read block
// for as long as its conversion is still running, so cycling through the 3
// sensors back-to-back keeps each one's data fresh with no manual delay --
// see ARCHITECTURE.md's "Sensor read timing" for the full design.
//
// That self-triggering only works if reads keep happening often enough. If
// nobody has called this in a while, the sensor's last-armed conversion
// finished long ago and is just sitting there stale. So if it's been more
// than 100ms since the last call (including never, at first boot), throw
// away one round of reads first purely to re-trigger a fresh conversion per
// sensor, then read for real below -- clock stretching makes that second
// read wait for the fresh conversion instead of returning the stale one.
void SensorController::readUncorrected(float out[9]) {
  const unsigned long now = millis();
  if (now - lastReadMs_ > 100) {
    double dx = 0, dy = 0, dz = 0, dt = 0;
    mag1Sensor_.getMagneticFieldAndTemperature(&dx, &dy, &dz, &dt);
    mag2Sensor_.getMagneticFieldAndTemperature(&dx, &dy, &dz, &dt);
    mag3Sensor_.getMagneticFieldAndTemperature(&dx, &dy, &dz, &dt);
  }
  lastReadMs_ = now;

  double mag1x = 0, mag1y = 0, mag1z = 0, temp1 = 0;
  double mag2x = 0, mag2y = 0, mag2z = 0, temp2 = 0;
  double mag3x = 0, mag3y = 0, mag3z = 0, temp3 = 0;

  bool res_1 = mag1Sensor_.getMagneticFieldAndTemperature(&mag1x, &mag1y, &mag1z, &temp1);
  bool res_2 = mag2Sensor_.getMagneticFieldAndTemperature(&mag2x, &mag2y, &mag2z, &temp2);
  bool res_3 = mag3Sensor_.getMagneticFieldAndTemperature(&mag3x, &mag3y, &mag3z, &temp3);

  // MAG1 = bottom, MAG2 = top left, MAG3 = top right.
  out[0] = mag1x;
  out[1] = mag1y;
  out[2] = mag1z;
  out[3] = mag2x;
  out[4] = mag2y;
  out[5] = mag2z;
  out[6] = mag3x;
  out[7] = mag3y;
  out[8] = mag3z;
}

void SensorController::read_mT(float out[9]) {
  float uncorrected[9];
  readUncorrected(uncorrected);

  for (int i = 0; i < 3; i++) {
    Vec3 corrected = sensor_gain_[i] * Vec3(uncorrected[i * 3 + 0], uncorrected[i * 3 + 1], uncorrected[i * 3 + 2])
                      - sensor_offset_mT_[i];
    out[i * 3 + 0] = corrected(0);
    out[i * 3 + 1] = corrected(1);
    out[i * 3 + 2] = corrected(2);
  }
}
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

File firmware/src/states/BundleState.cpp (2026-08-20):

#include "states/BundleState.h"

#include <Arduino.h>

#include "Config.h"
#include "Controllers.h"
#include "StateMachine.h"
#include "animations/Animations.h"

void BundleState::enter() {
    InputController& input = inputController();
    ledController().set(SpinnerAnimation(ledController().ring(), 0xFDFDFF));
    input.takeActivity();
    input.takeCalibrationRequest();

    // CalibratingState only gets us here by consuming a CAL_START, so the
    // command itself is already gone. Kick the run off directly instead of
    // waiting for a second one -- this also resets current_step, so a repeat
    // calibration works without a reboot.
    bundleCalibrationController().start();
}

void BundleState::update() {
    InputController& input = inputController();
    BundleCalibrationController& bundleCalibration = bundleCalibrationController();

    ledController().update();
    input.update();

    // Non-blocking, and only dispatched when a line actually arrived, so an
    // idle tick with nothing waiting never hands the controller a zeroed
    // buffer or stalls the loop. The controller decides whether a command
    // ends calibration.
    const char* command = serialController().takeLine();
    if (command != nullptr && bundleCalibration.handle_serial_command(command)) {
        stateMachine.changeState(&StateMachine::idleState);
        return;
    }

    uint16_t button_bits = input.takeActivity();
    bundleCalibration.update(button_bits);

    // Deliberately no exit on "all steps captured". The knob holds in
    // AWAITING_UPLOAD so the host can solve and hand the result straight back;
    // dropping to idle here meant the user had to walk it back into
    // calibration mode to receive a calibration it had just finished
    // capturing for. Leaving is now CAL_ABORT, or the reboot after
    // CAL_UPLOAD.
}

void BundleState::exit() {}

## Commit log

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2026-08-02 Add TODO for switching magnetic sensors to Master-Controlled Mode
    Tracked as issue #11 in ARCHITECTURE.md, matching the convention there:
    SensorController never sets a sensor power mode, so all three sensors sit
    in power-on-reset Low Power Mode (10/160 Hz update ceiling) regardless of
    poll rate.
    TODO/sensor-read-speed.md captures the design worked out for reading the
    TLI493D-A2B6 sensors faster: staggered trigger writes followed by a
    separate read pass, relying on the existing clock-stretching config
    (CA=0/INT=1) instead of the shared SCL/INT line for synchronization,
    since the PCB is fixed and can't be changed.
    Claude-Session: https: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
2026-08-02 Rewrite sensor-read-speed TODO: trigger-on-read, real staleness, trim
    Fixes three problems with the previous version of this TODO:
    - Design was wrong: it described a separate staggered trigger-write step
    plus a separate read pass. The actually-accepted design is simpler:
    trigger-bits 100B piggybacked on the same read that fetches the prior
    measurement, so one transaction both harvests data and re-arms the next
    conversion.
    - The current-staleness claim was vague ("10 Hz or 160 Hz" without
    resolving which applies) and understated the problem. MOD2.PRD resets to
    0B ("fast"), which by naming should mean the higher listed rate
    (160 Hz) -- stated now as a concrete ~6.25ms worst case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
2026-08-02 Switch magnetic sensors to Master-Controlled Mode with trigger-on-read
    Implements TODO/sensor-read-speed.md: sensors were sitting in their
    power-on-reset Low Power Mode (~6.25ms worst-case staleness) because
    setup_sensor() never configured a power mode. Now sets each sensor to
    Master-Controlled Mode and enables trigger-on-read-after-reg-05H, so
    every normal getMagneticFieldAndTemperature() read also re-arms the
    next conversion as a side effect -- no changes needed to the read path
    itself (readUncorrected()/read_mT() and all their call sites).
    Not able to verify this compiles in this environment: PlatformIO's
    toolchain download is blocked by the sandbox's network policy. The
    method names and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
    [SensorController.cpp]
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2026-08-03 Rework bundle calibration math: fix non-identifiability and O(n_frames^2) fit cost
    Root-caused the first real fit against hardware data: it "converged" via a
    stalled xtol after 12 iterations with cost barely moving, while first-order
    optimality stayed ~222 - a false convergence caused by unscaled parameters
    (mm vs rad vs dimensionless) plus a dense finite-difference Jacobian that
    re-evaluated every frame's residual per perturbed unknown (O(n_frames^2)).
    Changes:
    - Drop sensor_pos as a calibrated offset (degenerate with per-frame
    translation); keep it fixed at nominal.
    - Add real cross-magnet field summation (each sensor now sees all 3
    magnets, not just its nominally-paired one).
    - Repla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
    [bundle_geometry.py, bundle_params.py, calibration_algorithm.py]
2026-08-03 Restrict bicubic stencil to remove per-fetch bounds checking
    Clamp i0/j0 to [1, NR-3]/[1, NZ-3] instead of [0, NR-2]/[0, NZ-2] so
    the 4-point stencil always lands entirely inside the real grid. This
    removes point_or_ghost/raw (and their branchy bounds checks + border
    extrapolation) in favor of 16 unconditional indexed loads per
    evaluate() call. The outermost ring of the grid is no longer used as
    an interpolation interval, only as stencil context.
    Also drops the free-function duplicates of iclamp/clampF/ifloor that
    were dead code (evaluate/raw already resolved to the class-member
    versions declared in the header, not these).
2026-08-03 Hoist bicubic basis weights and linearize boundary extrapolation
    cubic()/cubic_deriv() were each called once per row (8 calls total)
    with the same t, recomputing the same coefficient algebra per row.
    Reassociate so the t-dependence collapses into 4 scalar weights
    computed once per axis, turning each row into a 4-term dot product
    (~9 multiplies per component per row down to ~4).
    Also replace cubic extrapolation outside the bounding box with linear
    extrapolation: clamp t to [0,1], evaluate the weights there, and add
    the overshoot times the weight derivative. Since the result is a
    linear combination of the stencil nodes with scalar weights,
    extrapolating the weights is equivalent to extrapolat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
2026-08-03 Exploit r=0 axis symmetry instead of clamping it away
    The r-axis stencil clamp (i0 >= 1) made the patch touching the physical
    symmetry axis (r in [0, dr)) unreachable, forcing it into the linear
    extrapolation fallback - a rough approximation exactly where the tracked
    object is often closest to the magnet's center.
    Allow i0 down to 0 and, only for that patch, fetch the stencil's missing
    virtual node (column -1, r=-dr) as the mirror of column 1: Br is odd and
    Bz is even in r for an axisymmetric field, so the mirror is the exact
    field value there, not an approximation. This recovers full bicubic
    accuracy at the axis and, as an emergent property of the mirrored
    stencil, yields Br(0,z)=0 and dBz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
2026-08-03 Add static_assert that BICUBIC_ORIGIN.r is exactly 0
    The axis_patch mirror in evaluate() assumes grid column 0 coincides
    with the physical symmetry axis (r=0); if the origin ever moved off
    0 this would silently mirror around the wrong point instead of
    failing loudly. Pin it down at compile time.
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2026-08-04 Rewrite bundle calibration: fix frame conventions, analytic Jacobian, staged fit
    The calibrator was returning physically impossible parameters (sensor gains of
    2.3, magnet strengths of 2.6) and taking minutes to do it. Two convention bugs
    were the root cause, and neither was expressible by the old parameterization,
    so the fit had no way to reach a sensible answer:
    - Magnet position reference. field_approximation.ipynb builds the firmware's
    bicubic table with the cylinder's BOTTOM FACE at the origin, which is what
    positions.h's magnet positions mean. magpylib positions a cylinder by its
    centre, so the Python model sat 3mm off and predicted a field ~3x too strong
    at rest.
    - Sensor gai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
    [bundle_geometry.py, bundle_params.py, calibration_algorithm.py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]
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2026-08-04 Fix the pose gauge explicitly instead of leaning on priors
    A global translation or rotation of the magnet trio is exactly cancelled by a
    compensating per-frame pose change - m_j -> Q m_j with R_n -> R_n Q^T leaves
    R_n Q^T Q m_j untouched - so 6 of the 9 raw magnet coordinates carry no
    information at all. Previously the magnet_pos prior held those directions down
    by accident, which meant it was doing two unrelated jobs at once and neither
    could be tuned without disturbing the other.
    MAGNET_POS_BASIS now removes them by construction, via three constraints:
    zero mean offset (kills translation), all z offsets equal (makes the triangle's
    plane horizontal, killing pitch and roll), and zero net ya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
    [bundle_geometry.py]
2026-08-04 Record the real justification for the magnet position prior
    The knob is 3D printed, and a few tenths of a millimetre is a well-founded
    statement about that process - which is what makes this prior worth keeping
    even though the explicit gauge fix means the fit no longer depends on it.
    The previous comment said "press-fit/glued", which was a guess.
    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
    [bundle_params.py]
2026-08-04 Refactor bundle calibration for clarity, organization, and typing
    Consolidates the calibration parameter layout into a single owned module
    (parameterization.py) instead of three scattered, hand-maintained copies of
    the same mapping, and cuts machinery that ablation testing showed wasn't
    earning its complexity:
    - Structural gauge fix: GAIN_BASIS is now built only from traceless basis
    matrices, so det(gain)=1 holds automatically to second order for any
    parameter value. Removes the runtime gauge-transfer stage and its special
    casing; magnet_strength is free from the start of the fit instead of a
    final phase.
    - Single joint solve replaces the 3-stage warm-started ladder, after
    ablatio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
    [bundle_geometry.py, bundle_params.py, calibration_algorithm.py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]
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2026-08-05 Redo --emit-cpp against the refactored calibration and CalibrationParams
    The rebase onto the bundle-calibration refactor (ea5ca10) dropped all of
    this branch's prior edits to magnet_field_model/calibration/export.py, so
    it reverted to its pre-CalibrationParams shape: flat inline constants
    (inline const Mat3 sensor_gain[3], etc.) targeting the old scattered
    Config.h/positions.h constants, with a magnet_strength note pointing at a
    gauge-transfer step (renormalize_gauge) that the refactor also removed.
    Rebuilding format_cpp() from scratch against both the new calibration API
    and the current CalibrationParams struct.
    Two things changed under the refactor that make this simpler than before,
    not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
    [export.py]
2026-08-05 Make the generated fittedCalibration() inline
    Reported from real use: pasting the generated snippet produced a linker
    error, "multiple definition of Config::fittedCalibration()", across every
    translation unit in the firmware. The snippet had landed in a header
    (Config.h is included nearly everywhere), and a plain non-inline free
    function compiled into more than one .o is exactly that error -- nothing
    about the paste location was wrong, the generator just assumed a single
    .cpp file it can't actually guarantee.
    There is no way for format_cpp() to control where its output gets pasted,
    so make the output correct either way: inline is the standard C++ answer
    (one definition permitted per transla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
    [export.py]
2026-08-05 Fit against the firmware's single-magnet model, not the complete one
    Reported from hardware: applying a fresh calibration made the pose residual
    worse, ~1% -> ~3%, and the error grew as the knob lifted away from the
    sensors.
    Not a sign or frame error. Verified the export direction is right: feeding
    the fit's own exact prediction back through firmware_sensor_gain/offset
    recovers the fit's internal field to 1e-15 (the o_fit terms cancel exactly,
    which is why the minus in `G_fw @ raw - o_fw` is load-bearing), and the C++
    ForwardModel matches the Python model to 0.0008% once compared like for like.
    The real cause is a model mismatch. bundle_geometry sums over all three
    magnets per sensor; Forw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
    [bundle_geometry.py]
2026-08-07 Replace controller globals and CalibratedControllers with independent accessors
    Every controller is now reached through its own accessor function instead of
    a mix of bare extern globals and a shared CalibratedControllers struct. The
    5 default-constructible controllers keep static-init construction, just
    behind a plain reference-returning function; sensorController() and
    motionController() are true Meyers singletons, each independently resolving
    its own calibration. No aggregate struct anywhere, so no shared construction
    moment forces an ordering decision between controllers.
    Claude-Session: https://claude.ai/code/session_01EJicMGCXfB2i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
    [BundleState.cpp, CalibratingState.cpp, Controllers.cpp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]
2026-08-07 Change callibration sigmas + Minor tweaks
    Removed inline on the fittedCallibration, added and fixed comments,
    and reduced the usage of single-letter variables.
    Tweaking the callibration sigmas changes the room the callibration
    system has to find these parameters.
    [Config.h, bundle_params.py, export.py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]
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2026-08-07 Fix leftover inline-removal cleanup in export.py
    Dropping inline from fittedCalibration() left the function signature with a
    stray 2-space indent and a broken docstring sentence, and the test still
    asserted the old "inline ..." string it was supposed to match against.
    [export.py]
2026-08-08 Store the fitted calibration on LittleFS
    Stage 1 left resolveCalibration() returning Config::defaultCalibration()
    with a note pointing at LittleFS. This fills that in, so a fit can reach a
    device without editing Config.cpp and reflashing.
    CalibrationStorage persists CalibrationParams to /calibration.bin: 312
    bytes of "CMK2" magic, a version, 75 little-endian float32s, and a CRC-32.
    Matrices are stored row-major through Eigen coefficient accessors rather
    than memcpy'd off the struct, so the format does not encode the fact that
    Matrix3f is column-major internally and the Python side stays a .ravel().
    Validation is all-or-nothing, which follows from the gauge note in
    CalibrationParams.h: sens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
    [BundleCalibrationController.cpp, BundleState.cpp, CalibratingState.cpp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]
2026-08-08 Make the stored calibration a plain struct copy
    CalibrationStorage was doing work it did not need to. serialize() was dead —
    defined, declared, never called, because the firmware never turns a
    CalibrationParams into bytes; the host does. deserialize() was ~50 lines of
    readU32 calls, a per-float bit test and five nested loops copying into Eigen
    coefficient accessors, all to avoid depending on a layout that is already
    fixed at 300 bytes. Reading a calibration is now: check magic, version and
    CRC, memcpy the payload into the struct, range-check it. 116 lines out, 40 in.
    That needed CalibrationParams to stop holding Eigen types. Eigen::Matrix
    declares a user-provided copy constructor, so Matr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
    [BundleCalibrationController.cpp, BundleState.cpp, CalibrationStorage.cpp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]
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2026-08-10 Address PR review, and rework the calibration flow
    Review comments, in order:
    defaultCalibration is now a constexpr CalibrationParams rather than a
    function. The comment claiming it had to stay a function because the
    positions were Eigen constants in another translation unit was a real
    leftover, so positions.h gains constexpr float magnet_knob[3][3] as the
    primary definition with the Vec3s derived from it — one set of numbers, and
    no dynamic initialisation in the way. Written as an initialiser list rather
    than for-loops, matching what format_cpp() emits. Config.cpp held nothing
    else and is gone.
    Serial's delay(1000) is gated on ENABLE_TELEMETRY — it exists so a human
    watching the port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
    [BundleCalibrationController.cpp, BundleState.cpp, CalibrationStorage.cpp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]
2026-08-10 Drop the REVIEW calibration phase
    A successful CAL_ACK now advances straight to the next step's
    WAIT_FOR_START_BTN (or AWAITING_UPLOAD after the last step) instead of
    pausing in REVIEW for a second button press. There was never a way to
    go back and redo a step, so REVIEW's "press to continue" had nothing
    to decide -- it only cost an extra press per step, which combined with
    WAIT_FOR_START_BTN's own press requirement was the "two presses to
    move on" behavior. The InputController grace-window edge fix from the
    previous round is kept as-is.
    [BundleCalibrationController.cpp, protocol.py, session.py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]
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2026-08-10 Rework LED ring animations into AnimationBase subclasses
    Introduce an AnimationBase abstract class (mirroring the existing State
    pattern) with Solid/Spinner/Off animations as concrete subclasses, each
    owning its own per-tick timing state. LEDController shrinks to owning the
    ring and a single statically-allocated tagged-union slot for whichever
    animation is active (no heap allocation) — callers construct the animation
    they want and load it via LEDController::set(...), then drive it with
    update().
    Wire a placeholder spinner through BundleCalibrationController's phase
    transitions so calibration shows something during each phase, and document
    the still-undesigned per-phase/per-step animations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
    [BundleCalibrationController.cpp, BundleState.cpp, CalibratingState.cpp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]
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2026-08-10 Replace hand-rolled animation union with std::variant
    AnimationSlot's manual placement-new/tag/pointer-dispatch machinery is
    gone. LEDController now stores the active animation in a
    std::variant<SolidAnimation, SpinnerAnimation, OffAnimation>, loaded through
    a single set() (a template, so callers still pass a concrete animation
    directly with no explicit conversion) and dispatched via std::visit instead
    of a raw AnimationBase* into union storage.
    set() uses variant::emplace<T>() rather than assignment: AnimationBase holds
    a reference member, which makes the concrete animation types
    move-constructible but not move-assignable, so std::variant's operator= is
    implicitly deleted for this alternat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
    [LEDController.cpp]
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2026-08-10 Speed up solve_knob_pose: hot start, solver algebra, micros() timing
    Non-interpolation optimisation pass. BicubicField and the field table are
    untouched.
    Instrumentation
    - Solve timing moves from millis() to micros(). At ~7.5ms per call the
    millisecond clock quantised at +/-13%, coarser than most of the changes
    worth measuring. Statistics::time_tot/n_time become uint32_t, since a
    signed int of microseconds overflows in about an hour at 80Hz, and
    reset() now clears them, which it previously did not.
    Hot start
    - The rotation was reset to identity on every frame, under a TODO saying
    not to, while the translation was hot-started. The solver therefore
    re-converged the rotation from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
    [SensorController.cpp]
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2026-08-10 Move Euler extraction out of read_pose; guard R against drift
    read_pose() previously computed both the solved pose (position, rotation
    matrix) and a Euler-degrees reporting representation in one call, output
    via a fourth out-param. Split those apart: read_pose now purely solves,
    returning position/R; both callers (MotionController::compute() and
    SensorController's calibration path) already do further processing on
    the result and now call the newly-declared extract_angles_robust(R)
    themselves. Simpler signature, and callers that don't want the Euler
    conversion no longer pay for it.
    Doing this surfaced a real correctness question: since the previous
    commit made R persistent hot-started state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
    [SensorController.cpp]
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2026-08-11 Resolve three finished TODOs, fix stale claims, rework multicore plan
    Re-checked every TODO against the code rather than against its own prose.
    Three were describing work that had already landed:
    - sensor-read-speed.md: the entire decision (Master-Controlled Mode,
    trigger-on-read, 400kHz) was implemented in 7d1fb42 eleven minutes after
    the TODO was rewritten, in the same session, touching only
    SensorController.cpp. The TODO still opened with "SensorController never
    calls setPowerMode()". Deleted; the design and its two live caveats
    (unverified clock-stretching dependency, the >100ms re-trigger path) are
    now an ARCHITECTURE.md section next to the controller table.
    - controller-ow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
    [SensorController.cpp]
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2026-08-14 Final manual run-through of these documents.
    Handled a few minor things that came up immediately myself.
    Fixing the SensorController being passed as a paramter deleting an old
    unused dummy test file. And some other things.
    Dropping the SensorController parameter left behind the two comments that
    existed only to explain it. BundleState.cpp still announced that it passes the
    controller, directly above the call that stopped passing it, and
    TODO/resolved/controller-ownership.md cited that same comment as evidence the
    parameter was deliberate -- contradicting its own summary block, which says
    the problem was closed by removing it. Both corrected here, along with the
    now-unused SensorController.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
    [BundleCalibrationController.cpp, BundleState.cpp, SensorController.cpp]
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2026-08-15 Fit the physically complete model now that the firmware runs it
    SENSOR_MAGNET_COUPLING goes back to ALL_MAGNETS. It was pinned to
    PAIRED_ONLY to match a firmware that could not model cross-talk; that
    match is what mattered, and the firmware now models it, so the workaround
    has nothing left to work around.
    What it cost while it was in place was the absolute field scale.
    Cross-talk is what separates magnet strength from magnet distance -- a
    strength change scales the near and far contributions equally, a z-shift
    changes them at very different rates -- so without it the two are
    near-degenerate over the ~3mm of heave the hardware gives.
    One test moved, and it is worth reading as a result rathe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
    [bundle_geometry.py]
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2026-08-18 Full refactor of the forward-model call chain.
    Human review and changes of the forward model call chain.
    This refactor should have no computational effect at all.
    Fixed a few old issues. But mostly worked on making the code
    understandable to myself. That includes renaming variables to make the
    frame they are in clearer, and changing the comments to be more human
    readable.
    [IdleState.cpp]
2026-08-18 Port the BLA/-O3/-ffinite-math-only optimization work onto experimental's cross-magnet refactor
    origin/experimental added cross-magnet interference modeling (every sensor
    sees all three magnets by superposition -- its own via the near-field
    bicubic table, the other two as point dipoles) entirely against Eigen,
    independently of the earlier Eigen->BasicLinearAlgebra migration and
    hand-unrolling-removal work on this branch's prior history. Re-derived that
    work on top of the new code rather than mechanically rebasing it: read the
    refactor, ported it onto BLA using the idioms the original migration already
    established, and re-measured every hand-unrolling decision fresh instead of
    assuming old nu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
    [CalibrationStorage.cpp, SensorController.cpp]
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2026-08-19 Fix immediate comments on PR.
    [Config.h, SensorController.cpp]
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2026-08-19 Strip historical-comment narration from existing code
    A sweep of every .cpp/.h file outside the vendored BLA library for the
    "used to"/"no longer"/"this replaces" pattern CLAUDE.md's new "code comments
    describe the present, not the past" rule targets, applied to pre-existing
    comments the rule wasn't around to catch when they were written. Each is
    rewritten to state the current invariant/behavior directly; nothing about
    the code itself changed.
    [BundleState.cpp, CalibratingState.cpp, CalibrationStorage.cpp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]
2026-08-20 Fix incorrect and stale comments found in correctness review
    Sweep of every firmware comment for factual accuracy (not just historical
    narration, which the previous pass already covered). CalibratingState.cpp
    claimed CAL_START/CAL_UPLOAD are only accepted in that state, contradicted
    by BundleCalibrationController routing them from BundleState too.
    forward_model.h had R's rotation direction backwards. TelemetryController.cpp's
    kRows comment didn't match its own value. Two comments from this session's
    own earlier fixes overclaimed things not actually true (MotionController.h's
    write-back-path causality, BicubicField.cpp's constexpr codegen claim
    contradicted by this session's own earlier measu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
    [CalibratingState.cpp, CalibrationStorage.cpp, Config.h]
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2026-08-22 Build SensorController's gain matrices from only the stored diagonal
    Sensor gain is now fit as a diagonal matrix (design documentation/
    bundle-calibration-forward-model-relation.md §4), but CalibrationParams
    still stores a full 3x3 per sensor. Reading the off-diagonal entries would
    silently reintroduce cross-axis correction the fit never produces, so
    SensorController now extracts only the diagonal when it builds sensor_gain_.
    CalibrationParams.h itself is untouched -- this only changes how the
    controller reads what's already stored.
    [SensorController.cpp]
